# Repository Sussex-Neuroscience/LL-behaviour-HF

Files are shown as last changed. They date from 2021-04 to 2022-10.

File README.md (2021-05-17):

# LL-behaviour-HF

a behavioural control system for head fixed mice

The task:

- At the start there is a 10 sec interval without a stimulus to record baseline activity. Then the mouse sees a stimulus (always the same drifting grating) which appears randomly either on the left or the right screen. after 5 sec. of stimulus presentation the actuator moves the lick sensors in front of the mouse for two sec. in which the mouse has to report on which side the stimulus is present, hence lick left or right. If the answer is correct a reward is given (solenoid valves). If the answer is incorrect no reward is given. The actuator retracts the lick sensors after 2 sec. either way. Then there is an inter trial interval for 5+ sec before the next stimulus will be presented. If the mouse was incorrect the stimulus will be presented on the same side as the trial before until the mouse makes the correct decision (to avoid bias).I might want to change the timeframes for the different stages depending on how the training goes.

- There will also be a second task where stimuli are presented on both sides on the screen (differing in orientation or contrast) and the animal has to decide which of the stimuli is the correct one. The time course will be the same, it is just the task that is changing.

- The stimulus orientation, size, contrast, frequencies etc. will be different for every mouse but will be the same throughout the training sessions, so there is only 1 type of stimulus in the first task and 2 type of stimuli in the second task. 

- The random stimulus presentation isn't in the code yet. So far, there was no task for the animal, so we always displayed the same stimulus on both sides simultaneously by mirroring one screen to the other. I'll have another chat with Antonio today to see how trivial it is to change that towards what I need.

- As for the scanimage channels. Yes, I was talking about the analog inputs. The DAQ has a lot of free slots left and I guess there are free digital inputs. I'm not too familiar with setting these things up.

- If everything works just using the labjack that would be great. We have an Arduino uno lying around just in case it is needed.

---

schematics on how the system is working and how it should work:

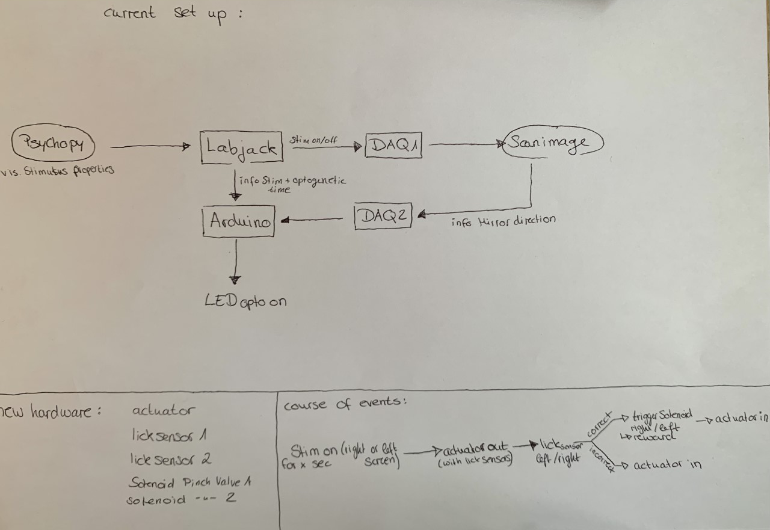
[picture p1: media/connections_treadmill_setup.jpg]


--- 

### notes on implementation:

from what I could gather, Psychopy is not indicated to do millisecond precision of many different variables at once. I had a look on how it deals with timing (more info [here](https://www.psychopy.org/_modules/psychopy/clock.html#Clock)), and thinking that a good route would be to do the behavioural timing critical things on the ESP32.

---

initial bill of materials:

|||
|---|---|
|Linear actuator||
|solenoid valves||
|lick sensors||
|beehive main board||
|beehive peltier board||
|beehive solenoid valve board||
|||

---

software needed to run the esp32
REPL
esp32 micropython firmware
adafruit Ampy

---

notes from the first installation session:

- the Optogenetics LED is controlled by a Thorlabs DC2200 interface. It gets its signals from an arduino box, which in principle can be bypassed since we are already using a microcontroller to take care of the behavioural task.
- from labjack to scanimage there are 2 signals timewave and twoptrigger.

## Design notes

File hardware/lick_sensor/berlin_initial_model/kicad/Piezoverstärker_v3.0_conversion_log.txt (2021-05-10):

#********** START OF run-me-first-from-eagle-sch.ulp ULP Version 4.4.5 06-05-2021 :19:24:03 LOG **********#
    Conversion completed with no Messages
#********** END OF run-me-first-from-eagle-sch.ulp ULP Version 4.4.5 06-05-2021 :19:24:03 LOG **********#

#********** START OF fix_via_hack.ulp ULP Version 4.8.1 06-05-2021 :19:26:07 LOG **********#
TRACK	WireCount=1		Net=+12V				start(X=-126540.000000 Y=46990.000000)	end(X=-131445.000000 Y=1210.000000 )
TRACK	WireCount=2		Net=+12V				start(X=-129540.000000 Y=65870.000000)	end(X=-126540.000000 Y=46990.000000 )
TRACK	WireCount=3		Net=+12V				start(X=-114300.000000 Y=65870.000000)	end(X=-129540.000000 Y=65870.000000 )
TRACK	WireCount=4		Net=+12V				start(X=-79690.000000 Y=88900.000000)	end(X=-114300.000000 Y=65870.000000 )
TRACK	WireCount=5		Net=+12V				start(X=-71440.000000 Y=88900.000000)	end(X=-79690.000000 Y=88900.000000 )
TRACK	WireCount=6		Net=+12V				start(X=-58740.000000 Y=88900.000000)	end(X=-71440.000000 Y=88900.000000 )
TRACK	WireCount=7		Net=+12V				start(X=-39690.000000 Y=88900.000000)	end(X=-58740.000000 Y=88900.000000 )
TRACK	WireCount=8		Net=+12V				start(X=-40960.000000 Y=96520.000000)	end(X=-39690.000000 Y=88900.000000 )
TRACK	WireCount=9		Net=+12V				start(X=-44770.000000 Y=109220.000000)	end(X=-40960.000000 Y=96520.000000 )
TRACK	WireCount=10		Net=+12V				start(X=-26350.000000 Y=109220.000000)	end(X=-44770.000000 Y=109220.000000 )
TRACK	WireCount=11		Net=+12V				start(X=-46140.000000 Y=134620.000000)	end(X=-44770.000000 Y=109220.000000 )
TRACK	WireCount=12		Net=+12V				start(X=-41060.000000 Y=134620.000000)	end(X=-46140.000000 Y=134620.000000 )
TRACK	WireCount=13		Net=+12V				start(X=-57785.000000 Y=48320.000000)	end(X=-58740.000000 Y=88900.000000 )
TRACK	WireCount=14		Net=+12V				start(X=-60960.000000 Y=35560.000000)	end(X=-57785.000000 Y=48320.000000 )
TRACK	WireCount=15		Net=+12V				start(X=-44450.000000 Y=43120.000000)	end(X=-57785.000000 Y=48320.000000 )
TRACK	WireCount=16		Net=+12V				start(X=-30480.000000 Y=43120.000000)	end(X=-44450.000000 Y=43120.000000 )
TRACK	WireCount=17		Net=+12V				start(X=-19685.000000 Y=40335.200000)	end(X=-30480.000000 Y=43120.000000 )
TRACK	WireCount=18		Net=+12VDC_DIRTY				start(X=-71660.000000 Y=46990.000000)	end(X=-131445.000000 Y=6410.000000 )
TRACK	WireCount=19		Net=+12VDC_DIRTY				start(X=-23810.000000 Y=96520.000000)	end(X=-71660.000000 Y=46990.000000 )
TRACK	WireCount=20		Net=+12VDC_DIRTY				start(X=-129220.000000 Y=102870.000000)	end(X=-71660.000000 Y=46990.000000 )
TRACK	WireCount=21		Net=+12VDC_DIRTY				start(X=-118960.000000 Y=121920.000000)	end(X=-129220.000000 Y=102870.000000 )
TRACK	WireCount=22		Net=-12V				start(X=-116380.000000 Y=46990.000000)	end(X=-100965.000000 Y=1210.000000 )
TRACK	WireCount=23		Net=-12V				start(X=-120970.000000 Y=63670.000000)	end(X=-116380.000000 Y=46990.000000 )
TRACK	WireCount=24		Net=-12V				start(X=-122870.000000 Y=63670.000000)	end(X=-120970.000000 Y=63670.000000 )
TRACK	WireCount=25		Net=-12V				start(X=-111440.000000 Y=88900.000000)	end(X=-120970.000000 Y=63670.000000 )
TRACK	WireCount=26		Net=-12V				start(X=-86040.000000 Y=88900.000000)	end(X=-111440.000000 Y=88900.000000 )
TRACK	WireCount=27		Net=-12V				start(X=-54290.000000 Y=88900.000000)	end(X=-86040.000000 Y=88900.000000 )
TRACK	WireCount=28		Net=-12V				start(X=-47940.000000 Y=88900.000000)	end(X=-54290.000000 Y=88900.000000 )
TRACK	WireCount=29		Net=-12V				start(X=-49210.000000 Y=96520.000000)	end(X=-47940.000000 Y=88900.000000 )
TRACK	WireCount=30		Net=-12V				start(X=-51750.000000 Y=109220.000000)	end(X=-49210.000000 Y=96520.000000 )
TRACK	WireCount=31		Net=-12V				start(X=-55460.000000 Y=115570.000000)	end(X=-51750.000000 Y=109220.000000 )
TRACK	WireCount=32		Net=-12V				start(X=-61810.000000 Y=115570.000000)	end(X=-55460.000000 Y=115570.000000 )
TRACK	WireCount=33		Net=-12V				start(X=-21270.000000 Y=109220.000000)	end(X=-51750.000000 Y=109220.000000 )
TRACK	WireCount=34		Net=-12V				start(X=-18730.000000 Y=72560.000000)	end(X=-47940.000000 Y=88900.000000 )
TRACK	WireCount=35		Net=-12V				start(X=-16830.000000 Y=72560.000000)	end(X=-18730.000000 Y=72560.000000 )
TRACK	WireCount=36		Net=-12V				start(X=-30480.000000 Y=48320.000000)	end(X=-18730.000000 Y=72560.000000 )
TRACK	WireCount=37		Net=-12V				start(X=-44450.000000 Y=48320.000000)	end(X=-30480.000000 Y=48320.000000 )
TRACK	WireCount=38		Net=-12V				start(X=-53975.000000 Y=43120.000000)	end(X=-44450.000000 Y=48320.000000 )
TRACK	WireCount=39		Net=-12V				start(X=-15875.000000 Y=30784.800000)	end(X=-30480.000000 Y=48320.000000 )
TRACK	WireCount=40		Net=DIFF_+				start(X=-68160.000000 Y=115570.000000)	end(X=-66460.000000 Y=134620.000000 )
TRACK	WireCount=41		Net=DIFF_+				start(X=-98640.000000 Y=115570.000000)	end(X=-68160.000000 Y=115570.000000 )
TRACK	WireCount=42		Net=DIFF_+				start(X=-128590.000000 Y=63670.000000)	end(X=-98640.000000 Y=115570.000000 )
TRACK	WireCount=43		Net=DIFF_+				start(X=-130490.000000 Y=63670.000000)	end(X=-128590.000000 Y=63670.000000 )
TRACK	WireCount=44		Net=DIFF_+				start(X=-17780.000000 Y=74760.000000)	end(X=-68160.000000 Y=115570.000000 )
TRACK	WireCount=45		Net=DIFF_-				start(X=-74510.000000 Y=115570.000000)	end(X=-61380.000000 Y=134620.000000 )
TRACK	WireCount=46		Net=DIFF_-				start(X=-102020.000000 Y=115570.000000)	end(X=-74510.000000 Y=115570.000000 )
TRACK	WireCount=47		Net=DIFF_-				start(X=-113350.000000 Y=63670.000000)	end(X=-102020.000000 Y=115570.000000 )
TRACK	WireCount=48		Net=DIFF_-				start(X=-115250.000000 Y=63670.000000)	end(X=-113350.000000 Y=63670.000000 )
TRACK	WireCount=49		Net=DIFF_-				start(X=-121920.000000 Y=65870.000000)	end(X=-115250.000000 Y=63670.000000 )
TRACK	WireCount=50		Net=GND				start(X=-128905.000000 Y=1210.000000)	end(X=-130175.000000 Y=1210.000000 )
TRACK	WireCount=51		Net=GND				start(X=-130175.000000 Y=6410.000000)	end(X=-130175.000000 Y=1210.000000 )
TRACK	WireCount=52		Net=GND				start(X=-128905.000000 Y=6410.000000)	end(X=-130175.000000 Y=6410.000000 )
TRACK	WireCount=53		Net=GND				start(X=-97155.000000 Y=6410.000000)	end(X=-128905.000000 Y=6410.000000 )
TRACK	WireCount=54		Net=GND				start(X=-70150.000000 Y=8990.000000)	end(X=-97155.000000 Y=6410.000000 )
TRACK	WireCount=55		Net=GND				start(X=-70150.000000 Y=3390.000000)	end(X=-70150.000000 Y=8990.000000 )
TRACK	WireCount=56		Net=GND				start(X=-69000.000000 Y=2240.000000)	end(X=-70150.000000 Y=3390.000000 )
TRACK	WireCount=57		Net=GND				start(X=-63400.000000 Y=2240.000000)	end(X=-69000.000000 Y=2240.000000 )
TRACK	WireCount=58		Net=GND				start(X=-57150.000000 Y=2240.000000)	end(X=-63400.000000 Y=2240.000000 )
TRACK	WireCount=59		Net=GND				start(X=-70150.000000 Y=15240.000000)	end(X=-70150.000000 Y=8990.000000 )
TRACK	WireCount=60		Net=GND				start(X=-50900.000000 Y=2240.000000)	end(X=-57150.000000 Y=2240.000000 )
TRACK	WireCount=61		Net=GND				start(X=-45300.000000 Y=2240.000000)	end(X=-50900.000000 Y=2240.000000 )
TRACK	WireCount=62		Net=GND				start(X=-44150.000000 Y=3390.000000)	end(X=-45300.000000 Y=2240.000000 )
TRACK	WireCount=63		Net=GND				start(X=-40940.000000 Y=3390.000000)	end(X=-44150.000000 Y=3390.000000 )
TRACK	WireCount=64		Net=GND				start(X=-39790.000000 Y=2240.000000)	end(X=-40940.000000 Y=3390.000000 )
TRACK	WireCount=65		Net=GND				start(X=-44150.000000 Y=8990.000000)	end(X=-44150.000000 Y=3390.000000 )
TRACK	WireCount=66		Net=GND				start(X=-40940.000000 Y=8990.000000)	end(X=-44150.000000 Y=8990.000000 )
TRACK	WireCount=67		Net=GND				start(X=-34190.000000 Y=2240.000000)	end(X=-39790.000000 Y=2240.000000 )
TRACK	WireCount=68		Net=GND				start(X=-70150.000000 Y=21490.000000)	end(X=-70150.000000 Y=15240.000000 )
TRACK	WireCount=69		Net=GND				start(X=-70150.000000 Y=27090.000000)	end(X=-70150.000000 Y=21490.000000 )
TRACK	WireCount=70		Net=GND				start(X=-69000.000000 Y=28240.000000)	end(X=-70150.000000 Y=27090.000000 )
TRACK	WireCount=71		Net=GND				start(X=-63400.000000 Y=28240.000000)	end(X=-69000.000000 Y=28240.000000 )
TRACK	WireCount=72		Net=GND				start(X=-27940.000000 Y=2240.000000)	end(X=-34190.000000 Y=2240.000000 )
TRACK	WireCount=73		Net=GND				start(X=-44150.000000 Y=15240.000000)	end(X=-44150.000000 Y=8990.000000 )
TRACK	WireCount=74		Net=GND				start(X=-40940.000000 Y=15240.000000)	end(X=-44150.000000 Y=15240.000000 )
TRACK	WireCount=75		Net=GND				start(X=-57150.000000 Y=28240.000000)	end(X=-63400.000000 Y=28240.000000 )
TRACK	WireCount=76		Net=GND				start(X=-44150.000000 Y=21490.000000)	end(X=-44150.000000 Y=15240.000000 )
TRACK	WireCount=77		Net=GND				start(X=-40940.000000 Y=21490.000000)	end(X=-44150.000000 Y=21490.000000 )
TRACK	WireCount=78		Net=GND				start(X=-44150.000000 Y=27090.000000)	end(X=-44150.000000 Y=21490.000000 )
TRACK	WireCount=79		Net=GND				start(X=-45300.000000 Y=28240.000000)	end(X=-44150.000000 Y=27090.000000 )
TRACK	WireCount=80		Net=GND				start(X=-40940.000000 Y=27090.000000)	end(X=-44150.000000 Y=27090.000000 )
TRACK	WireCount=81		Net=GND				start(X=-39790.000000 Y=28240.000000)	end(X=-40940.000000 Y=27090.000000 )
TRACK	WireCount=82		Net=GND				start(X=-50900.000000 Y=28240.000000)	end(X=-45300.000000 Y=28240.000000 )
TRACK	WireCount=83		Net=GND				start(X=-34190.000000 Y=28240.000000)	end(X=-39790.000000 Y=28240.000000 )
TRACK	WireCount=84		Net=GND				start(X=-32385.000000 Y=31690.000000)	end(X=-34190.000000 Y=28240.000000 )
TRACK	WireCount=85		Net=GND				start(X=-27940.000000 Y=28240.000000)	end(X=-32385.000000 Y=31690.000000 )
TRACK	WireCount=86		Net=GND				start(X=-23495.000000 Y=30784.800000)	end(X=-27940.000000 Y=28240.000000 )
TRACK	WireCount=87		Net=GND				start(X=-20955.000000 Y=30784.800000)	end(X=-23495.000000 Y=30784.800000 )
TRACK	WireCount=88		Net=GND				start(X=-21690.000000 Y=28240.000000)	end(X=-20955.000000 Y=30784.800000 )
TRACK	WireCount=89		Net=GND				start(X=-17145.000000 Y=30784.800000)	end(X=-20955.000000 Y=30784.800000 )
TRACK	WireCount=90		Net=GND				start(X=-14605.000000 Y=30784.800000)	end(X=-17145.000000 Y=30784.800000 )
TRACK	WireCount=91		Net=GND				start(X=-16090.000000 Y=28240.000000)	end(X=-17145.000000 Y=30784.800000 )
TRACK	WireCount=92		Net=GND				start(X=-14940.000000 Y=27090.000000)	end(X=-16090.000000 Y=28240.000000 )
TRACK	WireCount=93		Net=GND				start(X=-14940.000000 Y=21490.000000)	end(X=-14940.000000 Y=27090.000000 )
TRACK	WireCount=94		Net=GND				start(X=-21690.000000 Y=2240.000000)	end(X=-27940.000000 Y=2240.000000 )
TRACK	WireCount=95		Net=GND				start(X=-16090.000000 Y=2240.000000)	end(X=-21690.000000 Y=2240.000000 )
TRACK	WireCount=96		Net=GND				start(X=-14940.000000 Y=3390.000000)	end(X=-16090.000000 Y=2240.000000 )
TRACK	WireCount=97		Net=GND				start(X=-14940.000000 Y=8990.000000)	end(X=-14940.000000 Y=3390.000000 )
TRACK	WireCount=98		Net=GND				start(X=-14940.000000 Y=15240.000000)	end(X=-14940.000000 Y=21490.000000 )
TRACK	WireCount=99		Net=GND				start(X=-66040.000000 Y=35560.000000)	end(X=-63400.000000 Y=28240.000000 )
TRACK	WireCount=100		Net=GND				start(X=-14605.000000 Y=40335.200000)	end(X=-14605.000000 Y=30784.800000 )
TRACK	WireCount=101		Net=GND				start(X=-15875.000000 Y=40335.200000)	end(X=-14605.000000 Y=40335.200000 )
TRACK	WireCount=102		Net=GND				start(X=-20955.000000 Y=40335.200000)	end(X=-15875.000000 Y=40335.200000 )
TRACK	WireCount=103		Net=GND				start(X=-23495.000000 Y=40335.200000)	end(X=-20955.000000 Y=40335.200000 )
TRACK	WireCount=104		Net=GND				start(X=-29210.000000 Y=43120.000000)	end(X=-23495.000000 Y=40335.200000 )
TRACK	WireCount=105		Net=GND				start(X=-31750.000000 Y=43120.000000)	end(X=-29210.000000 Y=43120.000000 )
TRACK	WireCount=106		Net=GND				start(X=-39370.000000 Y=39370.000000)	end(X=-31750.000000 Y=43120.000000 )
TRACK	WireCount=107		Net=GND				start(X=-43180.000000 Y=48320.000000)	end(X=-39370.000000 Y=39370.000000 )
TRACK	WireCount=108		Net=GND				start(X=-45720.000000 Y=48320.000000)	end(X=-43180.000000 Y=48320.000000 )
TRACK	WireCount=109		Net=GND				start(X=-80010.000000 Y=35560.000000)	end(X=-70150.000000 Y=27090.000000 )
TRACK	WireCount=110		Net=GND				start(X=-85090.000000 Y=35560.000000)	end(X=-80010.000000 Y=35560.000000 )
TRACK	WireCount=111		Net=GND				start(X=-87630.000000 Y=35560.000000)	end(X=-85090.000000 Y=35560.000000 )
TRACK	WireCount=112		Net=GND				start(X=-31750.000000 Y=57150.000000)	end(X=-31750.000000 Y=43120.000000 )
TRACK	WireCount=113		Net=GND				start(X=-39370.000000 Y=66040.000000)	end(X=-31750.000000 Y=57150.000000 )
TRACK	WireCount=114		Net=GND				start(X=-87630.000000 Y=57150.000000)	end(X=-87630.000000 Y=35560.000000 )
TRACK	WireCount=115		Net=GND				start(X=-83500.000000 Y=63670.000000)	end(X=-87630.000000 Y=57150.000000 )
TRACK	WireCount=116		Net=GND				start(X=-81600.000000 Y=63670.000000)	end(X=-83500.000000 Y=63670.000000 )
TRACK	WireCount=117		Net=GND				start(X=-91440.000000 Y=65870.000000)	end(X=-83500.000000 Y=63670.000000 )
TRACK	WireCount=118		Net=GND				start(X=-73660.000000 Y=65870.000000)	end(X=-81600.000000 Y=63670.000000 )
TRACK	WireCount=119		Net=GND				start(X=-65720.000000 Y=63670.000000)	end(X=-73660.000000 Y=65870.000000 )
TRACK	WireCount=120		Net=GND				start(X=-63820.000000 Y=63670.000000)	end(X=-65720.000000 Y=63670.000000 )
TRACK	WireCount=121		Net=GND				start(X=-101580.000000 Y=71160.000000)	end(X=-91440.000000 Y=65870.000000 )
TRACK	WireCount=122		Net=GND				start(X=-110470.000000 Y=71160.000000)	end(X=-101580.000000 Y=71160.000000 )
TRACK	WireCount=123		Net=GND				start(X=-119360.000000 Y=71160.000000)	end(X=-110470.000000 Y=71160.000000 )
TRACK	WireCount=124		Net=GND				start(X=-118110.000000 Y=57150.000000)	end(X=-119360.000000 Y=71160.000000 )
TRACK	WireCount=125		Net=GND				start(X=-122380.000000 Y=46990.000000)	end(X=-118110.000000 Y=57150.000000 )
TRACK	WireCount=126		Net=GND				start(X=-132540.000000 Y=46990.000000)	end(X=-122380.000000 Y=46990.000000 )
TRACK	WireCount=127		Net=GND				start(X=-109540.000000 Y=88900.000000)	end(X=-110470.000000 Y=71160.000000 )
TRACK	WireCount=128		Net=GND				start(X=-117790.000000 Y=88900.000000)	end(X=-109540.000000 Y=88900.000000 )
TRACK	WireCount=129		Net=GND				start(X=-122240.000000 Y=88900.000000)	end(X=-117790.000000 Y=88900.000000 )
TRACK	WireCount=130		Net=GND				start(X=-130490.000000 Y=88900.000000)	end(X=-122240.000000 Y=88900.000000 )
TRACK	WireCount=131		Net=GND				start(X=-127320.000000 Y=102870.000000)	end(X=-130490.000000 Y=88900.000000 )
TRACK	WireCount=132		Net=GND				start(X=-129120.000000 Y=115570.000000)	end(X=-127320.000000 Y=102870.000000 )
TRACK	WireCount=133		Net=GND				start(X=-118960.000000 Y=115570.000000)	end(X=-129120.000000 Y=115570.000000 )
TRACK	WireCount=134		Net=GND				start(X=-113880.000000 Y=121920.000000)	end(X=-118960.000000 Y=115570.000000 )
TRACK	WireCount=135		Net=GND				start(X=-103720.000000 Y=115570.000000)	end(X=-113880.000000 Y=121920.000000 )
TRACK	WireCount=136		Net=GND				start(X=-96940.000000 Y=115570.000000)	end(X=-103720.000000 Y=115570.000000 )
TRACK	WireCount=137		Net=GND				start(X=-93560.000000 Y=115570.000000)	end(X=-96940.000000 Y=115570.000000 )
TRACK	WireCount=138		Net=GND				start(X=-41590.000000 Y=88900.000000)	end(X=-39370.000000 Y=66040.000000 )
TRACK	WireCount=139		Net=GND				start(X=-46040.000000 Y=88900.000000)	end(X=-41590.000000 Y=88900.000000 )
TRACK	WireCount=140		Net=GND				start(X=-52390.000000 Y=88900.000000)	end(X=-46040.000000 Y=88900.000000 )
TRACK	WireCount=141		Net=GND				start(X=-42860.000000 Y=96520.000000)	end(X=-41590.000000 Y=88900.000000 )
TRACK	WireCount=142		Net=GND				start(X=-47310.000000 Y=96520.000000)	end(X=-42860.000000 Y=96520.000000 )
TRACK	WireCount=143		Net=GND				start(X=-60640.000000 Y=88900.000000)	end(X=-52390.000000 Y=88900.000000 )
TRACK	WireCount=144		Net=GND				start(X=-46670.000000 Y=109220.000000)	end(X=-47310.000000 Y=96520.000000 )
TRACK	WireCount=145		Net=GND				start(X=-49850.000000 Y=109220.000000)	end(X=-46670.000000 Y=109220.000000 )
TRACK	WireCount=146		Net=GND				start(X=-39690.000000 Y=109220.000000)	end(X=-46670.000000 Y=109220.000000 )
TRACK	WireCount=147		Net=GND				start(X=-34610.000000 Y=109220.000000)	end(X=-39690.000000 Y=109220.000000 )
TRACK	WireCount=148		Net=GND				start(X=-34710.000000 Y=115570.000000)	end(X=-34610.000000 Y=109220.000000 )
TRACK	WireCount=149		Net=GND				start(X=-30060.000000 Y=115570.000000)	end(X=-34710.000000 Y=115570.000000 )
TRACK	WireCount=150		Net=GND				start(X=-24450.000000 Y=109220.000000)	end(X=-30060.000000 Y=115570.000000 )
TRACK	WireCount=151		Net=GND				start(X=-19370.000000 Y=109220.000000)	end(X=-24450.000000 Y=109220.000000 )
TRACK	WireCount=152		Net=GND				start(X=-16190.000000 Y=109220.000000)	end(X=-19370.000000 Y=109220.000000 )
TRACK	WireCount=153		Net=GND				start(X=-22440.000000 Y=121920.000000)	end(X=-30060.000000 Y=115570.000000 )
TRACK	WireCount=154		Net=GND				start(X=-15560.000000 Y=96520.000000)	end(X=-16190.000000 Y=109220.000000 )
TRACK	WireCount=155		Net=GND				start(X=-21910.000000 Y=96520.000000)	end(X=-15560.000000 Y=96520.000000 )
TRACK	WireCount=156		Net=GND				start(X=-28260.000000 Y=96520.000000)	end(X=-21910.000000 Y=96520.000000 )
TRACK	WireCount=157		Net=GND				start(X=-73340.000000 Y=88900.000000)	end(X=-60640.000000 Y=88900.000000 )
TRACK	WireCount=158		Net=GND				start(X=-77790.000000 Y=88900.000000)	end(X=-73340.000000 Y=88900.000000 )
TRACK	WireCount=159		Net=GND				start(X=-84140.000000 Y=88900.000000)	end(X=-77790.000000 Y=88900.000000 )
TRACK	WireCount=160		Net=N$1				start(X=-36510.000000 Y=109220.000000)	end(X=-42760.000000 Y=134620.000000 )
TRACK	WireCount=161		Net=N$1				start(X=-99060.000000 Y=65870.000000)	end(X=-36510.000000 Y=109220.000000 )
TRACK	WireCount=162		Net=N$2				start(X=-18415.000000 Y=40335.200000)	end(X=-17145.000000 Y=40335.200000 )
TRACK	WireCount=163		Net=N$2				start(X=-124040.000000 Y=115570.000000)	end(X=-18415.000000 Y=40335.200000 )
TRACK	WireCount=164		Net=N$3				start(X=-100010.000000 Y=63670.000000)	end(X=-51220.000000 Y=134620.000000 )
TRACK	WireCount=165		Net=N$4				start(X=-102060.000000 Y=46990.000000)	end(X=-52920.000000 Y=134620.000000 )
TRACK	WireCount=166		Net=N$4				start(X=-22225.000000 Y=30784.800000)	end(X=-102060.000000 Y=46990.000000 )
TRACK	WireCount=167		Net=N$5				start(X=-41590.000000 Y=109220.000000)	end(X=-47840.000000 Y=134620.000000 )
TRACK	WireCount=168		Net=N$5				start(X=-106680.000000 Y=65870.000000)	end(X=-41590.000000 Y=109220.000000 )
TRACK	WireCount=169		Net=N$6				start(X=-18415.000000 Y=30784.800000)	end(X=-68160.000000 Y=134620.000000 )
TRACK	WireCount=170		Net=N$7				start(X=-107630.000000 Y=63670.000000)	end(X=-56300.000000 Y=134620.000000 )
TRACK	WireCount=171		Net=N$8				start(X=-87650.000000 Y=81280.000000)	end(X=-103720.000000 Y=128270.000000 )
TRACK	WireCount=172		Net=N$9				start(X=-19685.000000 Y=30784.800000)	end(X=-63080.000000 Y=134620.000000 )
TRACK	WireCount=173		Net=N$10				start(X=-90150.000000 Y=83780.000000)	end(X=-46140.000000 Y=128270.000000 )
TRACK	WireCount=174		Net=N$11				start(X=-72810.000000 Y=115570.000000)	end(X=-55880.000000 Y=107950.000000 )
TRACK	WireCount=175		Net=N$12				start(X=-66460.000000 Y=115570.000000)	end(X=-30480.000000 Y=87630.000000 )
TRACK	WireCount=176		Net=N$13				start(X=-53975.000000 Y=48320.000000)	end(X=-99080.000000 Y=73660.000000 )
TRACK	WireCount=177		Net=N$14				start(X=-58420.000000 Y=57150.000000)	end(X=-96060.000000 Y=46990.000000 )
TRACK	WireCount=178		Net=N$15				start(X=-34290.000000 Y=43120.000000)	end(X=-25400.000000 Y=88900.000000 )
TRACK	WireCount=179		Net=N$15				start(X=-113030.000000 Y=81280.000000)	end(X=-34290.000000 Y=43120.000000 )
TRACK	WireCount=180		Net=N$16				start(X=-54930.000000 Y=63670.000000)	end(X=-28360.000000 Y=115570.000000 )
TRACK	WireCount=181		Net=N$16				start(X=-56830.000000 Y=63670.000000)	end(X=-54930.000000 Y=63670.000000 )
TRACK	WireCount=182		Net=N$16				start(X=-26670.000000 Y=48320.000000)	end(X=-54930.000000 Y=63670.000000 )
TRACK	WireCount=183		Net=N$17				start(X=-15240.000000 Y=88900.000000)	end(X=-35980.000000 Y=134620.000000 )
TRACK	WireCount=184		Net=N$17				start(X=-117690.000000 Y=109220.000000)	end(X=-35980.000000 Y=134620.000000 )
TRACK	WireCount=185		Net=N$18				start(X=-108800.000000 Y=115570.000000)	end(X=-82550.000000 Y=35560.000000 )
TRACK	WireCount=186		Net=N$19				start(X=-46990.000000 Y=39370.000000)	end(X=-92170.000000 Y=46990.000000 )
TRACK	WireCount=187		Net=N$19				start(X=-128590.000000 Y=88900.000000)	end(X=-92170.000000 Y=46990.000000 )
TRACK	WireCount=188		Net=N$20				start(X=-122340.000000 Y=109220.000000)	end(X=-130390.000000 Y=109220.000000 )
TRACK	WireCount=189		Net=N$21				start(X=-23710.000000 Y=115570.000000)	end(X=-15660.000000 Y=115570.000000 )
TRACK	WireCount=190		Net=N$22				start(X=-36410.000000 Y=115570.000000)	end(X=-22010.000000 Y=115570.000000 )
TRACK	WireCount=191		Net=N$22				start(X=-80860.000000 Y=115570.000000)	end(X=-36410.000000 Y=115570.000000 )
TRACK	WireCount=192		Net=N$22				start(X=-34290.000000 Y=57150.000000)	end(X=-36410.000000 Y=115570.000000 )
TRACK	WireCount=193		Net=N$22				start(X=-29210.000000 Y=48320.000000)	end(X=-34290.000000 Y=57150.000000 )
TRACK	WireCount=194		Net=N$22				start(X=-26670.000000 Y=43120.000000)	end(X=-29210.000000 Y=48320.000000 )
TRACK	WireCount=195		Net=N$23				start(X=-15560.000000 Y=102870.000000)	end(X=-17360.000000 Y=115570.000000 )
TRACK	WireCount=196		Net=N$23				start(X=-28260.000000 Y=102870.000000)	end(X=-15560.000000 Y=102870.000000 )
TRACK	WireCount=197		Net=N$23				start(X=-40960.000000 Y=102870.000000)	end(X=-28260.000000 Y=102870.000000 )
TRACK	WireCount=198		Net=N$23				start(X=-53660.000000 Y=102870.000000)	end(X=-40960.000000 Y=102870.000000 )
TRACK	WireCount=199		Net=N$23				start(X=-60010.000000 Y=96520.000000)	end(X=-53660.000000 Y=102870.000000 )
TRACK	WireCount=200		Net=N$23				start(X=-65090.000000 Y=88900.000000)	end(X=-60010.000000 Y=96520.000000 )
TRACK	WireCount=201		Net=N$23				start(X=-72710.000000 Y=96520.000000)	end(X=-65090.000000 Y=88900.000000 )
TRACK	WireCount=202		Net=N$23				start(X=-71440.000000 Y=102870.000000)	end(X=-72710.000000 Y=96520.000000 )
TRACK	WireCount=203		Net=N$23				start(X=-76520.000000 Y=102870.000000)	end(X=-71440.000000 Y=102870.000000 )
TRACK	WireCount=204		Net=N$23				start(X=-81600.000000 Y=102870.000000)	end(X=-76520.000000 Y=102870.000000 )
TRACK	WireCount=205		Net=N$23				start(X=-86680.000000 Y=102870.000000)	end(X=-81600.000000 Y=102870.000000 )
TRACK	WireCount=206		Net=N$23				start(X=-91760.000000 Y=102870.000000)	end(X=-86680.000000 Y=102870.000000 )
TRACK	WireCount=207		Net=N$23				start(X=-96840.000000 Y=102870.000000)	end(X=-91760.000000 Y=102870.000000 )
TRACK	WireCount=208		Net=N$23				start(X=-101920.000000 Y=102870.000000)	end(X=-96840.000000 Y=102870.000000 )
TRACK	WireCount=209		Net=N$23				start(X=-107000.000000 Y=102870.000000)	end(X=-101920.000000 Y=102870.000000 )
TRACK	WireCount=210		Net=N$23				start(X=-112080.000000 Y=102870.000000)	end(X=-107000.000000 Y=102870.000000 )
TRACK	WireCount=211		Net=N$23				start(X=-117160.000000 Y=102870.000000)	end(X=-112080.000000 Y=102870.000000 )
TRACK	WireCount=212		Net=N$23				start(X=-122240.000000 Y=102870.000000)	end(X=-117160.000000 Y=102870.000000 )
TRACK	WireCount=213		Net=N$23				start(X=-123510.000000 Y=96520.000000)	end(X=-122240.000000 Y=102870.000000 )
TRACK	WireCount=214		Net=N$23				start(X=-85410.000000 Y=96520.000000)	end(X=-86680.000000 Y=102870.000000 )
TRACK	WireCount=215		Net=N$23				start(X=-110810.000000 Y=96520.000000)	end(X=-112080.000000 Y=102870.000000 )
TRACK	WireCount=216		Net=N$23				start(X=-115990.000000 Y=109220.000000)	end(X=-117160.000000 Y=102870.000000 )
TRACK	WireCount=217		Net=N$23				start(X=-98110.000000 Y=96520.000000)	end(X=-96840.000000 Y=102870.000000 )
TRACK	WireCount=218		Net=N$23				start(X=-128690.000000 Y=109220.000000)	end(X=-122240.000000 Y=102870.000000 )
TRACK	WireCount=219		Net=N$23				start(X=-27940.000000 Y=43120.000000)	end(X=-65090.000000 Y=88900.000000 )
TRACK	WireCount=220		Net=N$24				start(X=-66990.000000 Y=88900.000000)	end(X=-53660.000000 Y=96520.000000 )
TRACK	WireCount=221		Net=N$24				start(X=-73340.000000 Y=102870.000000)	end(X=-66990.000000 Y=88900.000000 )
TRACK	WireCount=222		Net=N$25				start(X=-93660.000000 Y=96520.000000)	end(X=-101600.000000 Y=35560.000000 )
TRACK	WireCount=223		Net=N$27				start(X=-66360.000000 Y=96520.000000)	end(X=-61910.000000 Y=96520.000000 )
TRACK	WireCount=224		Net=N$27				start(X=-78420.000000 Y=102870.000000)	end(X=-66360.000000 Y=96520.000000 )
TRACK	WireCount=225		Net=N$28				start(X=-99040.000000 Y=83780.000000)	end(X=-41060.000000 Y=128270.000000 )
TRACK	WireCount=226		Net=N$29				start(X=-107930.000000 Y=83780.000000)	end(X=-51220.000000 Y=128270.000000 )
TRACK	WireCount=227		Net=N$30				start(X=-71120.000000 Y=35560.000000)	end(X=-79160.000000 Y=115570.000000 )
TRACK	WireCount=228		Net=N$31				start(X=-85510.000000 Y=115570.000000)	end(X=-68580.000000 Y=35560.000000 )
TRACK	WireCount=229		Net=N$32				start(X=-117260.000000 Y=121920.000000)	end(X=-35980.000000 Y=121920.000000 )
TRACK	WireCount=230		Net=N$32				start(X=-119360.000000 Y=76160.000000)	end(X=-117260.000000 Y=121920.000000 )
TRACK	WireCount=231		Net=N$32				start(X=-33655.000000 Y=31690.000000)	end(X=-35980.000000 Y=121920.000000 )
TRACK	WireCount=232		Net=N$33				start(X=-101580.000000 Y=76160.000000)	end(X=-87210.000000 Y=115570.000000 )
TRACK	WireCount=233		Net=N$33				start(X=-55880.000000 Y=65870.000000)	end(X=-101580.000000 Y=76160.000000 )
TRACK	WireCount=234		Net=N$34				start(X=-72710.000000 Y=63670.000000)	end(X=-31480.000000 Y=72660.000000 )
TRACK	WireCount=235		Net=N$34				start(X=-74610.000000 Y=63670.000000)	end(X=-72710.000000 Y=63670.000000 )
TRACK	WireCount=236		Net=N$35				start(X=-44180.000000 Y=72660.000000)	end(X=-30480.000000 Y=74660.000000 )
TRACK	WireCount=237		Net=N$35				start(X=-55245.000000 Y=48320.000000)	end(X=-44180.000000 Y=72660.000000 )
TRACK	WireCount=238		Net=N$35				start(X=-56515.000000 Y=48320.000000)	end(X=-55245.000000 Y=48320.000000 )
TRACK	WireCount=239		Net=N$35				start(X=-107100.000000 Y=115570.000000)	end(X=-44180.000000 Y=72660.000000 )
TRACK	WireCount=240		Net=N$35				start(X=-127420.000000 Y=115570.000000)	end(X=-107100.000000 Y=115570.000000 )
TRACK	WireCount=241		Net=N$37				start(X=-75660.000000 Y=46990.000000)	end(X=-124140.000000 Y=88900.000000 )
TRACK	WireCount=242		Net=N$37				start(X=-41910.000000 Y=39370.000000)	end(X=-75660.000000 Y=46990.000000 )
TRACK	WireCount=243		Net=N$38				start(X=-108800.000000 Y=121920.000000)	end(X=-85090.000000 Y=57150.000000 )
TRACK	WireCount=244		Net=N$38				start(X=-112180.000000 Y=121920.000000)	end(X=-108800.000000 Y=121920.000000 )
TRACK	WireCount=245		Net=N$39				start(X=-111125.000000 Y=6410.000000)	end(X=-121285.000000 Y=6410.000000 )
TRACK	WireCount=246		Net=N$39				start(X=-130810.000000 Y=35560.000000)	end(X=-121285.000000 Y=6410.000000 )
TRACK	WireCount=247		Net=N$39				start(X=-106220.000000 Y=46990.000000)	end(X=-130810.000000 Y=35560.000000 )
TRACK	WireCount=248		Net=N$39				start(X=-92390.000000 Y=88900.000000)	end(X=-106220.000000 Y=46990.000000 )
TRACK	WireCount=249		Net=N$39				start(X=-49190.000000 Y=64770.000000)	end(X=-92390.000000 Y=88900.000000 )
TRACK	WireCount=250		Net=N$39				start(X=-36830.000000 Y=66040.000000)	end(X=-49190.000000 Y=64770.000000 )
TRACK	WireCount=251		Net=N$40				start(X=-54610.000000 Y=39370.000000)	end(X=-121285.000000 Y=1210.000000 )
TRACK	WireCount=252		Net=N$40				start(X=-98740.000000 Y=88900.000000)	end(X=-54610.000000 Y=39370.000000 )
TRACK	WireCount=253		Net=N$40				start(X=-105090.000000 Y=88900.000000)	end(X=-98740.000000 Y=88900.000000 )
TRACK	WireCount=254		Net=N$66				start(X=-66360.000000 Y=102870.000000)	end(X=-37680.000000 Y=134620.000000 )
TRACK	WireCount=255		Net=N$66				start(X=-123190.000000 Y=81280.000000)	end(X=-66360.000000 Y=102870.000000 )
TRACK	WireCount=256		Net=N$66				start(X=-33020.000000 Y=43120.000000)	end(X=-66360.000000 Y=102870.000000 )
TRACK	WireCount=257		Net=N$67				start(X=-64770.000000 Y=65870.000000)	end(X=-43180.000000 Y=74660.000000 )
TRACK	WireCount=258		Net=N$70				start(X=-20740.000000 Y=121920.000000)	end(X=-15660.000000 Y=121920.000000 )
TRACK	WireCount=259		Net=N$70				start(X=-55880.000000 Y=74660.000000)	end(X=-20740.000000 Y=121920.000000 )
TRACK	WireCount=260		Net=N$70				start(X=-69580.000000 Y=72660.000000)	end(X=-55880.000000 Y=74660.000000 )
TRACK	WireCount=261		Net=N$70				start(X=-56515.000000 Y=43120.000000)	end(X=-55880.000000 Y=74660.000000 )
TRACK	WireCount=262		Net=N$70				start(X=-57785.000000 Y=43120.000000)	end(X=-56515.000000 Y=43120.000000 )
TRACK	WireCount=263		Net=N$71				start(X=-55245.000000 Y=43120.000000)	end(X=-107970.000000 Y=73660.000000 )
TRACK	WireCount=264		Net=N$72				start(X=-77470.000000 Y=35560.000000)	end(X=-17360.000000 Y=121920.000000 )
TRACK	WireCount=265		Net=N$73				start(X=-91860.000000 Y=115570.000000)	end(X=-63500.000000 Y=35560.000000 )
TRACK	WireCount=266		Net=N$74				start(X=-90490.000000 Y=63670.000000)	end(X=-92390.000000 Y=63670.000000 )
TRACK	WireCount=267		Net=N$74				start(X=-56880.000000 Y=72660.000000)	end(X=-90490.000000 Y=63670.000000 )
TRACK	WireCount=268		Net=N$75				start(X=-68580.000000 Y=74660.000000)	end(X=-82550.000000 Y=65870.000000 )
TRACK	WireCount=269		Net=N$76				start(X=-85940.000000 Y=109220.000000)	end(X=-71540.000000 Y=109220.000000 )
TRACK	WireCount=270		Net=N$76				start(X=-117260.000000 Y=115570.000000)	end(X=-85940.000000 Y=109220.000000 )
TRACK	WireCount=271		Net=N$76				start(X=-33020.000000 Y=48320.000000)	end(X=-71540.000000 Y=109220.000000 )
TRACK	WireCount=272		Net=N$77				start(X=-80960.000000 Y=96520.000000)	end(X=-99060.000000 Y=35560.000000 )
TRACK	WireCount=273		Net=N$78				start(X=-96940.000000 Y=109220.000000)	end(X=-68260.000000 Y=102870.000000 )
TRACK	WireCount=274		Net=N$78				start(X=-124040.000000 Y=109220.000000)	end(X=-96940.000000 Y=109220.000000 )
TRACK	WireCount=275		Net=N$78				start(X=-110470.000000 Y=76160.000000)	end(X=-96940.000000 Y=109220.000000 )
TRACK	WireCount=276		Net=N$78				start(X=-34290.000000 Y=48320.000000)	end(X=-68260.000000 Y=102870.000000 )
TRACK	WireCount=277		Net=N$79				start(X=-103720.000000 Y=121920.000000)	end(X=-82550.000000 Y=57150.000000 )
TRACK	WireCount=278		Net=N$79				start(X=-107100.000000 Y=121920.000000)	end(X=-103720.000000 Y=121920.000000 )
TRACK	WireCount=279		Net=N$80				start(X=-122340.000000 Y=115570.000000)	end(X=-115890.000000 Y=88900.000000 )
TRACK	WireCount=280		Net=N$80				start(X=-31750.000000 Y=48320.000000)	end(X=-115890.000000 Y=88900.000000 )
TRACK	WireCount=281		Net=N$81				start(X=-102020.000000 Y=121920.000000)	end(X=-98640.000000 Y=121920.000000 )
TRACK	WireCount=282		Net=N$81				start(X=-80010.000000 Y=57150.000000)	end(X=-98640.000000 Y=121920.000000 )
TRACK	WireCount=283		Net=N$82				start(X=-96940.000000 Y=121920.000000)	end(X=-93560.000000 Y=121920.000000 )
TRACK	WireCount=284		Net=N$82				start(X=-77470.000000 Y=57150.000000)	end(X=-93560.000000 Y=121920.000000 )
TRACK	WireCount=285		Net=N$83				start(X=-91860.000000 Y=121920.000000)	end(X=-88480.000000 Y=121920.000000 )
TRACK	WireCount=286		Net=N$83				start(X=-74930.000000 Y=57150.000000)	end(X=-88480.000000 Y=121920.000000 )
TRACK	WireCount=287		Net=N$84				start(X=-86780.000000 Y=121920.000000)	end(X=-83400.000000 Y=121920.000000 )
TRACK	WireCount=288		Net=N$84				start(X=-72390.000000 Y=57150.000000)	end(X=-83400.000000 Y=121920.000000 )
TRACK	WireCount=289		Net=N$85				start(X=-81700.000000 Y=121920.000000)	end(X=-78320.000000 Y=121920.000000 )
TRACK	WireCount=290		Net=N$85				start(X=-69850.000000 Y=57150.000000)	end(X=-78320.000000 Y=121920.000000 )
TRACK	WireCount=291		Net=N$86				start(X=-76620.000000 Y=121920.000000)	end(X=-73240.000000 Y=121920.000000 )
TRACK	WireCount=292		Net=N$86				start(X=-67310.000000 Y=57150.000000)	end(X=-73240.000000 Y=121920.000000 )
TRACK	WireCount=293		Net=N$87				start(X=-71540.000000 Y=121920.000000)	end(X=-68160.000000 Y=121920.000000 )
TRACK	WireCount=294		Net=N$87				start(X=-64770.000000 Y=57150.000000)	end(X=-68160.000000 Y=121920.000000 )
TRACK	WireCount=295		Net=N$88				start(X=-66460.000000 Y=121920.000000)	end(X=-52920.000000 Y=121920.000000 )
TRACK	WireCount=296		Net=N$88				start(X=-115570.000000 Y=57150.000000)	end(X=-66460.000000 Y=121920.000000 )
TRACK	WireCount=297		Net=N$89				start(X=-51220.000000 Y=121920.000000)	end(X=-47840.000000 Y=121920.000000 )
TRACK	WireCount=298		Net=N$89				start(X=-113030.000000 Y=57150.000000)	end(X=-51220.000000 Y=121920.000000 )
TRACK	WireCount=299		Net=N$90				start(X=-46140.000000 Y=121920.000000)	end(X=-42760.000000 Y=121920.000000 )
TRACK	WireCount=300		Net=N$90				start(X=-110490.000000 Y=57150.000000)	end(X=-46140.000000 Y=121920.000000 )
TRACK	WireCount=301		Net=N$91				start(X=-113880.000000 Y=115570.000000)	end(X=-41060.000000 Y=121920.000000 )
TRACK	WireCount=302		Net=N$91				start(X=-107950.000000 Y=57150.000000)	end(X=-113880.000000 Y=115570.000000 )
TRACK	WireCount=303		Net=N$92				start(X=-112180.000000 Y=115570.000000)	end(X=-27520.000000 Y=121920.000000 )
TRACK	WireCount=304		Net=N$92				start(X=-105410.000000 Y=57150.000000)	end(X=-112180.000000 Y=115570.000000 )
TRACK	WireCount=305		Net=N$93				start(X=-32600.000000 Y=121920.000000)	end(X=-25820.000000 Y=121920.000000 )
TRACK	WireCount=306		Net=N$93				start(X=-102870.000000 Y=57150.000000)	end(X=-32600.000000 Y=121920.000000 )
TRACK	WireCount=307		Net=N$94				start(X=-58000.000000 Y=121920.000000)	end(X=-30900.000000 Y=121920.000000 )
TRACK	WireCount=308		Net=N$94				start(X=-100330.000000 Y=57150.000000)	end(X=-58000.000000 Y=121920.000000 )
TRACK	WireCount=309		Net=N$95				start(X=-63080.000000 Y=121920.000000)	end(X=-56300.000000 Y=121920.000000 )
TRACK	WireCount=310		Net=N$95				start(X=-97790.000000 Y=57150.000000)	end(X=-63080.000000 Y=121920.000000 )
TRACK	WireCount=311		Net=N$96				start(X=-61380.000000 Y=121920.000000)	end(X=-37680.000000 Y=121920.000000 )
TRACK	WireCount=312		Net=N$96				start(X=-95250.000000 Y=57150.000000)	end(X=-61380.000000 Y=121920.000000 )
TRACK	WireCount=313		Net=N$97				start(X=-33655.000000 Y=36890.000000)	end(X=-116860.000000 Y=73660.000000 )
TRACK	WireCount=314		Net=N$98				start(X=-79060.000000 Y=96520.000000)	end(X=-74610.000000 Y=96520.000000 )
TRACK	WireCount=315		Net=N$98				start(X=-83500.000000 Y=102870.000000)	end(X=-79060.000000 Y=96520.000000 )
TRACK	WireCount=316		Net=N$99				start(X=-68260.000000 Y=96520.000000)	end(X=-96520.000000 Y=35560.000000 )
TRACK	WireCount=317		Net=N$100				start(X=-87310.000000 Y=96520.000000)	end(X=-88580.000000 Y=102870.000000 )
TRACK	WireCount=318		Net=N$100				start(X=-91760.000000 Y=96520.000000)	end(X=-87310.000000 Y=96520.000000 )
TRACK	WireCount=319		Net=N$101				start(X=-55560.000000 Y=96520.000000)	end(X=-93980.000000 Y=35560.000000 )
TRACK	WireCount=320		Net=N$102				start(X=-47840.000000 Y=128270.000000)	end(X=-42760.000000 Y=128270.000000 )
TRACK	WireCount=321		Net=N$102				start(X=-52920.000000 Y=128270.000000)	end(X=-47840.000000 Y=128270.000000 )
TRACK	WireCount=322		Net=N$102				start(X=-58000.000000 Y=128270.000000)	end(X=-52920.000000 Y=128270.000000 )
TRACK	WireCount=323		Net=N$102				start(X=-63080.000000 Y=128270.000000)	end(X=-58000.000000 Y=128270.000000 )
TRACK	WireCount=324		Net=N$102				start(X=-68160.000000 Y=128270.000000)	end(X=-63080.000000 Y=128270.000000 )
TRACK	WireCount=325		Net=N$102				start(X=-73240.000000 Y=128270.000000)	end(X=-68160.000000 Y=128270.000000 )
TRACK	WireCount=326		Net=N$102				start(X=-78320.000000 Y=128270.000000)	end(X=-73240.000000 Y=128270.000000 )
TRACK	WireCount=327		Net=N$102				start(X=-83400.000000 Y=128270.000000)	end(X=-78320.000000 Y=128270.000000 )
TRACK	WireCount=328		Net=N$102				start(X=-88480.000000 Y=128270.000000)	end(X=-83400.000000 Y=128270.000000 )
TRACK	WireCount=329		Net=N$102				start(X=-93560.000000 Y=128270.000000)	end(X=-88480.000000 Y=128270.000000 )
TRACK	WireCount=330		Net=N$102				start(X=-98640.000000 Y=128270.000000)	end(X=-93560.000000 Y=128270.000000 )
TRACK	WireCount=331		Net=N$102				start(X=-58000.000000 Y=134620.000000)	end(X=-58000.000000 Y=128270.000000 )
TRACK	WireCount=332		Net=N$102				start(X=-63480.000000 Y=78780.000000)	end(X=-63080.000000 Y=128270.000000 )
TRACK	WireCount=333		Net=N$102				start(X=-54590.000000 Y=78780.000000)	end(X=-63480.000000 Y=78780.000000 )
TRACK	WireCount=334		Net=N$102				start(X=-45700.000000 Y=78780.000000)	end(X=-54590.000000 Y=78780.000000 )
TRACK	WireCount=335		Net=N$102				start(X=-36810.000000 Y=78780.000000)	end(X=-45700.000000 Y=78780.000000 )
TRACK	WireCount=336		Net=N$102				start(X=-27920.000000 Y=78780.000000)	end(X=-36810.000000 Y=78780.000000 )
TRACK	WireCount=337		Net=N$102				start(X=-19030.000000 Y=78780.000000)	end(X=-27920.000000 Y=78780.000000 )
TRACK	WireCount=338		Net=N$102				start(X=-72370.000000 Y=78780.000000)	end(X=-63480.000000 Y=78780.000000 )
TRACK	WireCount=339		Net=N$102				start(X=-81260.000000 Y=78780.000000)	end(X=-72370.000000 Y=78780.000000 )
TRACK	WireCount=340		Net=N$102				start(X=-90150.000000 Y=78780.000000)	end(X=-81260.000000 Y=78780.000000 )
TRACK	WireCount=341		Net=N$102				start(X=-99040.000000 Y=78780.000000)	end(X=-90150.000000 Y=78780.000000 )
TRACK	WireCount=342		Net=N$102				start(X=-107930.000000 Y=78780.000000)	end(X=-99040.000000 Y=78780.000000 )
TRACK	WireCount=343		Net=N$102				start(X=-128250.000000 Y=71160.000000)	end(X=-107930.000000 Y=78780.000000 )
TRACK	WireCount=344		Net=N$102				start(X=-22225.000000 Y=40335.200000)	end(X=-19030.000000 Y=78780.000000 )
TRACK	WireCount=345		Net=N$103				start(X=-21590.000000 Y=66040.000000)	end(X=-111125.000000 Y=1210.000000 )
TRACK	WireCount=346		Net=N$103				start(X=-34610.000000 Y=96520.000000)	end(X=-21590.000000 Y=66040.000000 )
TRACK	WireCount=347		Net=N$103				start(X=-29530.000000 Y=109220.000000)	end(X=-34610.000000 Y=96520.000000 )
TRACK	WireCount=348		Net=N$104				start(X=-24130.000000 Y=66040.000000)	end(X=-77470.000000 Y=8850.000000 )
TRACK	WireCount=349		Net=N$105				start(X=-124040.000000 Y=121920.000000)	end(X=-16510.000000 Y=66040.000000 )
TRACK	WireCount=350		Net=N$106				start(X=-81280.000000 Y=74660.000000)	end(X=-79750.000000 Y=1550.000000 )
TRACK	WireCount=351		Net=N$106				start(X=-41060.000000 Y=115570.000000)	end(X=-81280.000000 Y=74660.000000 )
TRACK	WireCount=352		Net=N$106				start(X=-122340.000000 Y=121920.000000)	end(X=-81280.000000 Y=74660.000000 )
TRACK	WireCount=353		Net=N$107				start(X=-34290.000000 Y=66040.000000)	end(X=-88900.000000 Y=8850.000000 )
TRACK	WireCount=354		Net=N$108				start(X=-129120.000000 Y=121920.000000)	end(X=-31750.000000 Y=66040.000000 )
TRACK	WireCount=355		Net=N$109				start(X=-93980.000000 Y=74660.000000)	end(X=-91180.000000 Y=1550.000000 )
TRACK	WireCount=356		Net=N$109				start(X=-127420.000000 Y=121920.000000)	end(X=-93980.000000 Y=74660.000000 )
TRACK	WireCount=357		Net=N$109				start(X=-47410.000000 Y=115570.000000)	end(X=-93980.000000 Y=74660.000000 )
TRACK	WireCount=358		Net=N$110				start(X=-40640.000000 Y=43120.000000)	end(X=-20740.000000 Y=128270.000000 )
TRACK	WireCount=359		Net=N$110				start(X=-41910.000000 Y=43120.000000)	end(X=-40640.000000 Y=43120.000000 )
TRACK	WireCount=360		Net=N$111				start(X=-46990.000000 Y=43120.000000)	end(X=-15660.000000 Y=128270.000000 )
TRACK	WireCount=361		Net=N$111				start(X=-48260.000000 Y=43120.000000)	end(X=-46990.000000 Y=43120.000000 )
TRACK	WireCount=362		Net=N$112				start(X=-43180.000000 Y=43120.000000)	end(X=-17780.000000 Y=46990.000000 )
TRACK	WireCount=363		Net=N$113				start(X=-45720.000000 Y=43120.000000)	end(X=-20320.000000 Y=46990.000000 )
TRACK	WireCount=364		Net=N$114				start(X=-100010.000000 Y=96520.000000)	end(X=-93660.000000 Y=102870.000000 )
TRACK	WireCount=365		Net=N$114				start(X=-104460.000000 Y=96520.000000)	end(X=-100010.000000 Y=96520.000000 )
TRACK	WireCount=366		Net=N$115				start(X=-22440.000000 Y=128270.000000)	end(X=-17360.000000 Y=128270.000000 )
TRACK	WireCount=367		Net=N$115				start(X=-25820.000000 Y=128270.000000)	end(X=-22440.000000 Y=128270.000000 )
TRACK	WireCount=368		Net=N$115				start(X=-46990.000000 Y=48320.000000)	end(X=-25820.000000 Y=128270.000000 )
TRACK	WireCount=369		Net=N$116				start(X=-30900.000000 Y=128270.000000)	end(X=-27520.000000 Y=128270.000000 )
TRACK	WireCount=370		Net=N$116				start(X=-48260.000000 Y=48320.000000)	end(X=-30900.000000 Y=128270.000000 )
TRACK	WireCount=371		Net=N$117				start(X=-35980.000000 Y=128270.000000)	end(X=-32600.000000 Y=128270.000000 )
TRACK	WireCount=372		Net=N$117				start(X=-41910.000000 Y=48320.000000)	end(X=-35980.000000 Y=128270.000000 )
TRACK	WireCount=373		Net=N$118				start(X=-106360.000000 Y=96520.000000)	end(X=-104140.000000 Y=35560.000000 )
TRACK	WireCount=374		Net=N$119				start(X=-112710.000000 Y=96520.000000)	end(X=-117160.000000 Y=96520.000000 )
TRACK	WireCount=375		Net=N$119				start(X=-98740.000000 Y=102870.000000)	end(X=-112710.000000 Y=96520.000000 )
TRACK	WireCount=376		Net=N$120				start(X=-119060.000000 Y=96520.000000)	end(X=-16510.000000 Y=57150.000000 )
TRACK	WireCount=377		Net=N$121				start(X=-125410.000000 Y=96520.000000)	end(X=-129860.000000 Y=96520.000000 )
TRACK	WireCount=378		Net=N$121				start(X=-103820.000000 Y=102870.000000)	end(X=-125410.000000 Y=96520.000000 )
TRACK	WireCount=379		Net=N$122				start(X=-131760.000000 Y=96520.000000)	end(X=-19050.000000 Y=57150.000000 )
TRACK	WireCount=380		Net=N$123				start(X=-21910.000000 Y=102870.000000)	end(X=-17460.000000 Y=102870.000000 )
TRACK	WireCount=381		Net=N$123				start(X=-108900.000000 Y=102870.000000)	end(X=-21910.000000 Y=102870.000000 )
TRACK	WireCount=382		Net=N$124				start(X=-21590.000000 Y=57150.000000)	end(X=-23810.000000 Y=102870.000000 )
TRACK	WireCount=383		Net=N$125				start(X=-34610.000000 Y=102870.000000)	end(X=-30160.000000 Y=102870.000000 )
TRACK	WireCount=384		Net=N$125				start(X=-113980.000000 Y=102870.000000)	end(X=-34610.000000 Y=102870.000000 )
TRACK	WireCount=385		Net=N$126				start(X=-24130.000000 Y=57150.000000)	end(X=-36510.000000 Y=102870.000000 )
TRACK	WireCount=386		Net=N$127				start(X=-47310.000000 Y=102870.000000)	end(X=-42860.000000 Y=102870.000000 )
TRACK	WireCount=387		Net=N$127				start(X=-119060.000000 Y=102870.000000)	end(X=-47310.000000 Y=102870.000000 )
TRACK	WireCount=388		Net=N$128				start(X=-26670.000000 Y=57150.000000)	end(X=-49210.000000 Y=102870.000000 )
TRACK	WireCount=389		Net=N$129				start(X=-60010.000000 Y=102870.000000)	end(X=-55560.000000 Y=102870.000000 )
TRACK	WireCount=390		Net=N$129				start(X=-124140.000000 Y=102870.000000)	end(X=-60010.000000 Y=102870.000000 )
TRACK	WireCount=391		Net=N$130				start(X=-29210.000000 Y=57150.000000)	end(X=-61910.000000 Y=102870.000000 )
TRACK	WireCount=392		Net=N$131				start(X=-96540.000000 Y=81280.000000)	end(X=-108800.000000 Y=128270.000000 )
TRACK	WireCount=393		Net=N$132				start(X=-113880.000000 Y=128270.000000)	end(X=-105430.000000 Y=81280.000000 )
TRACK	WireCount=394		Net=N$133				start(X=-118960.000000 Y=128270.000000)	end(X=-52090.000000 Y=81280.000000 )
TRACK	WireCount=395		Net=N$134				start(X=-124040.000000 Y=128270.000000)	end(X=-60980.000000 Y=81280.000000 )
TRACK	WireCount=396		Net=N$135				start(X=-129120.000000 Y=128270.000000)	end(X=-69870.000000 Y=81280.000000 )
TRACK	WireCount=397		Net=N$136				start(X=-78760.000000 Y=81280.000000)	end(X=-17360.000000 Y=134620.000000 )
TRACK	WireCount=398		Net=N$137				start(X=-125750.000000 Y=73660.000000)	end(X=-22440.000000 Y=134620.000000 )
TRACK	WireCount=399		Net=N$138				start(X=-16530.000000 Y=81280.000000)	end(X=-27520.000000 Y=134620.000000 )
TRACK	WireCount=400		Net=N$139				start(X=-25420.000000 Y=81280.000000)	end(X=-32600.000000 Y=134620.000000 )
TRACK	WireCount=401		Net=N$140				start(X=-104990.000000 Y=109220.000000)	end(X=-34310.000000 Y=81280.000000 )
TRACK	WireCount=402		Net=N$141				start(X=-111340.000000 Y=109220.000000)	end(X=-43200.000000 Y=81280.000000 )
TRACK	WireCount=403		Net=N$142				start(X=-102020.000000 Y=128270.000000)	end(X=-110490.000000 Y=35560.000000 )
TRACK	WireCount=404		Net=N$143				start(X=-107100.000000 Y=128270.000000)	end(X=-113030.000000 Y=35560.000000 )
TRACK	WireCount=405		Net=N$144				start(X=-112180.000000 Y=128270.000000)	end(X=-115570.000000 Y=35560.000000 )
TRACK	WireCount=406		Net=N$145				start(X=-117260.000000 Y=128270.000000)	end(X=-118110.000000 Y=35560.000000 )
TRACK	WireCount=407		Net=N$146				start(X=-122340.000000 Y=128270.000000)	end(X=-120650.000000 Y=35560.000000 )
TRACK	WireCount=408		Net=N$147				start(X=-127420.000000 Y=128270.000000)	end(X=-40640.000000 Y=57150.000000 )
TRACK	WireCount=409		Net=N$148				start(X=-43180.000000 Y=57150.000000)	end(X=-15660.000000 Y=134620.000000 )
TRACK	WireCount=410		Net=N$149				start(X=-45720.000000 Y=57150.000000)	end(X=-20740.000000 Y=134620.000000 )
TRACK	WireCount=411		Net=N$150				start(X=-48260.000000 Y=57150.000000)	end(X=-25820.000000 Y=134620.000000 )
TRACK	WireCount=412		Net=N$151				start(X=-50800.000000 Y=57150.000000)	end(X=-30900.000000 Y=134620.000000 )
TRACK	WireCount=413		Net=N$152				start(X=-53340.000000 Y=57150.000000)	end(X=-103290.000000 Y=109220.000000 )
TRACK	WireCount=414		Net=N$153				start(X=-55880.000000 Y=57150.000000)	end(X=-109640.000000 Y=109220.000000 )
TRACK	WireCount=415		Net=N$154				start(X=-84240.000000 Y=109220.000000)	end(X=-73240.000000 Y=109220.000000 )
TRACK	WireCount=416		Net=N$154				start(X=-98640.000000 Y=109220.000000)	end(X=-84240.000000 Y=109220.000000 )
TRACK	WireCount=417		Net=N$155				start(X=-54590.000000 Y=83780.000000)	end(X=-56300.000000 Y=128270.000000 )
TRACK	WireCount=418		Net=N$156				start(X=-63480.000000 Y=83780.000000)	end(X=-61380.000000 Y=128270.000000 )
TRACK	WireCount=419		Net=N$157				start(X=-72370.000000 Y=83780.000000)	end(X=-66460.000000 Y=128270.000000 )
TRACK	WireCount=420		Net=N$158				start(X=-81260.000000 Y=83780.000000)	end(X=-71540.000000 Y=128270.000000 )
TRACK	WireCount=421		Net=N$159				start(X=-76620.000000 Y=128270.000000)	end(X=-128250.000000 Y=76160.000000 )
TRACK	WireCount=422		Net=N$160				start(X=-81700.000000 Y=128270.000000)	end(X=-19030.000000 Y=83780.000000 )
TRACK	WireCount=423		Net=N$161				start(X=-86780.000000 Y=128270.000000)	end(X=-27920.000000 Y=83780.000000 )
TRACK	WireCount=424		Net=N$162				start(X=-91860.000000 Y=128270.000000)	end(X=-36810.000000 Y=83780.000000 )
TRACK	WireCount=425		Net=N$163				start(X=-96940.000000 Y=128270.000000)	end(X=-45700.000000 Y=83780.000000 )
TRACK	WireCount=426		Net=SCHIR_DIFF_+				start(X=-33020.000000 Y=87630.000000)	end(X=-60110.000000 Y=115570.000000 )
TRACK	WireCount=427		Net=SCHIR_DIFF_+				start(X=-105730.000000 Y=63670.000000)	end(X=-60110.000000 Y=115570.000000 )
TRACK	WireCount=428		Net=SCHIR_DIFF_-				start(X=-58420.000000 Y=107950.000000)	end(X=-53760.000000 Y=115570.000000 )
TRACK	WireCount=429		Net=SCHIR_DIFF_-				start(X=-98110.000000 Y=63670.000000)	end(X=-58420.000000 Y=107950.000000 )
TRACK	WireCount=430		Net=T1				start(X=-118745.000000 Y=1210.000000)	end(X=-120015.000000 Y=1210.000000 )
TRACK	WireCount=431		Net=T1				start(X=-120015.000000 Y=6410.000000)	end(X=-120015.000000 Y=1210.000000 )
TRACK	WireCount=432		Net=T1				start(X=-118745.000000 Y=6410.000000)	end(X=-120015.000000 Y=6410.000000 )
TRACK	WireCount=433		Net=T1				start(X=-109855.000000 Y=1210.000000)	end(X=-118745.000000 Y=1210.000000 )
TRACK	WireCount=434		Net=T1				start(X=-108585.000000 Y=1210.000000)	end(X=-109855.000000 Y=1210.000000 )
TRACK	WireCount=435		Net=T1				start(X=-109855.000000 Y=6410.000000)	end(X=-109855.000000 Y=1210.000000 )
TRACK	WireCount=436		Net=T1				start(X=-108585.000000 Y=6410.000000)	end(X=-109855.000000 Y=6410.000000 )
TRACK	WireCount=437		Net=T1				start(X=-86620.000000 Y=1550.000000)	end(X=-108585.000000 Y=1210.000000 )
TRACK	WireCount=438		Net=T1				start(X=-75190.000000 Y=1550.000000)	end(X=-86620.000000 Y=1550.000000 )
TRACK	WireCount=439		Net=T1				start(X=-128270.000000 Y=35560.000000)	end(X=-120015.000000 Y=6410.000000 )
TRACK	WireCount=440		Net=T1				start(X=-112220.000000 Y=46990.000000)	end(X=-128270.000000 Y=35560.000000 )
TRACK	WireCount=441		Net=T1				start(X=-94980.000000 Y=72660.000000)	end(X=-112220.000000 Y=46990.000000 )
TRACK	WireCount=442		Net=T1				start(X=-82280.000000 Y=72660.000000)	end(X=-94980.000000 Y=72660.000000 )
TRACK	WireCount=443		Net=T1				start(X=-96840.000000 Y=88900.000000)	end(X=-94980.000000 Y=72660.000000 )
TRACK	WireCount=444		Net=T1				start(X=-103190.000000 Y=88900.000000)	end(X=-96840.000000 Y=88900.000000 )
TRACK	WireCount=445		Net=T1				start(X=-90490.000000 Y=88900.000000)	end(X=-96840.000000 Y=88900.000000 )
TRACK	WireCount=446		Net=T1				start(X=-54610.000000 Y=31750.000000)	end(X=-75190.000000 Y=1550.000000 )
TRACK	WireCount=447		Net=T1				start(X=-44790.000000 Y=64770.000000)	end(X=-54610.000000 Y=31750.000000 )
TRACK	WireCount=448		Net=T1				start(X=-29210.000000 Y=66040.000000)	end(X=-44790.000000 Y=64770.000000 )
TRACK	WireCount=449		Net=T1				start(X=-19050.000000 Y=66040.000000)	end(X=-29210.000000 Y=66040.000000 )
TRACK	WireCount=450		Net=T1				start(X=-17460.000000 Y=96520.000000)	end(X=-19050.000000 Y=66040.000000 )
TRACK	WireCount=451		Net=T1				start(X=-31430.000000 Y=109220.000000)	end(X=-17460.000000 Y=96520.000000 )
TRACK	WireCount=452		Net=T1				start(X=-42760.000000 Y=115570.000000)	end(X=-31430.000000 Y=109220.000000 )
TRACK	WireCount=453		Net=T1				start(X=-49110.000000 Y=115570.000000)	end(X=-42760.000000 Y=115570.000000 )
TRACK	WireCount=454		Net=T1				start(X=-36510.000000 Y=96520.000000)	end(X=-31430.000000 Y=109220.000000 )
TRACK	WireCount=455		Net=T2				start(X=-98425.000000 Y=1210.000000)	end(X=-99695.000000 Y=1210.000000 )
TRACK	WireCount=456		Net=T2				start(X=-99695.000000 Y=6410.000000)	end(X=-99695.000000 Y=1210.000000 )
TRACK	WireCount=457		Net=T2				start(X=-98425.000000 Y=6410.000000)	end(X=-99695.000000 Y=6410.000000 )
TRACK	WireCount=458		Net=T2				start(X=-88170.000000 Y=46990.000000)	end(X=-98425.000000 Y=6410.000000 )
TRACK	WireCount=459		Net=T2				start(X=-14290.000000 Y=109220.000000)	end(X=-88170.000000 Y=46990.000000 )
TRACK	WireCount=460		Net=TRIGGER_LEVELSET_IN				start(X=-30160.000000 Y=96520.000000)	end(X=-37680.000000 Y=128270.000000 )
TRACK	WireCount=461		Net=TRIGGER_LEVELSET_IN				start(X=-27940.000000 Y=48320.000000)	end(X=-30160.000000 Y=96520.000000 )
TRACK	WireCount=462		Net=TRIGGER_LEVELSET_IN				start(X=-40640.000000 Y=48320.000000)	end(X=-27940.000000 Y=48320.000000 )
#********** END OF fix_via_hack.ulp ULP Version 4.8.1 06-05-2021 :19:26:07 LOG **********#

#********** START OF eagle6xx-sch-to-kicad-sch.ulp 2.2 06-05-2021 :19:26:50 LOG **********#
Device Name Conflict: Device=A3L-LOC from internal SCH lib=MTL-Eagle-Bibliothek with device=A3L-LOC from LIB=frames
Symbol Name Conflict: Symbol=A3L-LOC from internal SCH lib=MTL-Eagle-Bibliothek with symbol=A3L-LOC from LIB=frames
Symbol Name Conflict: Symbol=DOCFIELD from internal SCH lib=MTL-Eagle-Bibliothek with symbol=DOCFIELD from LIB=frames
Symbol Name Conflict: Symbol=NC from internal SCH lib=MTL-Eagle-Bibliothek with symbol=NC from LIB=linear
Package Name Conflict: Package=SO08 from internal SCH lib=MTL-Eagle-Bibliothek with package=SO08 from LIB=linear
Package Name Conflict: Package=SOT23 from internal SCH lib=MTL-Eagle-Bibliothek with package=SOT23 from LIB=diode
Package Name Conflict: Package=SOT23 from internal SCH lib=MTL-Eagle-Bibliothek with package=SOT23 from LIB=transistor
Package Name Conflict: Package=SOT23 from internal SCH lib=diode with package=SOT23 from LIB=MTL-Eagle-Bibliothek
Package Name Conflict: Package=SOT23 from internal SCH lib=diode with package=SOT23 from LIB=transistor
Package Name Conflict: Package=0204/7 from internal SCH lib=eagle-ltspice with package=0204/7 from LIB=rcl
Package Name Conflict: Package=0204/7 from internal SCH lib=eagle-ltspice with package=0204/7 from LIB=resistor
Package Name Conflict: Package=0207/10 from internal SCH lib=eagle-ltspice with package=0207/10 from LIB=rcl
Package Name Conflict: Package=0207/10 from internal SCH lib=eagle-ltspice with package=0207/10 from LIB=resistor
Device Name Conflict: Device=A3L-LOC from internal SCH lib=frames with device=A3L-LOC from LIB=MTL-Eagle-Bibliothek
Symbol Name Conflict: Symbol=A3L-LOC from internal SCH lib=frames with symbol=A3L-LOC from LIB=MTL-Eagle-Bibliothek
Symbol Name Conflict: Symbol=DOCFIELD from internal SCH lib=frames with symbol=DOCFIELD from LIB=MTL-Eagle-Bibliothek
Symbol Name Conflict: Symbol=NC from internal SCH lib=linear with symbol=NC from LIB=MTL-Eagle-Bibliothek
Package Name Conflict: Package=SO08 from internal SCH lib=linear with package=SO08 from LIB=MTL-Eagle-Bibliothek
Device Name Conflict: Device=R-EU_0204/2V from internal SCH lib=rcl with device=R-EU_0204/2V from LIB=resistor
Device Name Conflict: Device=R-EU_0204/5 from internal SCH lib=rcl with device=R-EU_0204/5 from LIB=resistor
Device Name Conflict: Device=R-EU_0204/7 from internal SCH lib=rcl with device=R-EU_0204/7 from LIB=resistor
Device Name Conflict: Device=R-EU_0207/2V from internal SCH lib=rcl with device=R-EU_0207/2V from LIB=resistor
Device Name Conflict: Device=R-EU_0207/5V from internal SCH lib=rcl with device=R-EU_0207/5V from LIB=resistor
Device Name Conflict: Device=R-EU_0207/7 from internal SCH lib=rcl with device=R-EU_0207/7 from LIB=resistor
Device Name Conflict: Device=R-EU_0207/10 from internal SCH lib=rcl with device=R-EU_0207/10 from LIB=resistor
Device Name Conflict: Device=R-EU_0207/12 from internal SCH lib=rcl with device=R-EU_0207/12 from LIB=resistor
Device Name Conflict: Device=R-EU_0207/15 from internal SCH lib=rcl with device=R-EU_0207/15 from LIB=resistor
Device Name Conflict: Device=R-EU_0309/10 from internal SCH lib=rcl with device=R-EU_0309/10 from LIB=resistor
Device Name Conflict: Device=R-EU_0309/12 from internal SCH lib=rcl with device=R-EU_0309/12 from LIB=resistor
Device Name Conflict: Device=R-EU_0309/V from internal SCH lib=rcl with device=R-EU_0309/V from LIB=resistor
Device Name Conflict: Device=R-EU_0411/3V from internal SCH lib=rcl with device=R-EU_0411/3V from LIB=resistor
Device Name Conflict: Device=R-EU_0411/12 from internal SCH lib=rcl with device=R-EU_0411/12 from LIB=resistor
Device Name Conflict: Device=R-EU_0411/15 from internal SCH lib=rcl with device=R-EU_0411/15 from LIB=resistor
Device Name Conflict: Device=R-EU_0414/5V from internal SCH lib=rcl with device=R-EU_0414/5V from LIB=resistor
Device Name Conflict: Device=R-EU_0414/15 from internal SCH lib=rcl with device=R-EU_0414/15 from LIB=resistor
Device Name Conflict: Device=R-EU_0613/5V from internal SCH lib=rcl with device=R-EU_0613/5V from LIB=resistor
Device Name Conflict: Device=R-EU_0613/15 from internal SCH lib=rcl with device=R-EU_0613/15 from LIB=resistor
Device Name Conflict: Device=R-EU_0617/5V from internal SCH lib=rcl with device=R-EU_0617/5V from LIB=resistor
Device Name Conflict: Device=R-EU_0617/17 from internal SCH lib=rcl with device=R-EU_0617/17 from LIB=resistor
Device Name Conflict: Device=R-EU_0617/22 from internal SCH lib=rcl with device=R-EU_0617/22 from LIB=resistor
Device Name Conflict: Device=R-EU_0817/7V from internal SCH lib=rcl with device=R-EU_0817/7V from LIB=resistor
Device Name Conflict: Device=R-EU_0817/22 from internal SCH lib=rcl with device=R-EU_0817/22 from LIB=resistor
Device Name Conflict: Device=R-EU_0922/22 from internal SCH lib=rcl with device=R-EU_0922/22 from LIB=resistor
Device Name Conflict: Device=R-EU_0922V from internal SCH lib=rcl with device=R-EU_0922V from LIB=resistor
Device Name Conflict: Device=R-EU_M0805 from internal SCH lib=rcl with device=R-EU_M0805 from LIB=resistor
Device Name Conflict: Device=R-EU_M1206 from internal SCH lib=rcl with device=R-EU_M1206 from LIB=resistor
Device Name Conflict: Device=R-EU_M1406 from internal SCH lib=rcl with device=R-EU_M1406 from LIB=resistor
Device Name Conflict: Device=R-EU_M2012 from internal SCH lib=rcl with device=R-EU_M2012 from LIB=resistor
Device Name Conflict: Device=R-EU_M2309 from internal SCH lib=rcl with device=R-EU_M2309 from LIB=resistor
Device Name Conflict: Device=R-EU_M3216 from internal SCH lib=rcl with device=R-EU_M3216 from LIB=resistor
Device Name Conflict: Device=R-EU_M3516 from internal SCH lib=rcl with device=R-EU_M3516 from LIB=resistor
Device Name Conflict: Device=R-EU_M5923 from internal SCH lib=rcl with device=R-EU_M5923 from LIB=resistor
Device Name Conflict: Device=R-EU_MELF0102AX from internal SCH lib=rcl with device=R-EU_MELF0102AX from LIB=resistor
Device Name Conflict: Device=R-EU_MELF0102R from internal SCH lib=rcl with device=R-EU_MELF0102R from LIB=resistor
Device Name Conflict: Device=R-EU_MELF0102W from internal SCH lib=rcl with device=R-EU_MELF0102W from LIB=resistor
Device Name Conflict: Device=R-EU_MELF0204R from internal SCH lib=rcl with device=R-EU_MELF0204R from LIB=resistor
Device Name Conflict: Device=R-EU_MELF0204W from internal SCH lib=rcl with device=R-EU_MELF0204W from LIB=resistor
Device Name Conflict: Device=R-EU_MELF0207R from internal SCH lib=rcl with device=R-EU_MELF0207R from LIB=resistor
Device Name Conflict: Device=R-EU_MELF0207W from internal SCH lib=rcl with device=R-EU_MELF0207W from LIB=resistor
Device Name Conflict: Device=R-EU_R0402 from internal SCH lib=rcl with device=R-EU_R0402 from LIB=resistor
Device Name Conflict: Device=R-EU_R0603 from internal SCH lib=rcl with device=R-EU_R0603 from LIB=resistor
Device Name Conflict: Device=R-EU_R0805 from internal SCH lib=rcl with device=R-EU_R0805 from LIB=resistor
Device Name Conflict: Device=R-EU_R0805W from internal SCH lib=rcl with device=R-EU_R0805W from LIB=resistor
Device Name Conflict: Device=R-EU_R1005 from internal SCH lib=rcl with device=R-EU_R1005 from LIB=resistor
Device Name Conflict: Device=R-EU_R1206 from internal SCH lib=rcl with device=R-EU_R1206 from LIB=resistor
Device Name Conflict: Device=R-EU_R1206W from internal SCH lib=rcl with device=R-EU_R1206W from LIB=resistor
Device Name Conflict: Device=R-EU_R1210 from internal SCH lib=rcl with device=R-EU_R1210 from LIB=resistor
Device Name Conflict: Device=R-EU_R1210W from internal SCH lib=rcl with device=R-EU_R1210W from LIB=resistor
Device Name Conflict: Device=R-EU_R2010 from internal SCH lib=rcl with device=R-EU_R2010 from LIB=resistor
Device Name Conflict: Device=R-EU_R2010W from internal SCH lib=rcl with device=R-EU_R2010W from LIB=resistor
Device Name Conflict: Device=R-EU_R2012 from internal SCH lib=rcl with device=R-EU_R2012 from LIB=resistor
Device Name Conflict: Device=R-EU_R2012W from internal SCH lib=rcl with device=R-EU_R2012W from LIB=resistor
Device Name Conflict: Device=R-EU_R2512 from internal SCH lib=rcl with device=R-EU_R2512 from LIB=resistor
Device Name Conflict: Device=R-EU_R2512W from internal SCH lib=rcl with device=R-EU_R2512W from LIB=resistor
Device Name Conflict: Device=R-EU_R3216 from internal SCH lib=rcl with device=R-EU_R3216 from LIB=resistor
Device Name Conflict: Device=R-EU_R3216W from internal SCH lib=rcl with device=R-EU_R3216W from LIB=resistor
Device Name Conflict: Device=R-EU_R3225 from internal SCH lib=rcl with device=R-EU_R3225 from LIB=resistor
Device Name Conflict: Device=R-EU_R3225W from internal SCH lib=rcl with device=R-EU_R3225W from LIB=resistor
Device Name Conflict: Device=R-EU_R5025 from internal SCH lib=rcl with device=R-EU_R5025 from LIB=resistor
Device Name Conflict: Device=R-EU_R5025W from internal SCH lib=rcl with device=R-EU_R5025W from LIB=resistor
Device Name Conflict: Device=R-EU_R6332 from internal SCH lib=rcl with device=R-EU_R6332 from LIB=resistor
Device Name Conflict: Device=R-EU_R6332W from internal SCH lib=rcl with device=R-EU_R6332W from LIB=resistor
Device Name Conflict: Device=R-EU_RDH/15 from internal SCH lib=rcl with device=R-EU_RDH/15 from LIB=resistor
Device Name Conflict: Device=R-EU_V234/12 from internal SCH lib=rcl with device=R-EU_V234/12 from LIB=resistor
Device Name Conflict: Device=R-EU_V235/17 from internal SCH lib=rcl with device=R-EU_V235/17 from LIB=resistor
Device Name Conflict: Device=R-EU_V526-0 from internal SCH lib=rcl with device=R-EU_V526-0 from LIB=resistor
Symbol Name Conflict: Symbol=R-EU from internal SCH lib=rcl with symbol=R-EU from LIB=resistor
Package Name Conflict: Package=0204/5 from internal SCH lib=rcl with package=0204/5 from LIB=resistor
Package Name Conflict: Package=0204/7 from internal SCH lib=rcl with package=0204/7 from LIB=eagle-ltspice
Package Name Conflict: Package=0204/7 from internal SCH lib=rcl with package=0204/7 from LIB=resistor
Package Name Conflict: Package=0204V from internal SCH lib=rcl with package=0204V from LIB=resistor
Package Name Conflict: Package=0207/2V from internal SCH lib=rcl with package=0207/2V from LIB=resistor
Package Name Conflict: Package=0207/5V from internal SCH lib=rcl with package=0207/5V from LIB=resistor
Package Name Conflict: Package=0207/7 from internal SCH lib=rcl with package=0207/7 from LIB=resistor
Package Name Conflict: Package=0207/10 from internal SCH lib=rcl with package=0207/10 from LIB=eagle-ltspice
Package Name Conflict: Package=0207/10 from internal SCH lib=rcl with package=0207/10 from LIB=resistor
Package Name Conflict: Package=0207/12 from internal SCH lib=rcl with package=0207/12 from LIB=resistor
Package Name Conflict: Package=0207/15 from internal SCH lib=rcl with package=0207/15 from LIB=resistor
Package Name Conflict: Package=0309/10 from internal SCH lib=rcl with package=0309/10 from LIB=resistor
Package Name Conflict: Package=0309/12 from internal SCH lib=rcl with package=0309/12 from LIB=resistor
Package Name Conflict: Package=0309V from internal SCH lib=rcl with package=0309V from LIB=resistor
Package Name Conflict: Package=0411/12 from internal SCH lib=rcl with package=0411/12 from LIB=resistor
Package Name Conflict: Package=0411/15 from internal SCH lib=rcl with package=0411/15 from LIB=resistor
Package Name Conflict: Package=0411V from internal SCH lib=rcl with package=0411V from LIB=resistor
Package Name Conflict: Package=0414/15 from internal SCH lib=rcl with package=0414/15 from LIB=resistor
Package Name Conflict: Package=0414V from internal SCH lib=rcl with package=0414V from LIB=resistor
Package Name Conflict: Package=0617/17 from internal SCH lib=rcl with package=0617/17 from LIB=resistor
Package Name Conflict: Package=0617/22 from internal SCH lib=rcl with package=0617/22 from LIB=resistor
Package Name Conflict: Package=0617V from internal SCH lib=rcl with package=0617V from LIB=resistor
Package Name Conflict: Package=0922/22 from internal SCH lib=rcl with package=0922/22 from LIB=resistor
Package Name Conflict: Package=0922V from internal SCH lib=rcl with package=0922V from LIB=resistor
Package Name Conflict: Package=M0805 from internal SCH lib=rcl with package=M0805 from LIB=resistor
Package Name Conflict: Package=M1206 from internal SCH lib=rcl with package=M1206 from LIB=resistor
Package Name Conflict: Package=M1406 from internal SCH lib=rcl with package=M1406 from LIB=resistor
Package Name Conflict: Package=M2012 from internal SCH lib=rcl with package=M2012 from LIB=resistor
Package Name Conflict: Package=M2309 from internal SCH lib=rcl with package=M2309 from LIB=resistor
Package Name Conflict: Package=M3216 from internal SCH lib=rcl with package=M3216 from LIB=resistor
Package Name Conflict: Package=M3516 from internal SCH lib=rcl with package=M3516 from LIB=resistor
Package Name Conflict: Package=M5923 from internal SCH lib=rcl with package=M5923 from LIB=resistor
Package Name Conflict: Package=MINI_MELF-0102AX from internal SCH lib=rcl with package=MINI_MELF-0102AX from LIB=resistor
Package Name Conflict: Package=MINI_MELF-0102R from internal SCH lib=rcl with package=MINI_MELF-0102R from LIB=resistor
Package Name Conflict: Package=MINI_MELF-0102W from internal SCH lib=rcl with package=MINI_MELF-0102W from LIB=resistor
Package Name Conflict: Package=MINI_MELF-0204R from internal SCH lib=rcl with package=MINI_MELF-0204R from LIB=resistor
Package Name Conflict: Package=MINI_MELF-0204W from internal SCH lib=rcl with package=MINI_MELF-0204W from LIB=resistor
Package Name Conflict: Package=MINI_MELF-0207R from internal SCH lib=rcl with package=MINI_MELF-0207R from LIB=resistor
Package Name Conflict: Package=MINI_MELF-0207W from internal SCH lib=rcl with package=MINI_MELF-0207W from LIB=resistor
Package Name Conflict: Package=P0613/15 from internal SCH lib=rcl with package=P0613/15 from LIB=resistor
Package Name Conflict: Package=P0613V from internal SCH lib=rcl with package=P0613V from LIB=resistor
Package Name Conflict: Package=P0817/22 from internal SCH lib=rcl with package=P0817/22 from LIB=resistor
Package Name Conflict: Package=P0817V from internal SCH lib=rcl with package=P0817V from LIB=resistor
Package Name Conflict: Package=R0402 from internal SCH lib=rcl with package=R0402 from LIB=resistor
Package Name Conflict: Package=R0603 from internal SCH lib=rcl with package=R0603 from LIB=resistor
Package Name Conflict: Package=R0805 from internal SCH lib=rcl with package=R0805 from LIB=resistor
Package Name Conflict: Package=R0805W from internal SCH lib=rcl with package=R0805W from LIB=resistor
Package Name Conflict: Package=R1005 from internal SCH lib=rcl with package=R1005 from LIB=resistor
Package Name Conflict: Package=R1206 from internal SCH lib=rcl with package=R1206 from LIB=resistor
Package Name Conflict: Package=R1206W from internal SCH lib=rcl with package=R1206W from LIB=resistor
Package Name Conflict: Package=R1210 from internal SCH lib=rcl with package=R1210 from LIB=resistor
Package Name Conflict: Package=R1210W from internal SCH lib=rcl with package=R1210W from LIB=resistor
Package Name Conflict: Package=R2010 from internal SCH lib=rcl with package=R2010 from LIB=resistor
Package Name Conflict: Package=R2010W from internal SCH lib=rcl with package=R2010W from LIB=resistor
Package Name Conflict: Package=R2012 from internal SCH lib=rcl with package=R2012 from LIB=resistor
Package Name Conflict: Package=R2012W from internal SCH lib=rcl with package=R2012W from LIB=resistor
Package Name Conflict: Package=R2512 from internal SCH lib=rcl with package=R2512 from LIB=resistor
Package Name Conflict: Package=R2512W from internal SCH lib=rcl with package=R2512W from LIB=resistor
Package Name Conflict: Package=R3216 from internal SCH lib=rcl with package=R3216 from LIB=resistor
Package Name Conflict: Package=R3216W from internal SCH lib=rcl with package=R3216W from LIB=resistor
Package Name Conflict: Package=R3225 from internal SCH lib=rcl with package=R3225 from LIB=resistor
Package Name Conflict: Package=R3225W from internal SCH lib=rcl with package=R3225W from LIB=resistor
Package Name Conflict: Package=R5025 from internal SCH lib=rcl with package=R5025 from LIB=resistor
Package Name Conflict: Package=R5025W from internal SCH lib=rcl with package=R5025W from LIB=resistor
Package Name Conflict: Package=R6332 from internal SCH lib=rcl with package=R6332 from LIB=resistor
Package Name Conflict: Package=R6332W from internal SCH lib=rcl with package=R6332W from LIB=resistor
Package Name Conflict: Package=RDH/15 from internal SCH lib=rcl with package=RDH/15 from LIB=resistor
Package Name Conflict: Package=V234/12 from internal SCH lib=rcl with package=V234/12 from LIB=resistor
Package Name Conflict: Package=V235/17 from internal SCH lib=rcl with package=V235/17 from LIB=resistor
Package Name Conflict: Package=V526-0 from internal SCH lib=rcl with package=V526-0 from LIB=resistor
Device Name Conflict: Device=R-EU_0204/2V from internal SCH lib=resistor with device=R-EU_0204/2V from LIB=rcl
Device Name Conflict: Device=R-EU_0204/5 from internal SCH lib=resistor with device=R-EU_0204/5 from LIB=rcl
Device Name Conflict: Device=R-EU_0204/7 from internal SCH lib=resistor with device=R-EU_0204/7 from LIB=rcl
Device Name Conflict: Device=R-EU_0207/2V from internal SCH lib=resistor with device=R-EU_0207/2V from LIB=rcl
Device Name Conflict: Device=R-EU_0207/5V from internal SCH lib=resistor with device=R-EU_0207/5V from LIB=rcl
Device Name Conflict: Device=R-EU_0207/7 from internal SCH lib=resistor with device=R-EU_0207/7 from LIB=rcl
Device Name Conflict: Device=R-EU_0207/10 from internal SCH lib=resistor with device=R-EU_0207/10 from LIB=rcl
Device Name Conflict: Device=R-EU_0207/12 from internal SCH lib=resistor with device=R-EU_0207/12 from LIB=rcl
Device Name Conflict: Device=R-EU_0207/15 from internal SCH lib=resistor with device=R-EU_0207/15 from LIB=rcl
Device Name Conflict: Device=R-EU_0309/10 from internal SCH lib=resistor with device=R-EU_0309/10 from LIB=rcl
Device Name Conflict: Device=R-EU_0309/12 from internal SCH lib=resistor with device=R-EU_0309/12 from LIB=rcl
Device Name Conflict: Device=R-EU_0309/V from internal SCH lib=resistor with device=R-EU_0309/V from LIB=rcl
Device Name Conflict: Device=R-EU_0411/3V from internal SCH lib=resistor with device=R-EU_0411/3V from LIB=rcl
Device Name Conflict: Device=R-EU_0411/12 from internal SCH lib=resistor with device=R-EU_0411/12 from LIB=rcl
Device Name Conflict: Device=R-EU_0411/15 from internal SCH lib=resistor with device=R-EU_0411/15 from LIB=rcl
Device Name Conflict: Device=R-EU_0414/5V from internal SCH lib=resistor with device=R-EU_0414/5V from LIB=rcl
Device Name Conflict: Device=R-EU_0414/15 from internal SCH lib=resistor with device=R-EU_0414/15 from LIB=rcl
Device Name Conflict: Device=R-EU_0613/5V from internal SCH lib=resistor with device=R-EU_0613/5V from LIB=rcl
Device Name Conflict: Device=R-EU_0613/15 from internal SCH lib=resistor with device=R-EU_0613/15 from LIB=rcl
Device Name Conflict: Device=R-EU_0617/5V from internal SCH lib=resistor with device=R-EU_0617/5V from LIB=rcl
Device Name Conflict: Device=R-EU_0617/17 from internal SCH lib=resistor with device=R-EU_0617/17 from LIB=rcl
Device Name Conflict: Device=R-EU_0617/22 from internal SCH lib=resistor with device=R-EU_0617/22 from LIB=rcl
Device Name Conflict: Device=R-EU_0817/7V from internal SCH lib=resistor with device=R-EU_0817/7V from LIB=rcl
Device Name Conflict: Device=R-EU_0817/22 from internal SCH lib=resistor with device=R-EU_0817/22 from LIB=rcl
Device Name Conflict: Device=R-EU_0922/22 from internal SCH lib=resistor with device=R-EU_0922/22 from LIB=rcl
Device Name Conflict: Device=R-EU_0922V from internal SCH lib=resistor with device=R-EU_0922V from LIB=rcl
Device Name Conflict: Device=R-EU_M0805 from internal SCH lib=resistor with device=R-EU_M0805 from LIB=rcl
Device Name Conflict: Device=R-EU_M1206 from internal SCH lib=resistor with device=R-EU_M1206 from LIB=rcl
Device Name Conflict: Device=R-EU_M1406 from internal SCH lib=resistor with device=R-EU_M1406 from LIB=rcl
Device Name Conflict: Device=R-EU_M2012 from internal SCH lib=resistor with device=R-EU_M2012 from LIB=rcl
Device Name Conflict: Device=R-EU_M2309 from internal SCH lib=resistor with device=R-EU_M2309 from LIB=rcl
Device Name Conflict: Device=R-EU_M3216 from internal SCH lib=resistor with device=R-EU_M3216 from LIB=rcl
Device Name Conflict: Device=R-EU_M3516 from internal SCH lib=resistor with device=R-EU_M3516 from LIB=rcl
Device Name Conflict: Device=R-EU_M5923 from internal SCH lib=resistor with device=R-EU_M5923 from LIB=rcl
Device Name Conflict: Device=R-EU_MELF0102AX from internal SCH lib=resistor with device=R-EU_MELF0102AX from LIB=rcl
Device Name Conflict: Device=R-EU_MELF0102R from internal SCH lib=resistor with device=R-EU_MELF0102R from LIB=rcl
Device Name Conflict: Device=R-EU_MELF0102W from internal SCH lib=resistor with device=R-EU_MELF0102W from LIB=rcl
Device Name Conflict: Device=R-EU_MELF0204R from internal SCH lib=resistor with device=R-EU_MELF0204R from LIB=rcl
Device Name Conflict: Device=R-EU_MELF0204W from internal SCH lib=resistor with device=R-EU_MELF0204W from LIB=rcl
Device Name Conflict: Device=R-EU_MELF0207R from internal SCH lib=resistor with device=R-EU_MELF0207R from LIB=rcl
Device Name Conflict: Device=R-EU_MELF0207W from internal SCH lib=resistor with device=R-EU_MELF0207W from LIB=rcl
Device Name Conflict: Device=R-EU_R0402 from internal SCH lib=resistor with device=R-EU_R0402 from LIB=rcl
Device Name Conflict: Device=R-EU_R0603 from internal SCH lib=resistor with device=R-EU_R0603 from LIB=rcl
Device Name Conflict: Device=R-EU_R0805 from internal SCH lib=resistor with device=R-EU_R0805 from LIB=rcl
Device Name Conflict: Device=R-EU_R0805W from internal SCH lib=resistor with device=R-EU_R0805W from LIB=rcl
Device Name Conflict: Device=R-EU_R1005 from internal SCH lib=resistor with device=R-EU_R1005 from LIB=rcl
Device Name Conflict: Device=R-EU_R1206 from internal SCH lib=resistor with device=R-EU_R1206 from LIB=rcl
Device Name Conflict: Device=R-EU_R1206W from internal SCH lib=resistor with device=R-EU_R1206W from LIB=rcl
Device Name Conflict: Device=R-EU_R1210 from internal SCH lib=resistor with device=R-EU_R1210 from LIB=rcl
Device Name Conflict: Device=R-EU_R1210W from internal SCH lib=resistor with device=R-EU_R1210W from LIB=rcl
Device Name Conflict: Device=R-EU_R2010 from internal SCH lib=resistor with device=R-EU_R2010 from LIB=rcl
Device Name Conflict: Device=R-EU_R2010W from internal SCH lib=resistor with device=R-EU_R2010W from LIB=rcl
Device Name Conflict: Device=R-EU_R2012 from internal SCH lib=resistor with device=R-EU_R2012 from LIB=rcl
Device Name Conflict: Device=R-EU_R2012W from internal SCH lib=resistor with device=R-EU_R2012W from LIB=rcl
Device Name Conflict: Device=R-EU_R2512 from internal SCH lib=resistor with device=R-EU_R2512 from LIB=rcl
Device Name Conflict: Device=R-EU_R2512W from internal SCH lib=resistor with device=R-EU_R2512W from LIB=rcl
Device Name Conflict: Device=R-EU_R3216 from internal SCH lib=resistor with device=R-EU_R3216 from LIB=rcl
Device Name Conflict: Device=R-EU_R3216W from internal SCH lib=resistor with device=R-EU_R3216W from LIB=rcl
Device Name Conflict: Device=R-EU_R3225 from internal SCH lib=resistor with device=R-EU_R3225 from LIB=rcl
Device Name Conflict: Device=R-EU_R3225W from internal SCH lib=resistor with device=R-EU_R3225W from LIB=rcl
Device Name Conflict: Device=R-EU_R5025 from internal SCH lib=resistor with device=R-EU_R5025 from LIB=rcl
Device Name Conflict: Device=R-EU_R5025W from internal SCH lib=resistor with device=R-EU_R5025W from LIB=rcl
Device Name Conflict: Device=R-EU_R6332 from internal SCH lib=resistor with device=R-EU_R6332 from LIB=rcl
Device Name Conflict: Device=R-EU_R6332W from internal SCH lib=resistor with device=R-EU_R6332W from LIB=rcl
Device Name Conflict: Device=R-EU_RDH/15 from internal SCH lib=resistor with device=R-EU_RDH/15 from LIB=rcl
Device Name Conflict: Device=R-EU_V234/12 from internal SCH lib=resistor with device=R-EU_V234/12 from LIB=rcl
Device Name Conflict: Device=R-EU_V235/17 from internal SCH lib=resistor with device=R-EU_V235/17 from LIB=rcl
Device Name Conflict: Device=R-EU_V526-0 from internal SCH lib=resistor with device=R-EU_V526-0 from LIB=rcl
Symbol Name Conflict: Symbol=R-EU from internal SCH lib=resistor with symbol=R-EU from LIB=rcl
Package Name Conflict: Package=0204/5 from internal SCH lib=resistor with package=0204/5 from LIB=rcl
Package Name Conflict: Package=0204/7 from internal SCH lib=resistor with package=0204/7 from LIB=eagle-ltspice
Package Name Conflict: Package=0204/7 from internal SCH lib=resistor with package=0204/7 from LIB=rcl
Package Name Conflict: Package=0204V from internal SCH lib=resistor with package=0204V from LIB=rcl
Package Name Conflict: Package=0207/2V from internal SCH lib=resistor with package=0207/2V from LIB=rcl
Package Name Conflict: Package=0207/5V from internal SCH lib=resistor with package=0207/5V from LIB=rcl
Package Name Conflict: Package=0207/7 from internal SCH lib=resistor with package=0207/7 from LIB=rcl
Package Name Conflict: Package=0207/10 from internal SCH lib=resistor with package=0207/10 from LIB=eagle-ltspice
Package Name Conflict: Package=0207/10 from internal SCH lib=resistor with package=0207/10 from LIB=rcl
Package Name Conflict: Package=0207/12 from internal SCH lib=resistor with package=0207/12 from LIB=rcl
Package Name Conflict: Package=0207/15 from internal SCH lib=resistor with package=0207/15 from LIB=rcl
Package Name Conflict: Package=0309/10 from internal SCH lib=resistor with package=0309/10 from LIB=rcl
Package Name Conflict: Package=0309/12 from internal SCH lib=resistor with package=0309/12 from LIB=rcl
Package Name Conflict: Package=0309V from internal SCH lib=resistor with package=0309V from LIB=rcl
Package Name Conflict: Package=0411/12 from internal SCH lib=resistor with package=0411/12 from LIB=rcl
Package Name Conflict: Package=0411/15 from internal SCH lib=resistor with package=0411/15 from LIB=rcl
Package Name Conflict: Package=0411V from internal SCH lib=resistor with package=0411V from LIB=rcl
Package Name Conflict: Package=0414/15 from internal SCH lib=resistor with package=0414/15 from LIB=rcl
Package Name Conflict: Package=0414V from internal SCH lib=resistor with package=0414V from LIB=rcl
Package Name Conflict: Package=0617/17 from internal SCH lib=resistor with package=0617/17 from LIB=rcl
Package Name Conflict: Package=0617/22 from internal SCH lib=resistor with package=0617/22 from LIB=rcl
Package Name Conflict: Package=0617V from internal SCH lib=resistor with package=0617V from LIB=rcl
Package Name Conflict: Package=0922/22 from internal SCH lib=resistor with package=0922/22 from LIB=rcl
Package Name Conflict: Package=0922V from internal SCH lib=resistor with package=0922V from LIB=rcl
Package Name Conflict: Package=M0805 from internal SCH lib=resistor with package=M0805 from LIB=rcl
Package Name Conflict: Package=M1206 from internal SCH lib=resistor with package=M1206 from LIB=rcl
Package Name Conflict: Package=M1406 from internal SCH lib=resistor with package=M1406 from LIB=rcl
Package Name Conflict: Package=M2012 from internal SCH lib=resistor with package=M2012 from LIB=rcl
Package Name Conflict: Package=M2309 from internal SCH lib=resistor with package=M2309 from LIB=rcl
Package Name Conflict: Package=M3216 from internal SCH lib=resistor with package=M3216 from LIB=rcl
Package Name Conflict: Package=M3516 from internal SCH lib=resistor with package=M3516 from LIB=rcl
Package Name Conflict: Package=M5923 from internal SCH lib=resistor with package=M5923 from LIB=rcl
Package Name Conflict: Package=MINI_MELF-0102AX from internal SCH lib=resistor with package=MINI_MELF-0102AX from LIB=rcl
Package Name Conflict: Package=MINI_MELF-0102R from internal SCH lib=resistor with package=MINI_MELF-0102R from LIB=rcl
Package Name Conflict: Package=MINI_MELF-0102W from internal SCH lib=resistor with package=MINI_MELF-0102W from LIB=rcl
Package Name Conflict: Package=MINI_MELF-0204R from internal SCH lib=resistor with package=MINI_MELF-0204R from LIB=rcl
Package Name Conflict: Package=MINI_MELF-0204W from internal SCH lib=resistor with package=MINI_MELF-0204W from LIB=rcl
Package Name Conflict: Package=MINI_MELF-0207R from internal SCH lib=resistor with package=MINI_MELF-0207R from LIB=rcl
Package Name Conflict: Package=MINI_MELF-0207W from internal SCH lib=resistor with package=MINI_MELF-0207W from LIB=rcl
Package Name Conflict: Package=P0613/15 from internal SCH lib=resistor with package=P0613/15 from LIB=rcl
Package Name Conflict: Package=P0613V from internal SCH lib=resistor with package=P0613V from LIB=rcl
Package Name Conflict: Package=P0817/22 from internal SCH lib=resistor with package=P0817/22 from LIB=rcl
Package Name Conflict: Package=P0817V from internal SCH lib=resistor with package=P0817V from LIB=rcl
Package Name Conflict: Package=R0402 from internal SCH lib=resistor with package=R0402 from LIB=rcl
Package Name Conflict: Package=R0603 from internal SCH lib=resistor with package=R0603 from LIB=rcl
Package Name Conflict: Package=R0805 from internal SCH lib=resistor with package=R0805 from LIB=rcl
Package Name Conflict: Package=R0805W from internal SCH lib=resistor with package=R0805W from LIB=rcl
Package Name Conflict: Package=R1005 from internal SCH lib=resistor with package=R1005 from LIB=rcl
Package Name Conflict: Package=R1206 from internal SCH lib=resistor with package=R1206 from LIB=rcl
Package Name Conflict: Package=R1206W from internal SCH lib=resistor with package=R1206W from LIB=rcl
Package Name Conflict: Package=R1210 from internal SCH lib=resistor with package=R1210 from LIB=rcl
Package Name Conflict: Package=R1210W from internal SCH lib=resistor with package=R1210W from LIB=rcl
Package Name Conflict: Package=R2010 from internal SCH lib=resistor with package=R2010 from LIB=rcl
Package Name Conflict: Package=R2010W from internal SCH lib=resistor with package=R2010W from LIB=rcl
Package Name Conflict: Package=R2012 from internal SCH lib=resistor with package=R2012 from LIB=rcl
Package Name Conflict: Package=R2012W from internal SCH lib=resistor with package=R2012W from LIB=rcl
Package Name Conflict: Package=R2512 from internal SCH lib=resistor with package=R2512 from LIB=rcl
Package Name Conflict: Package=R2512W from internal SCH lib=resistor with package=R2512W from LIB=rcl
Package Name Conflict: Package=R3216 from internal SCH lib=resistor with package=R3216 from LIB=rcl
Package Name Conflict: Package=R3216W from internal SCH lib=resistor with package=R3216W from LIB=rcl
Package Name Conflict: Package=R3225 from internal SCH lib=resistor with package=R3225 from LIB=rcl
Package Name Conflict: Package=R3225W from internal SCH lib=resistor with package=R3225W from LIB=rcl
Package Name Conflict: Package=R5025 from internal SCH lib=resistor with package=R5025 from LIB=rcl
Package Name Conflict: Package=R5025W from internal SCH lib=resistor with package=R5025W from LIB=rcl
Package Name Conflict: Package=R6332 from internal SCH lib=resistor with package=R6332 from LIB=rcl
Package Name Conflict: Package=R6332W from internal SCH lib=resistor with package=R6332W from LIB=rcl
Package Name Conflict: Package=RDH/15 from internal SCH lib=resistor with package=RDH/15 from LIB=rcl
Package Name Conflict: Package=V234/12 from internal SCH lib=resistor with package=V234/12 from LIB=rcl
Package Name Conflict: Package=V235/17 from internal SCH lib=resistor with package=V235/17 from LIB=rcl
Package Name Conflict: Package=V526-0 from internal SCH lib=resistor with package=V526-0 from LIB=rcl
Package Name Conflict: Package=SOT23 from internal SCH lib=transistor with package=SOT23 from LIB=MTL-Eagle-Bibliothek
Package Name Conflict: Package=SOT23 from internal SCH lib=transistor with package=SOT23 from LIB=diode
#********** END OF eagle6xx-sch-to-kicad-sch.ulp 2.2 06-05-2021 :19:26:50 LOG **********#

#********** START OF exp-lbrs.ulp 6.81 06-05-2021 :19:27:08 LOG **********#
WARNING: Over lapping Pin(s) on SYMBOL:ABSCHIRMGEHäUSE_SMD_25MM
   Pin =SHIELD01
   Pin =SHIELD02
   Pin =SHIELD03
   Pin =SHIELD04
   Pin =SHIELD05
   Pin =SHIELD06
   Pin =SHIELD07
   Pin =SHIELD08
   Pin =SHIELD09
   Pin =SHIELD10
   Pin =SHIELD11
   Pin =SHIELD12
   Pin =SHIELD13
   Pin =SHIELD14
   Pin =SHIELD15
   Pin =SHIELD16
   Pin =SHIELD17
   Pin =SHIELD18
   Pin =SHIELD19
    Conversion completed with no messages
#********** END OF exp-lbrs.ulp 6.81 06-05-2021 :19:27:08 LOG **********#

#********** START OF eagle-lbr2kicad-1.0.ulp 3.1 06-05-2021 :19:28:32 LOG **********#
Missing Prefix Part =''				MTL-EAGLE-BIBLIOTHEK_ABSCHIRMGEHäUSE_SMD_25MM					Piezoverstärker_v3.0		M
Missing Prefix Part =''				MTL-EAGLE-BIBLIOTHEK_MURRATA_NMA_DCDC					Piezoverstärker_v3.0		M
Missing Prefix Part =''				MTL-EAGLE-BIBLIOTHEK_TO252					Piezoverstärker_v3.0		M
Missing Prefix Part =''				MTL-EAGLE-BIBLIOTHEK_SOT23					Piezoverstärker_v3.0		M
Missing Prefix Part =SO8				MTL-EAGLE-BIBLIOTHEK_SO08					Piezoverstärker_v3.0		M
#********** END OF eagle-lbr2kicad-1.0.ulp 3.1 06-05-2021 :19:28:32 LOG **********#

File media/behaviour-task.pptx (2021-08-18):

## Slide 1

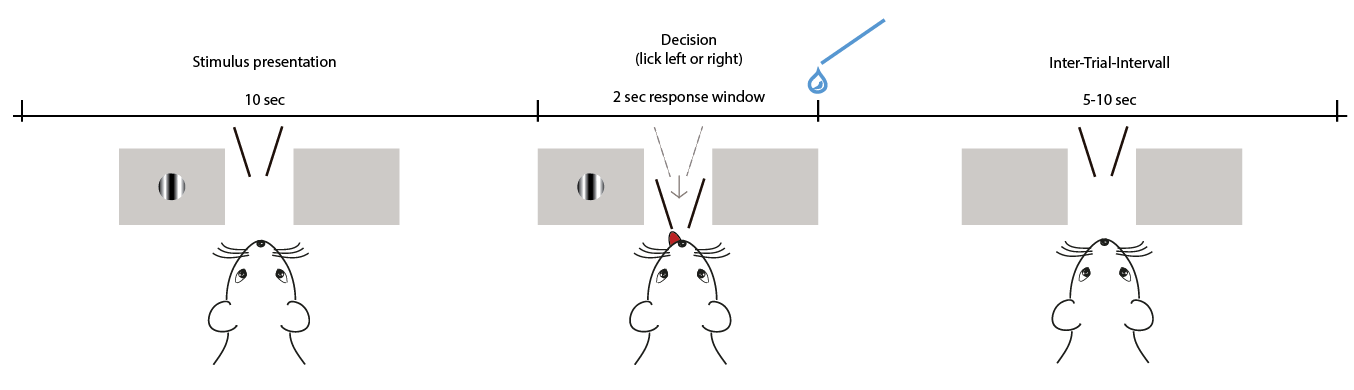
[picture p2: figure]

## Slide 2

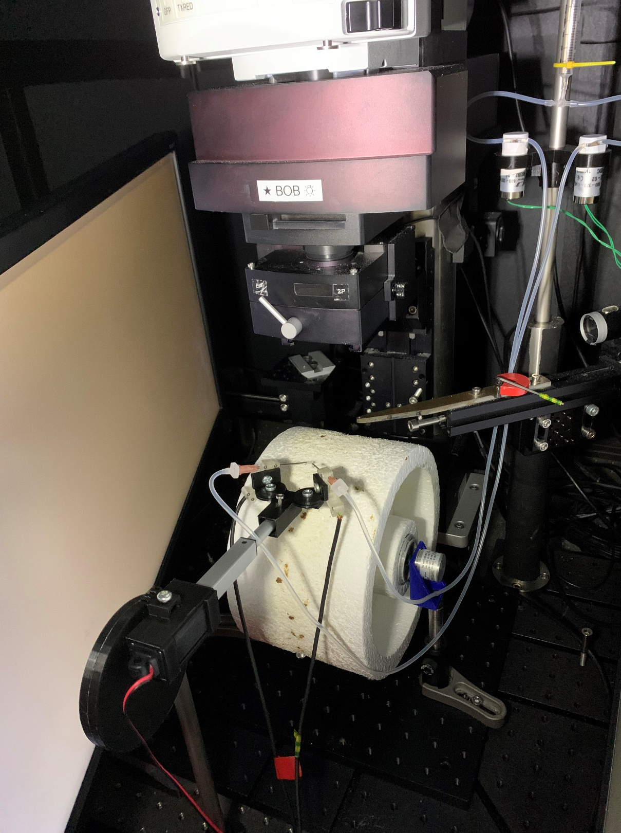
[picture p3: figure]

Solenoids

Lick sensors

Actuator

Treadmill

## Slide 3

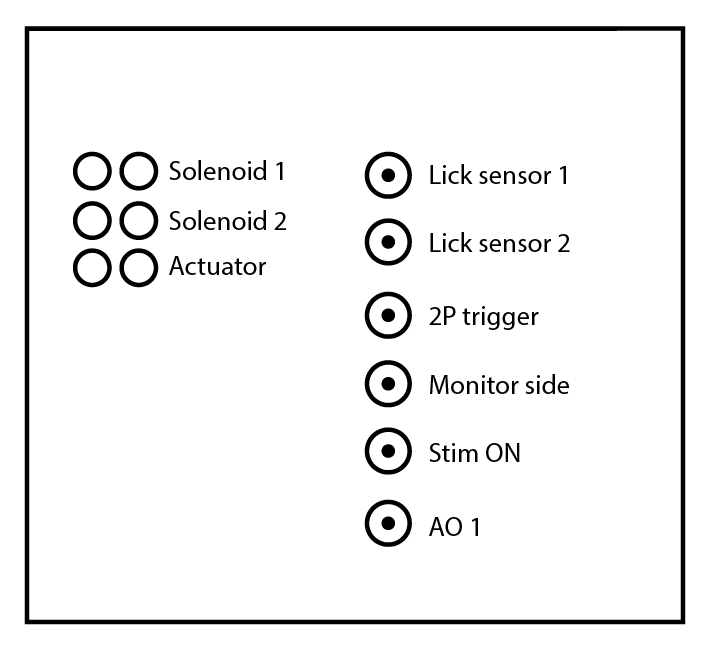
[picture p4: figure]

Solenoids

Lick sensors

Actuator

Treadmill

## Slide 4

Solenoids

Computer
Psychopy/Python

Labjack

Lick sensors

Amplifier

Actuator

Stimulus time

Solenoid side/time

Lick side/time

Treadmill

Rot. encoder

DAQ/ Scanimage

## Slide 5

Stimulus right

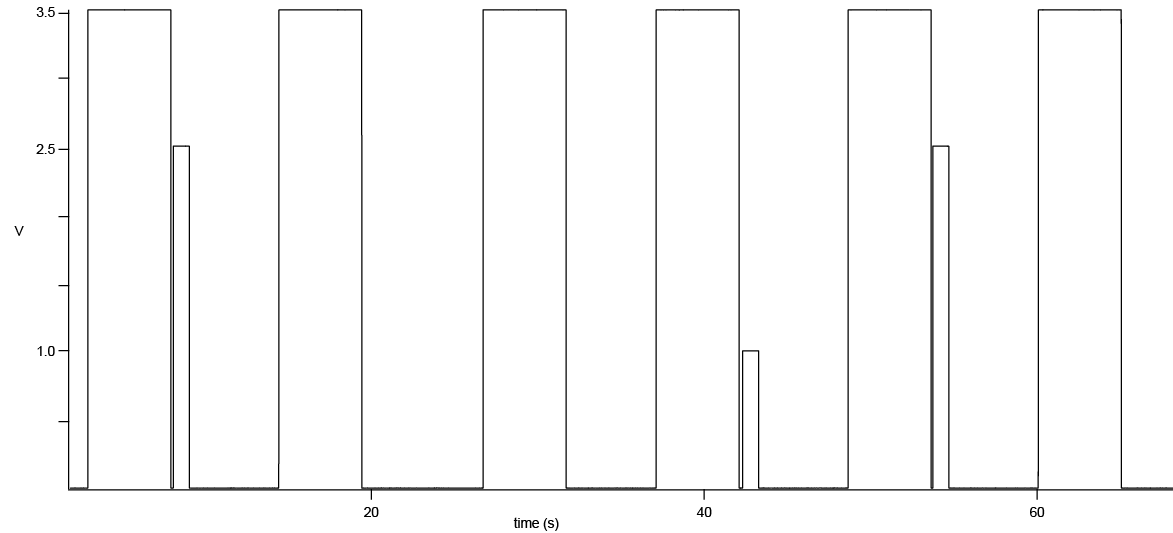
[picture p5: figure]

Stimulus left

Solenoid left

Solenoid right

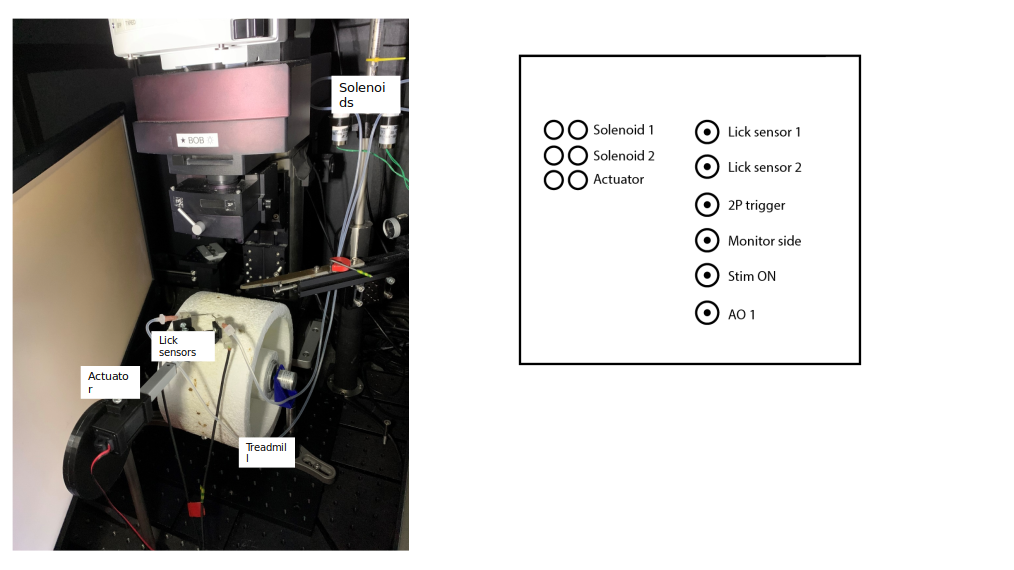
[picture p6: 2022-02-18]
media/behaviour-task.png

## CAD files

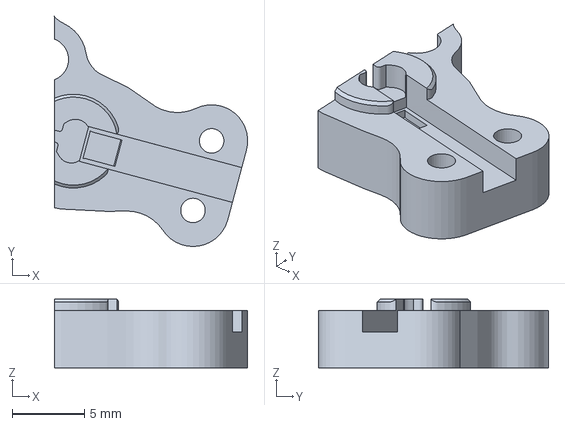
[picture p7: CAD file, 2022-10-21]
hardware/lick_sensor/berlin_initial_model/mechanics/test-Cut001.amf
13.4 x 16.0 x 4.78 mm

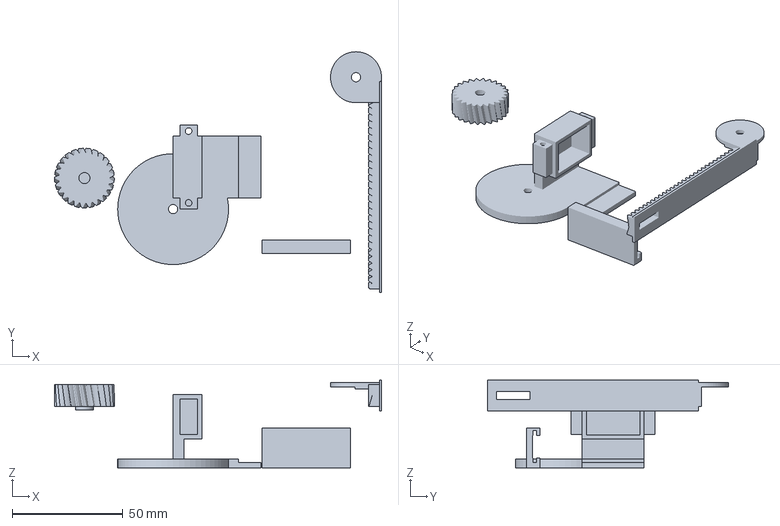
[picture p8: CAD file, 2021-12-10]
hardware/mechanics/servo_actuator_holder.3mf
147.5 x 108.5 x 39.6 mm

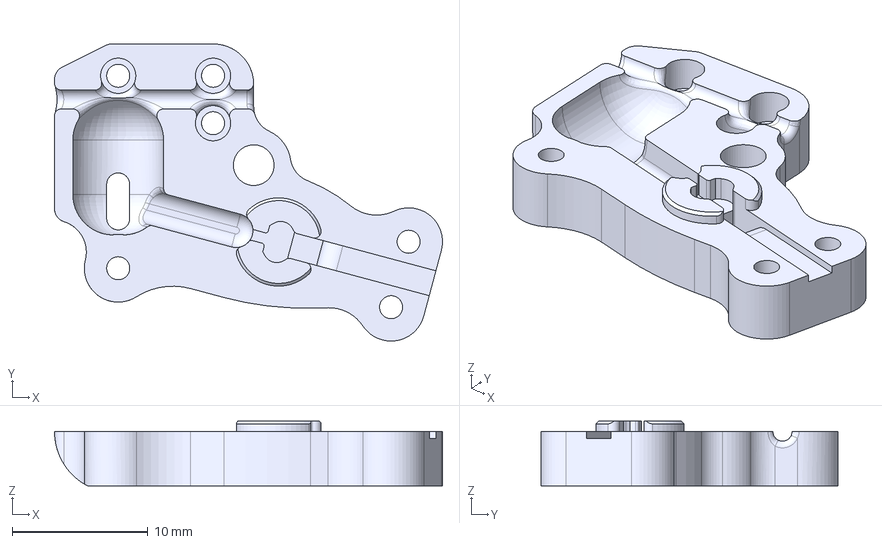
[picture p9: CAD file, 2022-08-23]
hardware/lick_sensor/berlin_initial_model/mechanics/LS_Gehäuse_T1.stp
28.6 x 21.9 x 4.78 mm

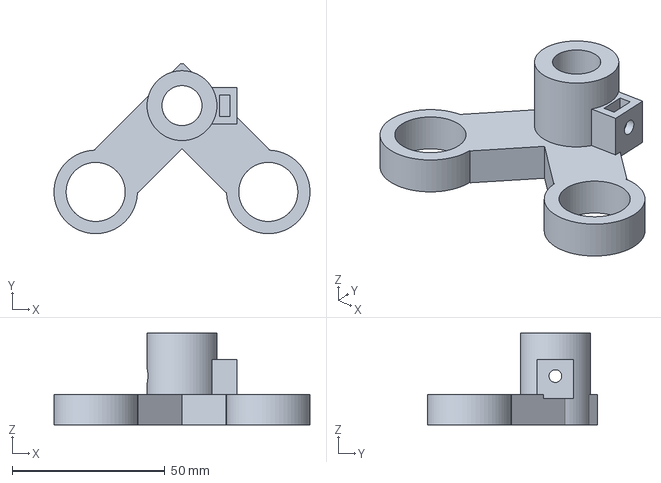
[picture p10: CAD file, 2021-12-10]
hardware/mechanics/solenoid_holder.3mf
83.9 x 55.8 x 30.0 mm

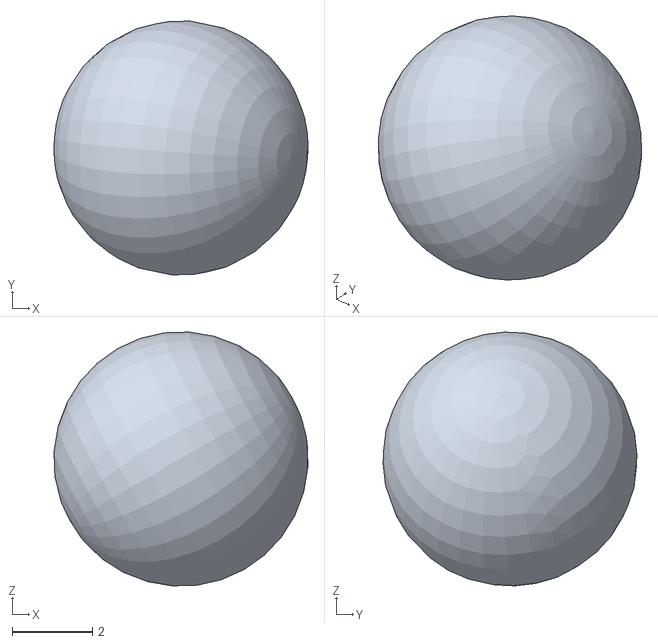
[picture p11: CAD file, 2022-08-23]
hardware/lick_sensor/berlin_initial_model/mechanics/sphere.obj
6.31 x 6.31 x 6.31

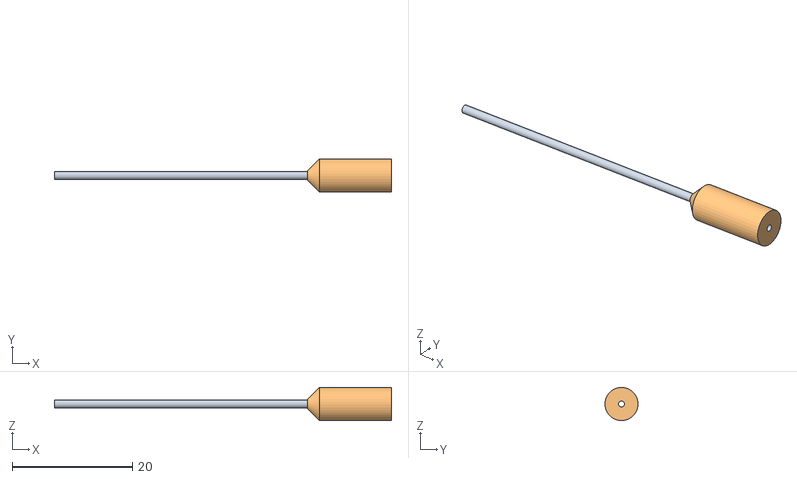
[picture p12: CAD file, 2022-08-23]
hardware/lick_sensor/berlin_initial_model/mechanics/canula.obj
56.0 x 5.49 x 5.49
Kanüle
Kanüle-1

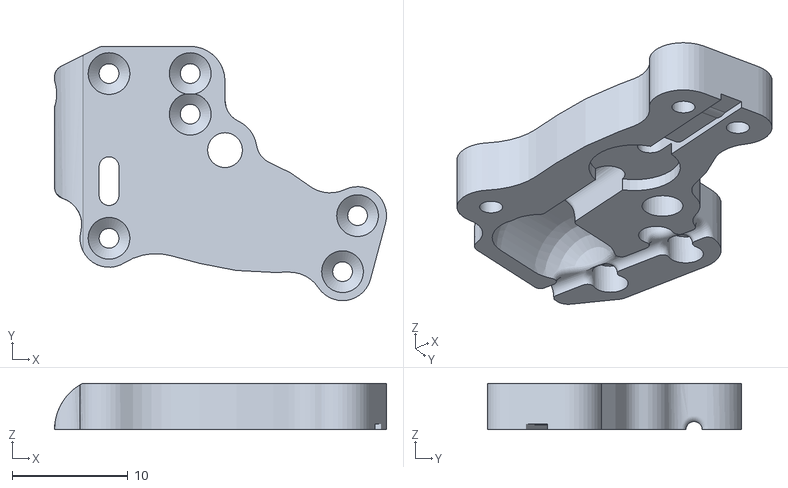
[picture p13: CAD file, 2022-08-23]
hardware/lick_sensor/berlin_initial_model/mechanics/Lecksensor mit HalterA.obj
28.6 x 21.9 x 4.00

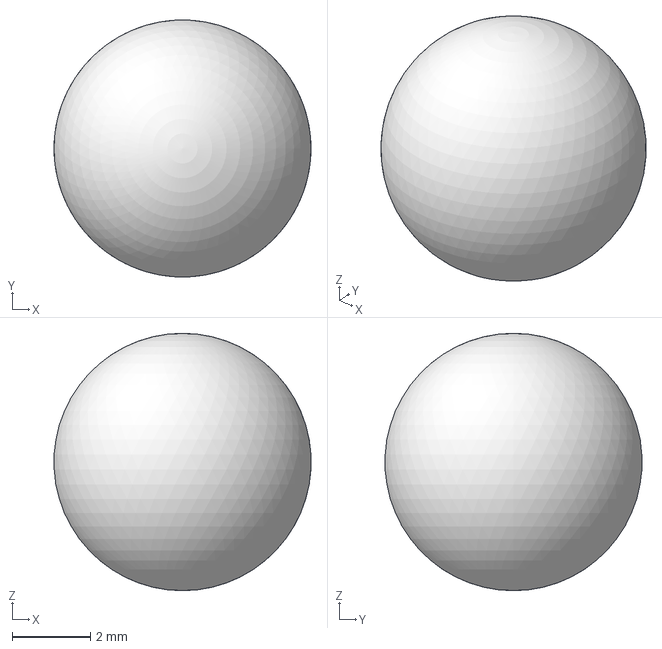
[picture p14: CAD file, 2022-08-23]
hardware/lick_sensor/berlin_initial_model/mechanics/test.FCStd
6.59 x 6.59 x 6.60 mm

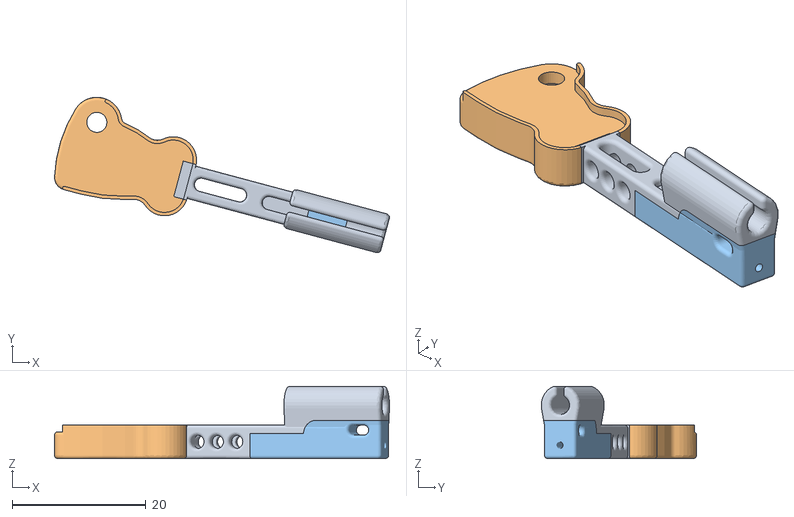
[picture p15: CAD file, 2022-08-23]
hardware/lick_sensor/berlin_initial_model/mechanics/holder_for_holder.obj
50.1 x 23.3 x 10.8
Halter
Halter_1
Halter_2

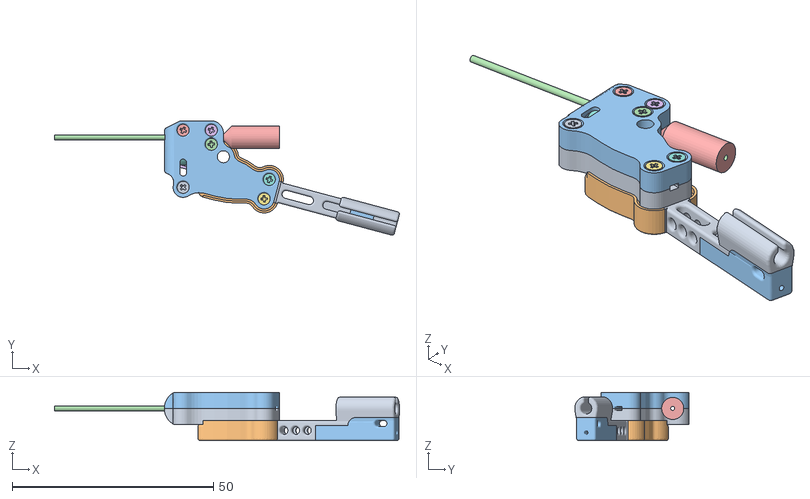
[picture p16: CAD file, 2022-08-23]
hardware/lick_sensor/berlin_initial_model/mechanics/everything.obj
85.8 x 28.4 x 12.0
Halter
Halter_1
Halter_2
countersunk_flat_head_cross_recess_screw_din(DIN_EN_ISO_7046-1_-_M1.6_x_8_-_Z_-_8C)
countersunk_flat_head_cross_recess_screw_din(DIN_EN_ISO_7046-1_-_M1.6_x_8_-_Z_-_8C)_1
countersunk_flat_head_cross_recess_screw_din(DIN_EN_ISO_7046-1_-_M1.6_x_8_-_Z_-_8C)_2
countersunk_flat_head_cross_recess_screw_din(DIN_EN_ISO_7046-1_-_M1.6_x_8_-_Z_-_8C)_3
countersunk_flat_head_cross_recess_screw_din(DIN_EN_ISO_7046-1_-_M1.6_x_8_-_Z_-_8C)_4
countersunk_flat_head_cross_recess_screw_din(DIN_EN_ISO_7046-1_-_M1.6_x_8_-_Z_-_8C)_5
hex_nut_style_1_gradeab_din(Hexagon_Nut_ISO_4032_-_M1.6_-_D_-_N)
hex_nut_style_1_gradeab_din(Hexagon_Nut_ISO_4032_-_M1.6_-_D_-_N)_1
hex_nut_style_1_gradeab_din(Hexagon_Nut_ISO_4032_-_M1.6_-_D_-_N)_2
hex_nut_style_1_gradeab_din(Hexagon_Nut_ISO_4032_-_M1.6_-_D_-_N)_3
hex_nut_style_1_gradeab_din(Hexagon_Nut_ISO_4032_-_M1.6_-_D_-_N)_4
hex_nut_style_1_gradeab_din(Hexagon_Nut_ISO_4032_-_M1.6_-_D_-_N)_5
Gummipuffer_(Silikonschlauch)
Gummipuffer_(Silikonschlauch)_1
Gummipuffer_(Silikonschlauch)_2
LS_Gehäuse_T2
Kanüle
Kanüle-1
Piezo_Sensor
Piezo_Sensor-1
Kugel
LS_Gehäuse_T1

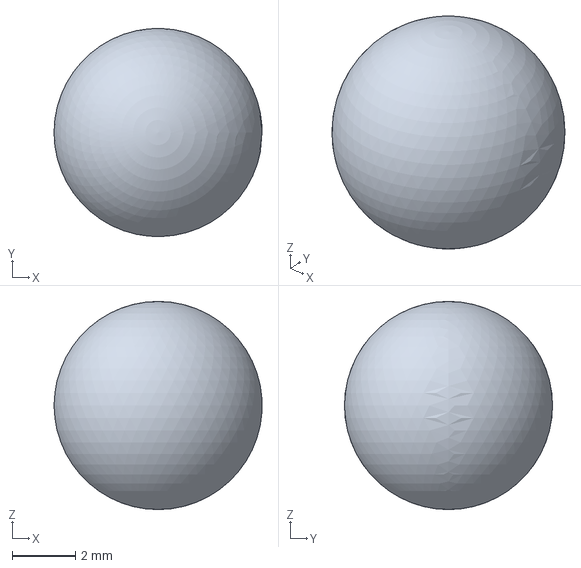
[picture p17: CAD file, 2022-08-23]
hardware/lick_sensor/berlin_initial_model/mechanics/test-Sphere.amf
6.59 x 6.60 x 6.60 mm

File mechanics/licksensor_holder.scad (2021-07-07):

screwD = 3.9;
screwL = 40;

actuatorX = 12;
actuatorY = 12;
actuatorZ = 25;

slitX = 6.45;//added.1mm
slitY = 9.2;//added.1mm
slitZ = 8.97+screwD;

sensorX = 10;
sensorY = 20;
sensorZ = 10;

platformX = 10;
platformY = 50;
platformZ = 5;

$fn = 40;
tol = 0.1;

module actuator_fit(){
    difference(){
    cube([actuatorX+2+2*tol,actuatorY+2+2*tol,actuatorZ+10],center=true);

    translate([0,0,-slitZ-1]){
        union(){
        cube([actuatorX+0.5+2*tol,actuatorY+0.5+2*tol,actuatorZ+2*tol],center = true);
            translate([0,0,(actuatorZ+slitZ)/2]){
            cube([slitX+2*tol,slitY+2*tol,slitZ],center = true);
    
            rotate([0,90,0]){
                translate([2,0,-screwL/2]){
                cylinder(d=screwD,h=screwL);
                }//end translate
            }//end rotate
        }//end translate
        }//end union
    }//end translate
    }//end difference
    
     translate([4.6,0,17]){   
rotate([0,90,0]){
    difference(){
    union(){
cube([platformX,platformY,platformZ],center = true);
 translate([0,0,-actuatorX/2]){
cube([platformX,actuatorY+2+2*tol,actuatorX],center = true);
 }//endtranslate
    
    translate([0,(platformY-sensorY)/2,(platformZ-2)/2]){
cylinder(d=sensorY+3,h=2,center=true);

    }//end translate
        translate([0,-(platformY-sensorY)/2,(platformZ-2)/2]){
cylinder(d=sensorY+3,h=2,center=true);
            
    }//end translate
}//end union
union(){
        translate([0,-(platformY-sensorY)/2,(platformZ-2)/2]){
            cylinder(d=screwD+2*tol,h=20,center=true);
    }//end translate
    translate([0,(platformY-sensorY)/2,(platformZ-2)/2]){

        cylinder(d=screwD+2*tol,h=20,center=true);
    }//end translate
}//end union
}//end difference
}//end rotate
}//end translate

}//end module


module lick_sensor_fit(){
    difference(){
        union(){
        cube([3.5,sensorY+2,sensorZ+2],center=true);
        translate([sensorX/2+screwD,0,-(sensorZ)/2]){
        cylinder(d=sensorY+3,h=2,center=true);
            }//end translate
        }
        //union(){
        //translate([0,0,1.1]){
        //%cube([sensorX,sensorY,sensorZ],center=true);
        //}//end translate
        

        rotate([0,90,0]){    
        cylinder(d=screwD+2*tol,h=sensorX+5,center=true);
        }//end rotate
         translate([sensorX/2+screwD+1,0,-(sensorZ)/2]){
        cylinder(d=screwD+2*tol,h=5,center=true);
        }//end translate
    //}//end union
           }//end difference
    }//end module
    


translate([30,50,0]){
lick_sensor_fit();    
}

translate([30,-50,0]){
lick_sensor_fit();    
}
rotate([0,90,0]){
actuator_fit();
}

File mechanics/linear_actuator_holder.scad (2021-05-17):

poleDia = 12.9;
poleHei = 45;
tol = 0.1;
actuatorX = 18;
actuatorY = 20;
actuatorZ = 50;

rotatorDia = actuatorX+actuatorY+30;
rotatorHei = 8;

screwDia=3.95;
nutDia = 6.91;
nutHei = 3.25;

$fn=60;


module nutpocket(){
    difference(){
        cube([nutHei+5,nutDia+5,nutDia+6],center=true);
        union(){
            translate([0,0,nutDia/2-2.5]){
                rotate([0,90,0]){
                    translate([0,0,-10]){
                        cylinder(d=screwDia+2*tol,h=nutHei+20);
                        }//end translate
                }//end rotate
                cube([nutHei+2*tol,nutDia+2*tol,nutDia+4+2*tol],center=true);
                }//end translate
            }//end union
        }//end differece
    }//end module
    
module actuatorFit(){
    difference(){
        union(){
        cube([actuatorX+6+2*tol,actuatorY+6+2*tol,actuatorZ],center=true);
        translate([0,(actuatorY+6-1)/2,actuatorZ/2-5]){
            cube([actuatorX+4+2*tol,5,10],center=true);    
        }//end translate
            translate([0,(actuatorY+6-1)/2,-actuatorZ/2+5]){
            cube([actuatorX+4+2*tol,5,10],center=true);    
        }//end translate
        }//end union //cube([actuatorX+30,screwDia+10,screwDia+10],center=true);
        union(){
            translate([-2.5*actuatorX,0,0]){
            rotate([0,90,0]){
            cylinder(d=screwDia+2*tol,h=5*actuatorX);
            }//end rotate
        }//end translate
        translate([0,3,0]){
        cube([actuatorX+2*tol,actuatorY+3*tol,actuatorZ+5],center=true);
        }//end translate
    }//end union
    }//end difference
    
        rotate([-90,0,0]){
    translate([(actuatorX+nutHei+8)/2,0,-.95]){
        
    nutpocket();
        }
    }
    
    rotate([-90,0,0]){
        translate([-(actuatorX+nutHei+8)/2,0,-.95]){
            
    nutpocket();
            }
    }
    }//end module


module poleFit(){
    difference(){
    cylinder(d=poleDia+10,h=poleHei);
        translate([0,0,-1]){
        cylinder(d=poleDia+2*tol,h=poleHei+5);
        }//end translate
    translate([-(poleDia),0,poleHei/2+1]){
        rotate([0,90,0]){
        cylinder(d=screwDia+1,h=poleDia+20);
        }//end rotate
    }//end translate
    }//end difference
    translate([(poleDia+10)/2+2.5,0,poleHei/2]){
        nutpocket();
    }//end translate
}//end module



difference(){
    cylinder(d=80,h=5);
    translate([0,0,-4]){
        cylinder(d=screwDia+2*tol,h=10);
    }//end translate
    }//end translate
rotate([-90,0,0]){
    translate([20,8.1,15]){
    actuatorFit();
    }
    }

translate([100,100,0]){

difference(){
cylinder(d=80,h=5);
translate([0,0,-4]){
cylinder(d=screwDia+2*tol,h=10);
}
}
rotate([0,-90,0]){
    translate([12.5,20,-20]){
poleFit();
    }
}
}



//poleFit();



////////////legacy

module teeth(tx = 5,ty=5,tz=10){
union(){
    for (i= [0:15:360]){
    rotate([0,0,i])   {
        //translate([0,-(rotatorDia+2)/2,0]){
    
            cube([tx,ty,tz],center=true);
        //}//end translate
    }//end rotate
    }//end for
}//end union
}//end module

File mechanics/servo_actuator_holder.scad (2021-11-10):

//////////////////////////
// Holder for servo motors
// and licking spouts
// CC BY SA 4.0 
// Andre M Chagas
// 22/10/2021
///////////////////////////
//uses a gear library:
//https://github.com/chrisspen/gears

use <gears/gears.scad>

//thorlabs pole which holds the system in position
poleDia = 12.9;
poleHei = 25;

tol = 0.1;

//servo motor dimensions
servoX = 16;
servoY = 24;
servoZ = 25.6;
servoPocketH = 9;

//wall thickness of the servo holder
holderWall = 2;



//rotatorDia = 68;
//rotatorHei = 8;


//information about nut and screws that are used to fix things
screwDia=3.95;

nutDia = 6.91;
nutHei = 3.25;

$fn=60;


//gear fit information
fitX=1.7;
fitY=4.6;
fitZ=6;
fitDispla=1.5;


//gear and rail information
gearModule = 1;
nTeeth = 25;
gearW = 10;
centralBoreD = 5;
pressureAngle = 30;
helixAngle = 10;
railL = 30;
railH=5;




module nutpocket(){
    difference(){
        cube([nutHei+5,nutDia+5,nutDia+6],center=true);
        union(){
            translate([0,0,nutDia/2-2.5]){
                rotate([0,90,0]){
                    translate([0,0,-10]){
                        cylinder(d=screwDia+2*tol,h=nutHei+20);
                        }//end translate
                }//end rotate
                cube([nutHei+2*tol,nutDia+2*tol,nutDia+4+2*tol],center=true);
                }//end translate
            }//end union
        }//end differece
    }//end module
    
module gear(){

    difference(){
        translate([0,0,-fitDispla]){
            cylinder(d=8,h=fitZ);
        }//end translate
        translate([0,0,fitDispla-0.1]){
            cube([fitX+2*tol,fitY+2*tol,fitZ],center=true);
            rotate([0,0,90]){
                cube([fitX+2*tol,4.71+2*tol,fitZ],center=true);
                }//end rotate
        }//end translate
        }//end difference
    //spur_gear (modul, zahnzahl, breite, bohrung, eingriffswinkel=20, schraegungswinkel=0, optimiert=true) 
    spur_gear (gearModule, nTeeth, gearW, centralBoreD, pressure_angle=pressureAngle, helix_angle=helixAngle, optimized=true) ;
    
}//end module

module servo_fit(){
    difference(){
        union(){
    cube([servoX+2*holderWall,servoY+2*holderWall,servoPocketH+2*holderWall]);
    translate([holderWall,(servoY+2*holderWall),3]){
        cube([servoX,5,8]);
        }//end translate
    translate([holderWall,-2*holderWall-1,3]){
        cube([servoX,5,8]);
        }//end translate
    }//end union
    translate([holderWall,holderWall,holderWall]){
        cube([servoX+2*tol,servoY+2*tol,servoZ+2*tol]);    
    rotate([0,90,0]){    
    translate([-5,servoY+4.2,-1]){
    cylinder(d=3,h=servoX+2);
    }//end translate
}//end rotate
    rotate([0,90,0]){    
    translate([-5,-4.2,-1]){
    cylinder(d=3,h=servoX+2);
    }//end translate
}//end rotate
    }//end translate
    
    }//end difference
    
    
    translate([(servoX)+gearW/2+railH+3,0,0]){
        cube([4,servoY+2*holderWall,servoZ+gearW+2*holderWall]);
    translate([-10,0,0])
        cube([12,servoY+2*holderWall,5]);
        }//end translate
     
    
    }//end module
    
    
 
module linear_rail_pos(leng = railL){
    difference(){
    union(){
    translate([-leng/2-2,-railH,-2]){
    cube([leng,1,gearW+4]);
        }//end translate
    //rack(module, length, height, width, pressure_angle=20, helix_angle=0)
    rack(gearModule, leng, railH, gearW, pressure_angle=pressureAngle, helix_angle=-helixAngle);
    }//end union
    translate([-leng/2+2,-railH-1,(gearW-3.5)/2]){
    cube([15,10,3.5]);
        }//end translate
}//end difference
    translate([leng/2,6.5,gearW]){
 
        difference(){
            cylinder(d=23,h=2,center=true);
            cylinder(d=screwDia+2*tol,h=20,center=true);
        }//end difference
    translate([-23/2,-23/2,-2]){
        cube([8,12,3]);
    }//end translate
    }//end translate
/*
translate([-leng/2-2,-railH,-2]){
    cube([leng,1,gearW+4]);
        }//end translate
*/
}//module

module linear_rail_neg(leng = railL){
    
    translate([-leng/2,-railH,-2]){
    cube([leng+4*tol,1+4*tol,gearW+4+4*tol]);
        }//end translate
    //rack(module, length, height, width, pressure_angle=20, helix_angle=0)
    rack(gearModule, leng+2*tol, railH+2*tol, gearW+2*tol, pressure_angle=pressureAngle, helix_angle=helixAngle);
    }//module


module poleFit(){
    difference(){
    cylinder(d=poleDia+10,h=poleHei);
        translate([0,0,-1]){
        cylinder(d=poleDia+2*tol,h=poleHei+5);
        }//end translate
    translate([-(poleDia),0,poleHei/2+1]){
        rotate([0,90,0]){
        cylinder(d=screwDia+1,h=poleDia+20);
        }//end rotate
    }//end translate
    }//end difference
    translate([(poleDia+10)/2+2.5,0,poleHei/2]){
        nutpocket();
    }//end translate
}//end module



difference(){
    cylinder(d=50,h=4);
    translate([0,0,-4]){
        cylinder(d=screwDia+2*tol,h=10);
    }//end translate
    }//end translate
rotate([0,90,0]){
    translate([-33,5,0]){
    //difference(){
difference(){
servo_fit();
   
rotate([0,0,90]){
translate([-5,-servoY-holderWall-4.5,servoZ+2*holderWall]){
    difference(){
    cube([40,6,gearW+8]);
        
    //translate([20,railH+5-2,(gearW)/2-0.5]){
    //    %linear_rail_neg(leng = 45);
    //}//end translate
    }//end difference

}//end translate
}//end rotate
}//end difference
  }
    }
translate([40,-20,0]){
difference(){
    cube([40,6,gearW+8]);
        
    translate([20,railH+5-2,(gearW)/2-0.5]){
        linear_rail_neg(leng = 45);
    }//end translate
    }//end difference
}//end translate


/////////////////////////////////////////
//translate([100,100,0]){
//
//difference(){
//cylinder(d=50,h=5);
//translate([0,0,-4]){
//cylinder(d=screwDia+2*tol,h=10);
//}
//}



//rotate([0,-90,0]){
//    translate([12.5,20,-20]){
//poleFit();
//    }
//}
//}









translate([68,0,0])
translate([(servoX)+gearW/2,servoY/2,servoZ+holderWall])
rotate([0,0,90])
linear_rail_pos(leng = 75);
//translate([0,0,0])
//servo_fit();
translate([(servoX+2*holderWall)/2-50,(servoY+2*holderWall)/2,servoZ+holderWall])
gear();

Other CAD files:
hardware/lick_sensor/berlin_initial_model/mechanics/Lecksensor mit Halter.stp
hardware/mechanics/servo_actuator_holder.scad
hardware/lick_sensor/berlin_initial_model/mechanics/Lecksensor mit Halter.obj
hardware/lick_sensor/berlin_initial_model/mechanics/Lecksensor mit Halter.x_t
hardware/mechanics/solenoid_holder.scad

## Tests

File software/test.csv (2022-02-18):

trial 1no correction
  monitor: 1
..stim on

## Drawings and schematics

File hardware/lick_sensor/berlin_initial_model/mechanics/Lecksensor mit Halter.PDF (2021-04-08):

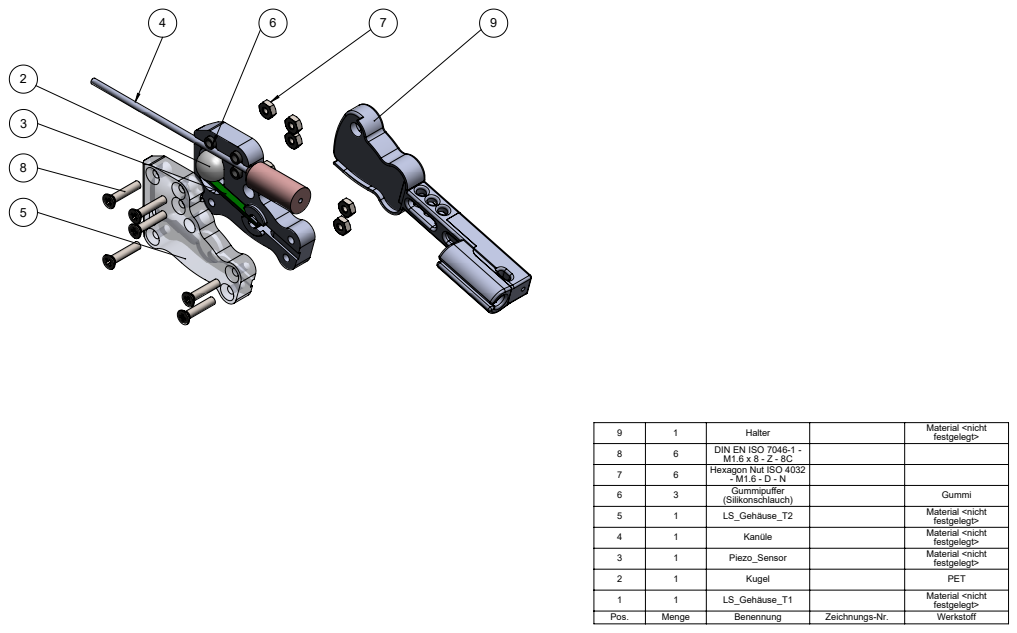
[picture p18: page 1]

Pos. 6 | Menge 1 3 | Benennung Halter Gummipuffer (Silikonschlauch) | Zeichnungs-Nr. | Material <nicht Werkstoff 9 Gummi
8 | 6 | DIN EN ISO 7046-1 -M1.6 x 8 - Z - 8C
7 | 6 | Hexagon Nut ISO 4032 - M1.6 - D - N

festgelegt>

5 | 1 | LS_Gehäuse_T2 | | Material <nicht festgelegt>
4 | 1 | Kanüle | | Material <nicht festgelegt>
3 | 1 | Piezo_Sensor | | Material <nicht festgelegt>

2 | 1 | Kugel | | PET
1 | 1 | LS_Gehäuse_T1 | | Material <nicht festgelegt>

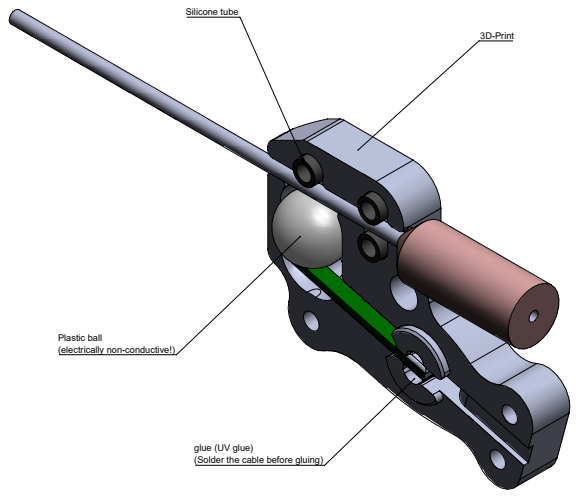
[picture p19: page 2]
Silicone tube

Plastic ball
(electrically non-conductive!)

glue (UV glue)
(Solder the cable before gluing)

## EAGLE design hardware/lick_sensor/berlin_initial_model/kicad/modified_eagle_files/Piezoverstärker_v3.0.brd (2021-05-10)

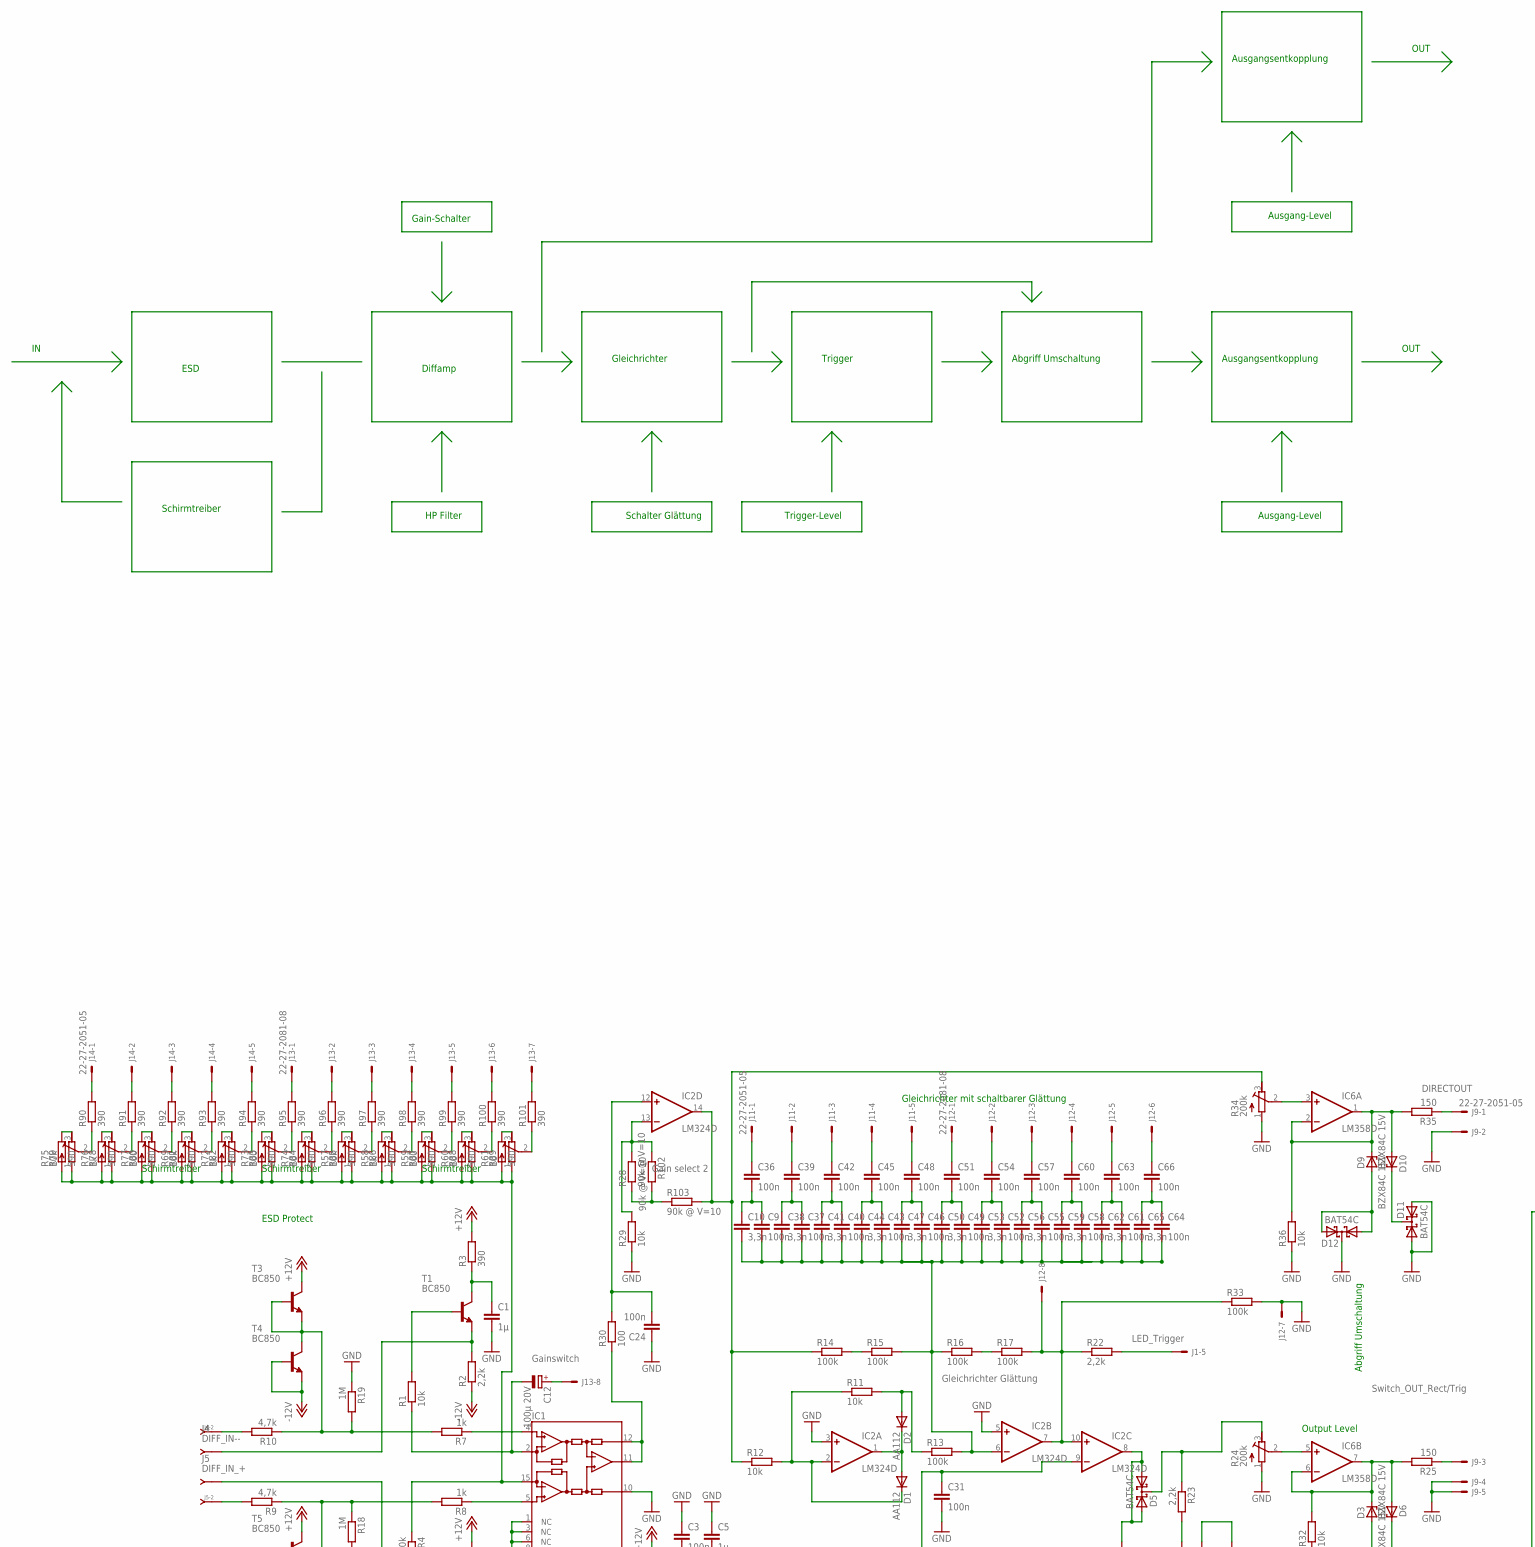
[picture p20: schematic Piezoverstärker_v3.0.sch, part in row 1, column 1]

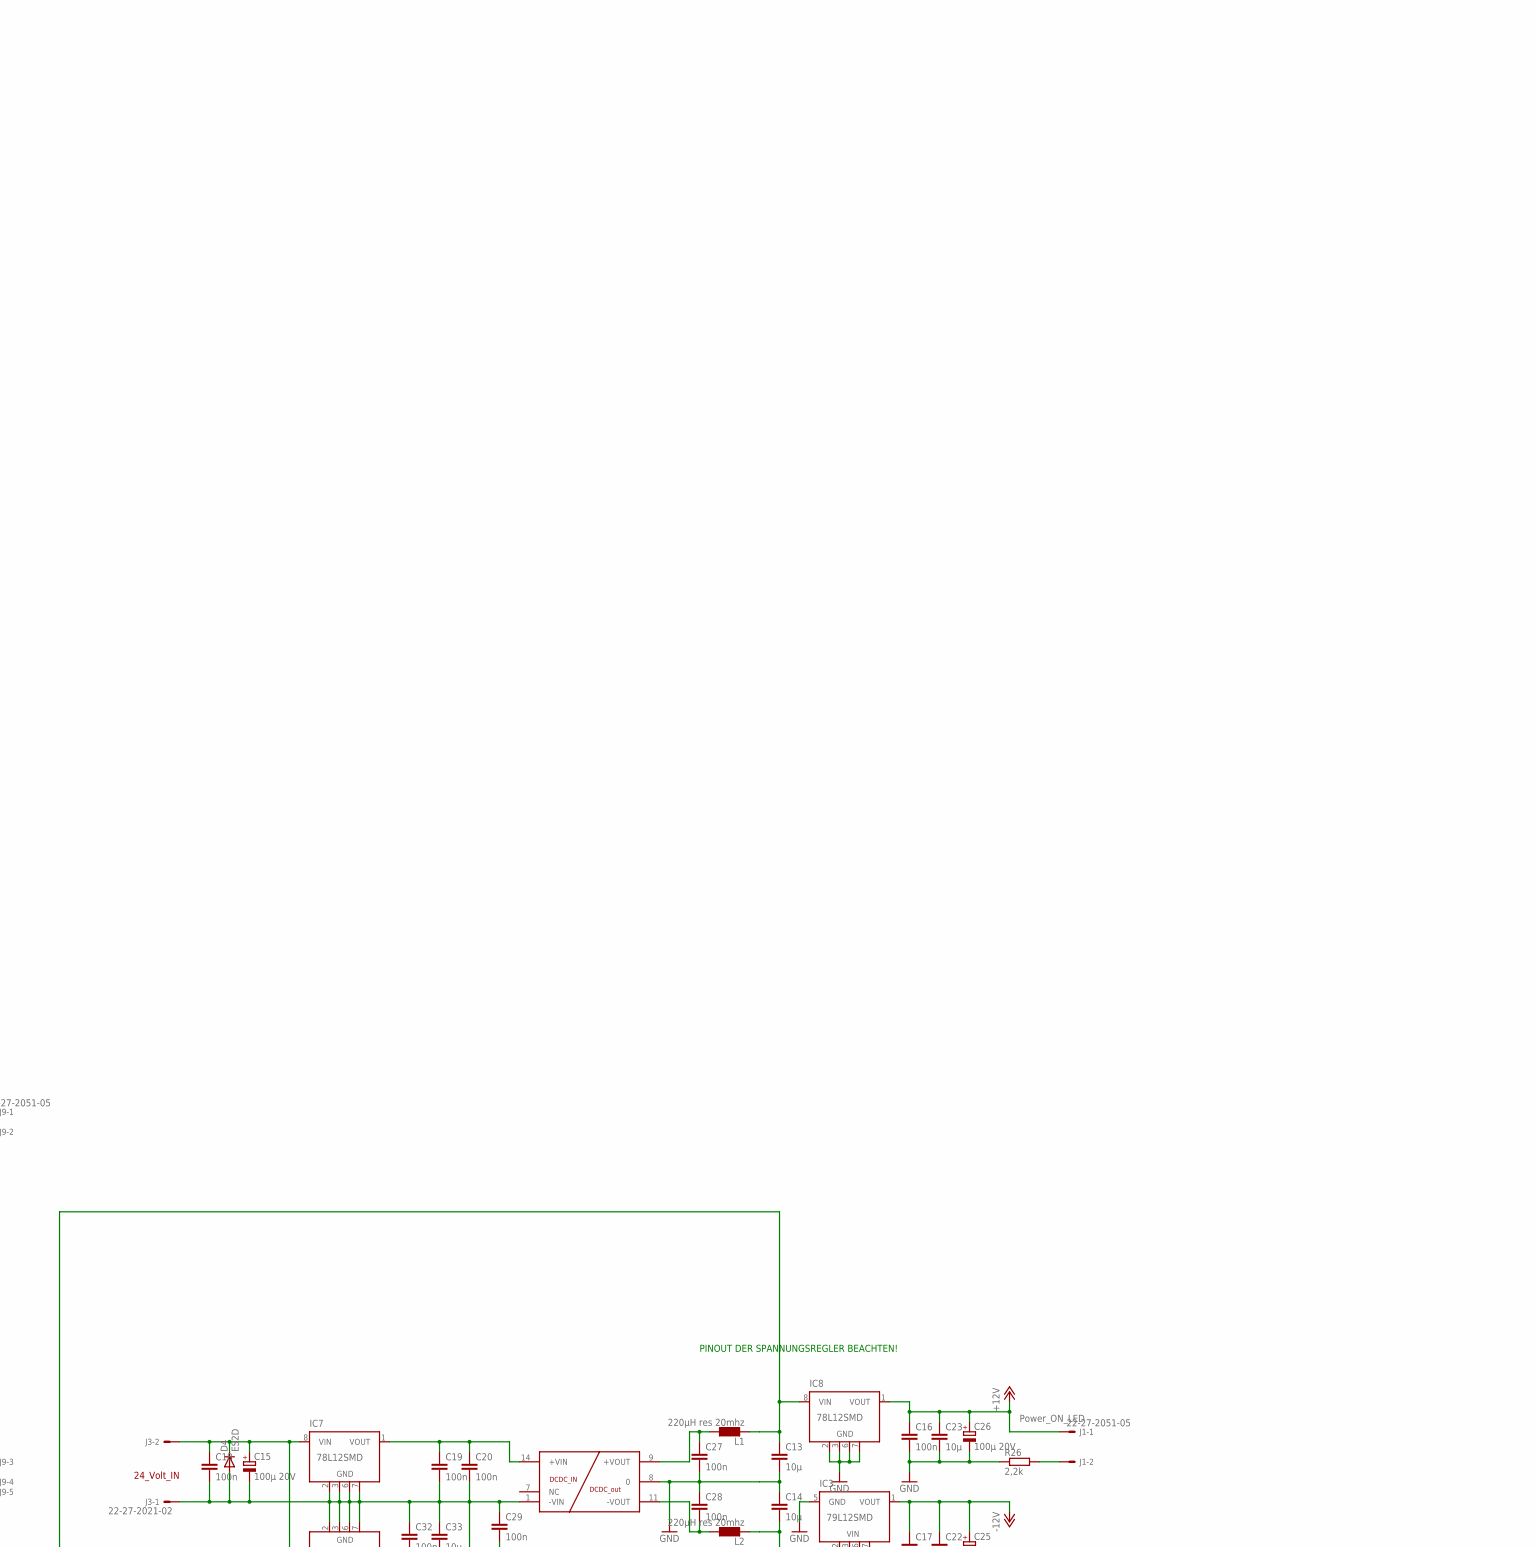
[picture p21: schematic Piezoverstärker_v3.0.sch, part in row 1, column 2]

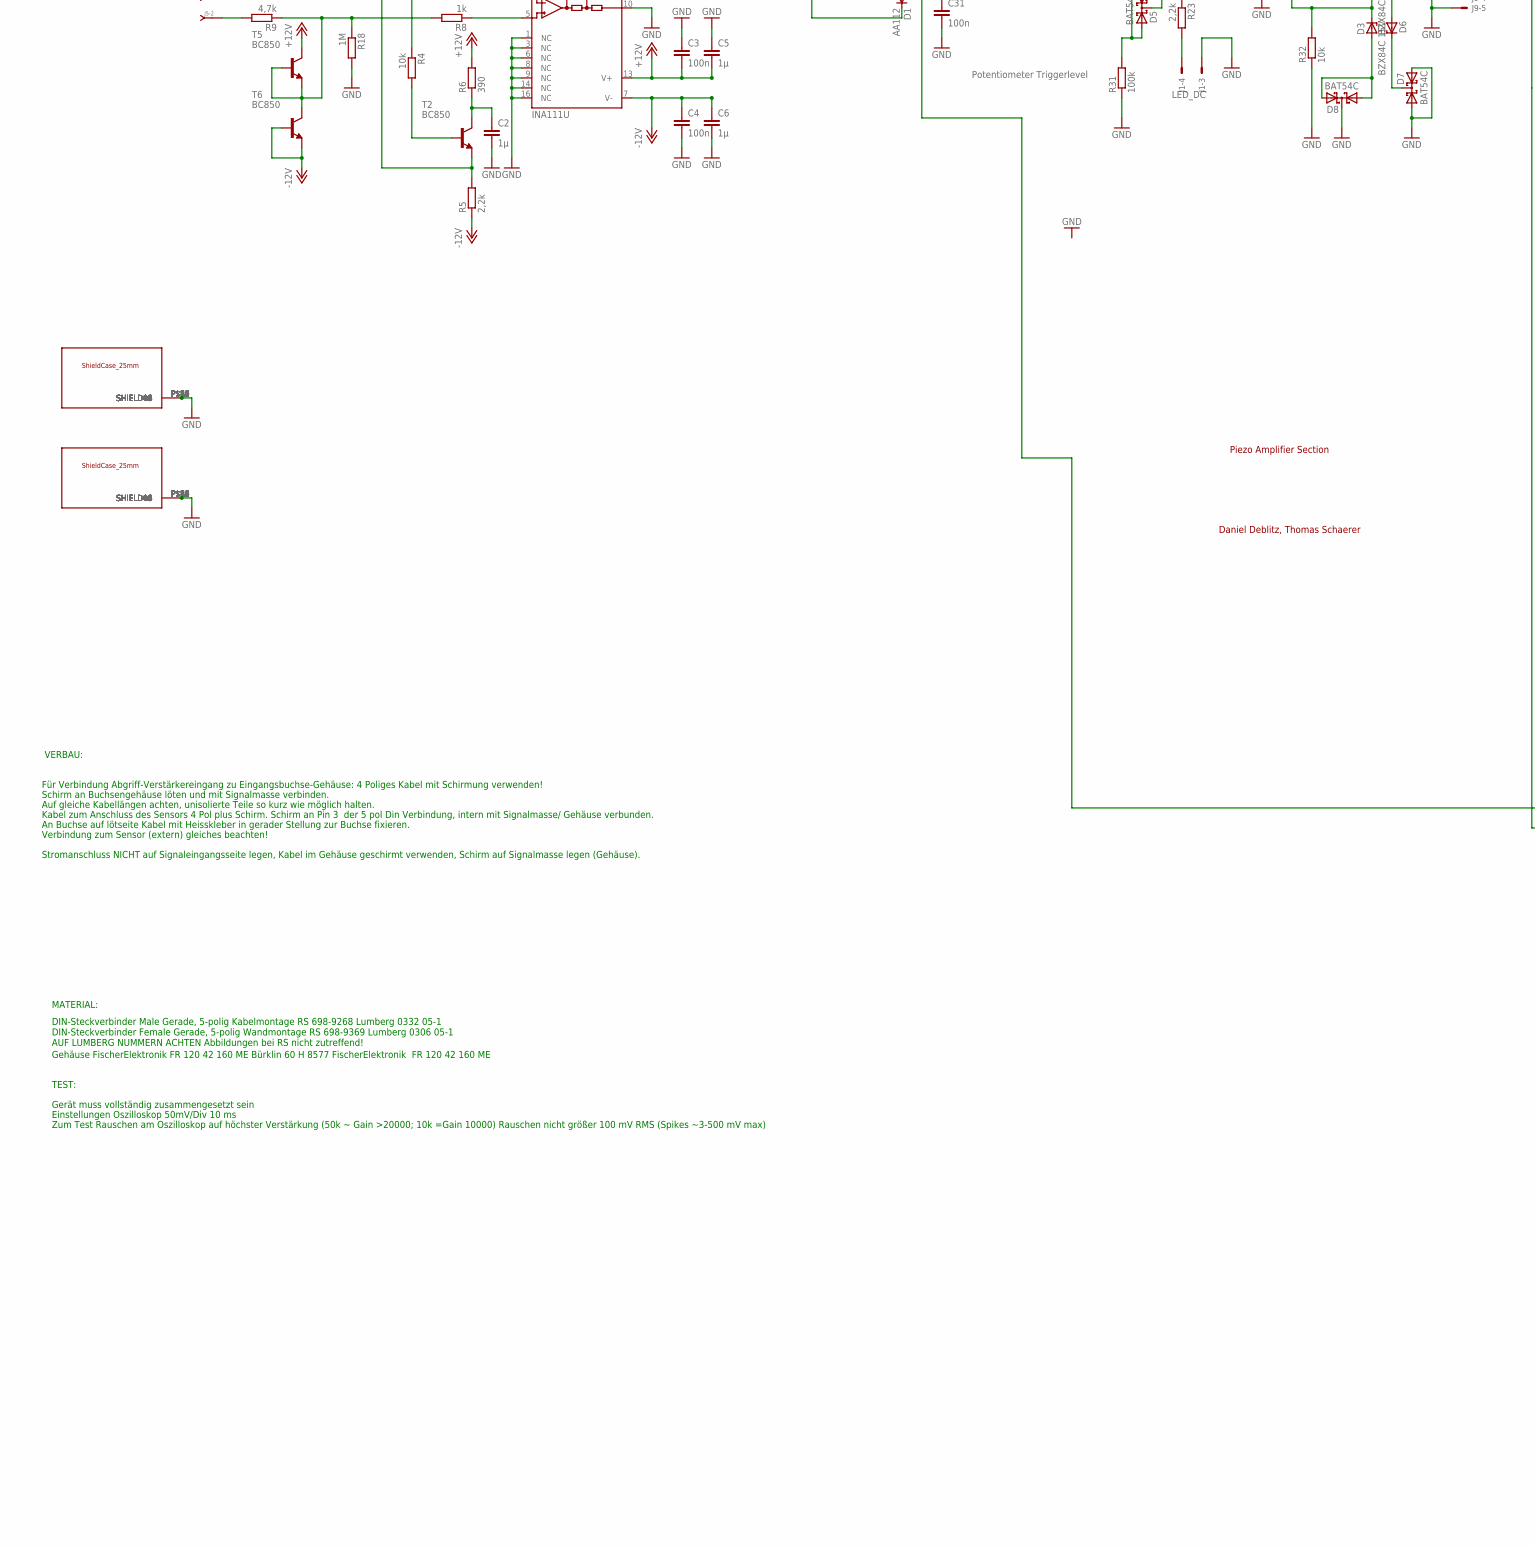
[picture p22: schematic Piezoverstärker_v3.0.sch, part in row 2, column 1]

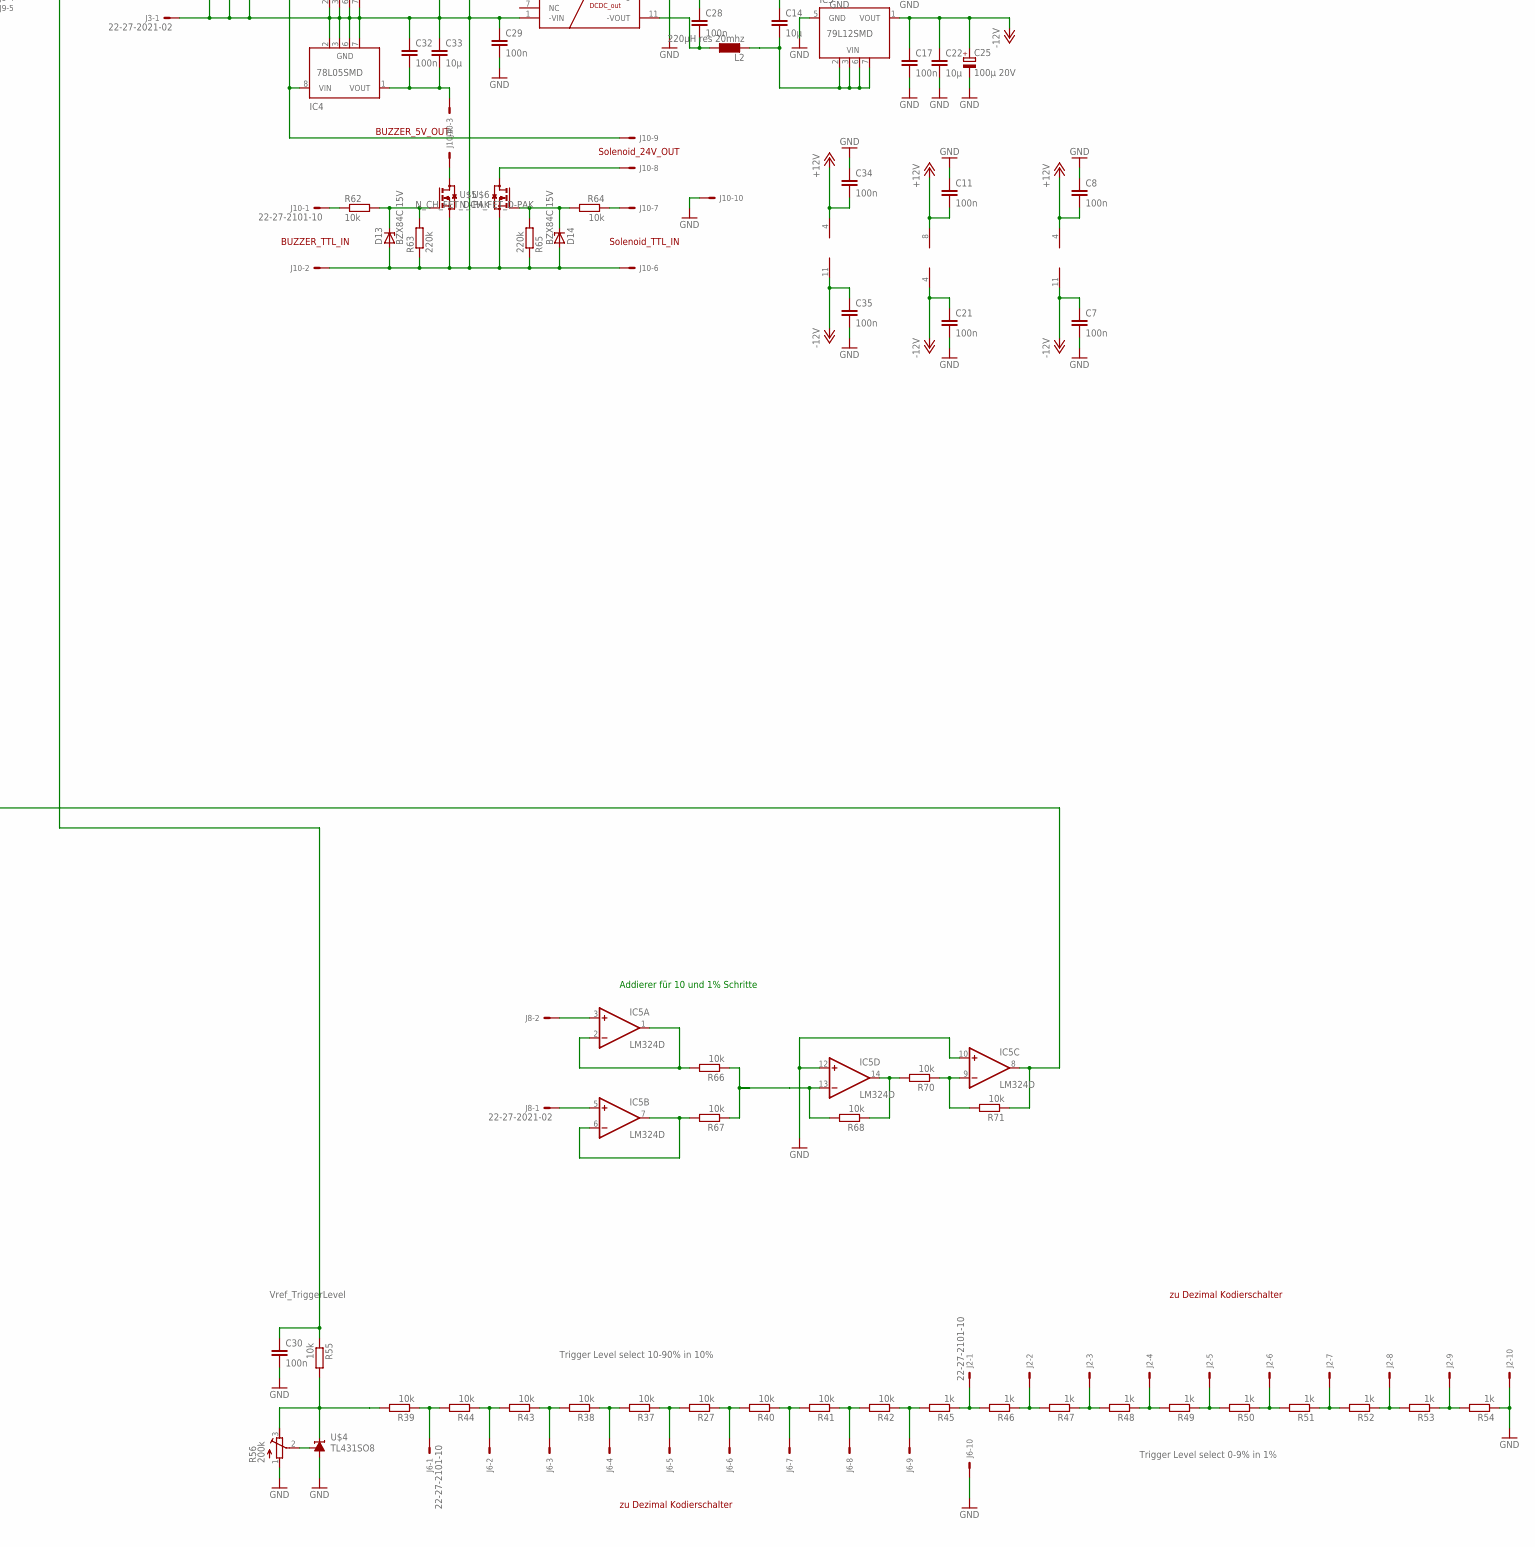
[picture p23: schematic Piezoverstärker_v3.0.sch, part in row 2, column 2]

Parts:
C1, C2, C5, C6: 1µ; C0805
C3, C4, C7, C8, C9, C11, C16, C17, C18, C19, C20, C21, C24, C27, C28, C29, C30, C31, C32, C34, C35, C36, C37, C39, C40, C42, C43, C45, C46, C48, C49, C51, C52, C54, C55, C57, C58, C60, C61, C63, C64, C66: 100n; C0805
C10, C38, C41, C44, C47, C50, C53, C56, C59, C62, C65: 3,3n; C0805
C12, C15, C25, C26: 100µ 20V; PANASONIC_E
C13, C14, C22, C23, C33: 10µ; C0805
D1, D2: AA112; DO07
D3, D6, D9, D10, D13, D14: BZX84C 15V; TO236
D4: ES2D; SMB
D5, D7, D8, D11, D12: BAT54C; SOT23
IC1: INA111U; SO16-1
IC2, IC5: LM324D; SO14
IC3: 79L12SMD; SO08
IC4: 78L05SMD; SO08
IC6: LM358D; SO08
IC7, IC8: 78L12SMD; SO08
J1, J9, J11, J14: 22-27-2051-05; 6410-05
J2, J6, J10: 22-27-2101-10; 6410-10
J3, J8: 22-27-2021-02; 6410-02
J4: DIFF_IN--; SIP-100-02-40
J5: DIFF_IN_+; SIP-100-02-40
J12, J13: 22-27-2081-08; 6410-08
L1, L2: 220µH res 20mhz; L4532P
R1, R4, R11, R12, R27, R29, R32, R36, R37, R38, R39, R40, R41, R42, R43, R44, R55, R62, R64, R66, R67, R68, R70, R71: 10k; R0805
R2, R5, R22, R23, R26: 2,2k; R0805
R3, R6, R78, R79, R80, R81, R82, R83, R84, R85, R86, R87, R88, R89, R90, R91, R92, R93, R94, R95, R96, R97, R98, R99, R100, R101: 390; R0805
R7, R8, R45, R46, R47, R48, R49, R50, R51, R52, R53, R54: 1k; R0805
R9, R10: 4,7k; R0805
R13, R14, R15, R16, R17, R31, R33: 100k; R0805
R18, R19: 1M; R0805
R24, R34, R56: 200k; RTRIM74W
R25, R35: 150; R0805
R28, R102, R103: 90k @ V=10; R0805
R30: 100; R0805
R57, R69, R75: 10k; RTRIM74W
R58, R72, R76: 1k; RTRIM74W
R59, R73, R77: 100; RTRIM74W
R60, R61, R74: 10; RTRIM74W
R63, R65: 220k; R0805
T1, T2, T3, T4, T5, T6: BC850; SOT23
U$1: MURATA_DCDC_NMA1215DC; MURRATA_NMA_DCDC
U$2, U$3: ABSCHIRMGEHäUSE_SMD_25MM
U$4: TL431SO8; SO08
U$5, U$6: N_CH_FET_D-PAK; TO252

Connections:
+12V: C3.2, C5.2, C8.2, C11.2, C16.1, C23.1, C26.+, C34.2, IC1.13 (V+), IC2.4 (V+), IC5.4 (V+), IC6.8 (V+), IC8.1 (VOUT), J1.1, R3.2, R6.2, T3.3 (C), T5.3 (C)
+12VDC_DIRTY: C13.1, C30.1, IC8.8 (VIN), L1.2, R55.1
-12V: C4.1, C6.1, C7.1, C17.1, C21.1, C22.1, C25.+, C35.1, IC1.7 (V-), IC2.11 (V-), IC3.1 (VOUT), IC5.11 (V-), IC6.4 (V-), R2.1, R5.1, T4.1 (B), T4.2 (E), T6.1 (B), T6.2 (E)
DIFF_+: R8.2, R9.1, R18.1, T5.1 (B), T5.2 (E), T6.3 (C)
DIFF_-: R7.2, R10.1, R19.2, T3.1 (B), T3.2 (E), T4.3 (C)
GND: C1.2, C2.2, C3.1, C4.2, C5.1, C6.2, C7.2, C8.1, C11.1, C13.2, C14.1, C16.2, C17.2, C21.2, C22.2, C23.2, C24.1, C25.-, C26.-, C27.2, C28.1, C29.2, C30.2, C31.2, C34.1, C35.2, D7.1 (A1), D7.2 (A2), D8.3 (CC), D11.1 (A1), D11.2 (A2), D12.3 (CC), IC1.1 (NC), IC1.3 (NC), IC1.6 (NC), IC1.8 (NC), IC1.9 (NC), IC1.10 (REF), IC1.14 (NC), IC1.16 (NC), IC2.3 (+IN), IC2.5 (+IN), IC3.5 (GND), IC5.10 (+IN), IC5.12 (+IN), IC8.2 (GND), IC8.3 (GND), IC8.6 (GND), IC8.7 (GND), J1.3, J2.10, J6.10, J9.2, J9.4, J9.5, J10.10, J12.7, R18.2, R19.1, R24.1 (E), R26.1, R29.1, R31.1, R32.1, R33.2, R34.1 (E), R36.1, R54.1, R56.1 (E), U$1.8 (0), U$2.P$1 (SHIELD00), U$2.P$2 (SHIELD01), U$2.P$3 (SHIELD02), U$2.P$4 (SHIELD03), U$2.P$5 (SHIELD04), U$2.P$6 (SHIELD05), U$2.P$7 (SHIELD06), U$2.P$8 (SHIELD07), U$2.P$9 (SHIELD08), U$2.P$10 (SHIELD09), U$2.P$11 (SHIELD10), U$2.P$12 (SHIELD11), U$2.P$13 (SHIELD12), U$2.P$14 (SHIELD13), U$2.P$15 (SHIELD14), U$2.P$16 (SHIELD15), U$2.P$17 (SHIELD16), U$2.P$18 (SHIELD17), U$2.P$19 (SHIELD18), U$2.P$20 (SHIELD19), U$3.P$1 (SHIELD00), U$3.P$2 (SHIELD01), U$3.P$3 (SHIELD02), U$3.P$4 (SHIELD03), U$3.P$5 (SHIELD04), U$3.P$6 (SHIELD05), U$3.P$7 (SHIELD06), U$3.P$8 (SHIELD07), U$3.P$9 (SHIELD08), U$3.P$10 (SHIELD09), U$3.P$11 (SHIELD10), U$3.P$12 (SHIELD11), U$3.P$13 (SHIELD12), U$3.P$14 (SHIELD13), U$3.P$15 (SHIELD14), U$3.P$16 (SHIELD15), U$3.P$17 (SHIELD16), U$3.P$18 (SHIELD17), U$3.P$19 (SHIELD18), U$3.P$20 (SHIELD19), U$4.2 (A)
unnamed: C1.1, R3.1, T1.3 (C)
unnamed: IC1.11 (OUT), IC1.12 (FB), R30.1
unnamed: R1.2, T1.1 (B)
unnamed: C12.-, IC1.2 (RG), R1.1
unnamed: C2.1, R6.1, T2.3 (C)
unnamed: IC1.5 (+IN), R8.1
unnamed: R4.2, T2.1 (B)
unnamed: R75.2 (S), R90.1
unnamed: IC1.4 (-IN), R7.1
unnamed: R75.3 (A), R79.2
unnamed: J4.2, R10.2
unnamed: J5.2, R9.2
unnamed: IC6.5 (+IN), R24.2 (S)
unnamed: C12.+, J13.8
unnamed: D1.A, D2.C, IC2.1 (OUT)
unnamed: D5.1 (A1), D5.2 (A2), IC2.8 (OUT), R31.2
unnamed: D2.A, R11.2, R13.1
unnamed: J9.3, R25.1
unnamed: C28.2, L2.1, U$1.11 (-VOUT)
unnamed: R14.2, R15.1
unnamed: R16.2, R17.1
unnamed: IC2.7 (OUT), IC2.10 (+IN), J12.8, R17.2, R22.1, R33.1
unnamed: C9.2, C10.2, C37.2, C38.2, C40.2, C41.2, C43.2, C44.2, C46.2, C47.2, C49.2, C50.2, C52.2, C53.2, C55.2, C56.2, C58.2, C59.2, C61.2, C62.2, C64.2, C65.2, IC2.6 (-IN), R13.2, R15.2, R16.1
unnamed: C9.1, C10.1, C36.2
unnamed: C45.1, J11.4
unnamed: C37.1, C38.1, C39.2
unnamed: R76.3 (A), R78.2
unnamed: R77.3 (A), R80.2
unnamed: J1.5, R22.2
unnamed: J1.4, R23.2
unnamed: R39.2, R55.2, R56.3 (A), U$4.1 (C)
unnamed: D5.3 (CC), R23.1, R24.3 (A)
unnamed: D3.A, D8.1 (A1), D8.2 (A2)
unnamed: D3.C, D6.A, IC6.6 (-IN), IC6.7 (OUT), R25.2, R32.2
unnamed: C27.1, L1.1, U$1.9 (+VOUT)
unnamed: J2.9, R53.1, R54.2
unnamed: C15.+, C18.1, D4.C, IC4.8 (VIN), IC7.8 (VIN), J3.2, J10.9
unnamed: C19.1, C20.1, IC7.1 (VOUT), U$1.14 (+VIN)
unnamed: D1.C, IC2.2 (-IN), R11.1, R12.2
unnamed: D6.C, D7.3 (CC)
unnamed: D9.C, D10.A, IC6.1 (OUT), IC6.2 (-IN), R35.2, R36.2
unnamed: IC6.3 (+IN), R34.2 (S)
unnamed: J9.1, R35.1
unnamed: J1.2, R26.2
unnamed: D9.A, D12.1 (A1), D12.2 (A2)
unnamed: D10.C, D11.3 (CC)
unnamed: IC2.13 (-IN), R28.2, R29.2, R102.1
unnamed: C42.1, J11.3
unnamed: IC2.14 (OUT), R12.1, R14.1, R34.3 (A), R103.2
unnamed: J2.8, R52.1, R53.2
unnamed: C24.2, IC2.12 (+IN), R30.2
unnamed: J2.7, R51.1, R52.2
unnamed: J2.6, R50.1, R51.2
unnamed: J2.5, R49.1, R50.2
unnamed: J2.4, R48.1, R49.2
unnamed: J2.3, R47.1, R48.2
unnamed: J2.2, R46.1, R47.2
unnamed: J2.1, R45.1, R46.2
unnamed: J6.9, R42.1, R45.2
unnamed: J6.8, R41.1, R42.2
unnamed: J6.7, R40.1, R41.2
unnamed: J6.6, R27.1, R40.2
unnamed: J6.5, R27.2, R37.1
unnamed: J6.4, R37.2, R38.1
unnamed: J6.3, R38.2, R43.1
unnamed: J6.2, R43.2, R44.1
unnamed: J6.1, R39.1, R44.2
unnamed: R56.2 (S), U$4.8 (FB)
unnamed: C40.1, C41.1, C42.2
unnamed: C39.1, J11.2
unnamed: C43.1, C44.1, C45.2
unnamed: C36.1, J11.1
unnamed: IC1.15 (RG), R4.1, R57.1 (E), R58.1 (E), R59.1 (E), R60.1 (E), R61.1 (E), R69.1 (E), R72.1 (E), R73.1 (E), R74.1 (E), R75.1 (E), R76.1 (E), R77.1 (E), R78.1, R79.1, R80.1, R81.1, R82.1, R83.1, R84.1, R85.1, R86.1, R87.1, R88.1, R89.1
unnamed: C32.2, C33.2, IC4.1 (VOUT), J10.3
unnamed: J10.4, U$5.3 (D)
unnamed: J10.1, R62.1
unnamed: D13.C, R62.2, R63.2, U$5.1 (G)
unnamed: J10.8, U$6.3 (D)
unnamed: J10.7, R64.1
unnamed: D14.C, R64.2, R65.2, U$6.1 (G)
unnamed: IC5.6 (-IN), IC5.7 (OUT), R67.2
unnamed: IC5.1 (OUT), IC5.2 (-IN), R66.2
unnamed: IC5.5 (+IN), J8.1
unnamed: IC5.3 (+IN), J8.2
unnamed: C46.1, C47.1, C48.2
unnamed: IC5.13 (-IN), R66.1, R67.1, R68.2
unnamed: IC5.14 (OUT), R68.1, R70.2
unnamed: IC5.9 (-IN), R70.1, R71.2
unnamed: C48.1, J11.5
unnamed: C49.1, C50.1, C51.2
unnamed: C51.1, J12.1
unnamed: C52.1, C53.1, C54.2
unnamed: C54.1, J12.2
unnamed: C55.1, C56.1, C57.2
unnamed: C57.1, J12.3
unnamed: C58.1, C59.1, C60.2
unnamed: C60.1, J12.4
unnamed: C61.1, C62.1, C63.2
unnamed: C63.1, J12.5
unnamed: C64.1, C65.1, C66.2
unnamed: C66.1, J12.6
unnamed: R76.2 (S), R91.1
unnamed: R77.2 (S), R92.1
unnamed: R69.2 (S), R93.1
unnamed: R72.2 (S), R94.1
unnamed: R73.2 (S), R95.1
unnamed: R74.2 (S), R96.1
unnamed: R57.2 (S), R97.1
unnamed: R58.2 (S), R98.1
unnamed: R59.2 (S), R99.1
unnamed: R60.2 (S), R100.1
unnamed: R61.2 (S), R101.1
unnamed: J14.1, R90.2
unnamed: J14.2, R91.2
unnamed: J14.3, R92.2
unnamed: J14.4, R93.2
unnamed: J14.5, R94.2
unnamed: J13.1, R95.2
unnamed: J13.2, R96.2
unnamed: J13.3, R97.2
unnamed: J13.4, R98.2
unnamed: J13.5, R99.2
unnamed: J13.6, R100.2
unnamed: J13.7, R101.2
unnamed: R28.1, R102.2, R103.1
unnamed: R69.3 (A), R81.2
unnamed: R72.3 (A), R82.2
unnamed: R73.3 (A), R83.2
unnamed: R74.3 (A), R84.2
unnamed: R57.3 (A), R85.2
unnamed: R58.3 (A), R86.2
unnamed: R59.3 (A), R87.2
unnamed: R60.3 (A), R88.2
unnamed: R61.3 (A), R89.2
SCHIR_DIFF_+: J5.1, R5.2, T2.2 (E)
SCHIR_DIFF_-: J4.1, R2.2, T1.2 (E)
T1: C15.-, C18.2, C19.2, C20.2, C29.1, C32.1, C33.1, D4.A, D13.A, D14.A, IC4.2 (GND), IC4.3 (GND), IC4.6 (GND), IC4.7 (GND), IC7.2 (GND), IC7.3 (GND), IC7.6 (GND), IC7.7 (GND), J3.1, J10.2, J10.6, R63.1, R65.1, U$1.1 (-VIN), U$5.2 (S), U$6.2 (S)
T2: C14.2, IC3.2 (VIN), IC3.3 (VIN), IC3.6 (VIN), IC3.7 (VIN), L2.2
TRIGGER_LEVELSET_IN: C31.1, IC2.9 (-IN), IC5.8 (OUT), R71.1

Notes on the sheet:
Gleichrichter mit schaltbarer Glättung
ESD Protect
Schirmtreiber
Potentiometer Triggerlevel
Output Level
Gainswitch
ESD
Diffamp
Gain-Schalter
Gleichrichter
Trigger
Abgriff Umschaltung
HP Filter
Schalter Glättung
Trigger-Level
Ausgangsentkopplung
Ausgang-Level
OUT
PINOUT DER SPANNUNGSREGLER BEACHTEN!
Zum Test Rauschen am Oszilloskop auf höchster Verstärkung (50k ~ Gain >20000; 10k =Gain 10000) Rauschen nicht größer 100 mV RMS (Spikes ~3-500 mV max)
Gerät muss vollständig zusammengesetzt sein
Für Verbindung Abgriff-Verstärkereingang zu Eingangsbuchse-Gehäuse: 4 Poliges Kabel mit Schirmung verwenden!
Kabel zum Anschluss des Sensors 4 Pol plus Schirm. Schirm an Pin 3 der 5 pol Din Verbindung, intern mit Signalmasse/ Gehäuse verbunden.
Einstellungen Oszilloskop 50mV/Div 10 ms
Auf gleiche Kabellängen achten, unisolierte Teile so kurz wie möglich halten.
An Buchse auf lötseite Kabel mit Heisskleber in gerader Stellung zur Buchse fixieren.
TEST:
MATERIAL:
Schirm an Buchsengehäuse löten und mit Signalmasse verbinden.
Verbindung zum Sensor (extern) gleiches beachten!
DIN-Steckverbinder Male Gerade, 5-polig Kabelmontage RS 698-9268 Lumberg 0332 05-1 DIN-Steckverbinder Female Gerade, 5-polig Wandmontage RS 698-9369 Lumberg 0306 05-1 AUF LUMBERG NUMMERN ACHTEN Abbildungen bei RS nicht zutreffend!
VERBAU:
Gehäuse FischerElektronik FR 120 42 160 ME Bürklin 60 H 8577 FischerElektronik FR 120 42 160 ME
Stromanschluss NICHT auf Signaleingangsseite legen, Kabel im Gehäuse geschirmt verwenden, Schirm auf Signalmasse legen (Gehäuse).
Gleichrichter Glättung
LED_Trigger
LED_DC
Switch_OUT_Rect/Trig
Power_ON_LED
Gain select 2

Board: 2 copper layers, 216 parts (0 on the bottom side), 145 nets, no tracks yet.

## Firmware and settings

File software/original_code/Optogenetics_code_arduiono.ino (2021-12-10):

#include <digitalWriteFast.h>

int mirrorinputPin = 9;      // digital input connected to AO1 of Dev2 that sends signal to Pockels cell.
//This signal is LOW when the mirrors are turning, hence our need to invert
//Make sure that Power is set to 100% in the Power Control Panel

int gatePin = 7;      // gating signal from labjack connected connected to digital in 7.  Tells us when LED should be driven
int outputPin = 13;   // output connected tp PWM pin 13
int gateval = 0;
int mirrorval = 0;

bool goingdown = true;
bool trippedup = false;
bool trippeddown = false;


#define FASTADC 1

// defines for setting and clearing register bits
#ifndef cbi
#define cbi(sfr, bit) (_SFR_BYTE(sfr) &= ~_BV(bit))
#endif
#ifndef sbi
#define sbi(sfr, bit) (_SFR_BYTE(sfr) |= _BV(bit))
#endif



void setup()
{
  pinMode(outputPin, OUTPUT);
  pinMode(gatePin, INPUT);        // sets the digital pin 7 as input
  pinMode(mirrorinputPin, INPUT);  //sets digital pin 9 as input   
  digitalWrite(outputPin, LOW); 
}


void loop() 
{
 gateval=digitalRead(gatePin);
 if(gateval==HIGH)
  {
   mirrorval = digitalRead(mirrorinputPin); 
   if(mirrorval==HIGH)
    {
      digitalWrite(outputPin, LOW);
    }
  if(mirrorval==LOW)
    {
      digitalWrite(outputPin, HIGH);
    }
  }
 
 if(gateval==LOW)
  {
    digitalWrite(outputPin, LOW);
  }
  
}  

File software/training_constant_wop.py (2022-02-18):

import utime
from machine import Pin
from machine import PWM
from machine import SoftI2C

import urandom
import time

class Task1:
    def __init__(self,testing=0):
        #set different analog voltage out for monitoring what was on/when
        self.stimIndValue = 3.5
        self.stimIndValue = self.volt2Int(volt = self.stimIndValue)
        self.lickSensor1Ind = 1.0
        self.lickSensor1Ind = self.volt2Int(volt = self.lickSensor1Ind)
        self.solenoid1Ind = 0.5
        self.solenoid1Ind = self.volt2Int(volt = self.solenoid1Ind)
        self.lickSensor2Ind = 2.5
        self.lickSensor2Ind = self.volt2Int(volt = self.lickSensor2Ind)
        self.solenoid2Ind = 2.0
        self.solenoid2Ind = self.volt2Int(volt = self.solenoid2Ind)
        
        #self.monitor1 = 998
        #self.monitor2 = 999
        self.i2c = SoftI2C(scl=Pin(32), sda=Pin(33), freq=100000)

        #self.i2c=SoftI2C(scl=Pin(9), sda=Pin(10))
        self.i2cAdd = self.i2c.scan()
        self.writeToDac(value=0x60)
        #write 0 volts to the DAC
        self.writeToDac(value=0)

        # set the "direction" of the ports
        self.lickSensor1Pin = Pin(5, Pin.IN, Pin.PULL_DOWN)
        self.lickSensor2Pin = Pin(18, Pin.IN, Pin.PULL_DOWN)
        
        #self.actuator1ForwardPin = Pin(15, Pin.OUT)
        #self.actuator1BackwardPin = Pin(2, Pin.OUT)
        self.servo1Pin = PWM(Pin(2), freq=50)
        self.servo2Pin = PWM(Pin(15), freq=50)
        
        self.servoMax = 45
        self.servoMin = 25
        
        
        self.solenoid1Pin = Pin(16, Pin.OUT)
        self.solenoid11Pin = Pin(17, Pin.OUT)
        self.solenoid2Pin = Pin(19, Pin.OUT)
        self.solenoid22Pin = Pin(21, Pin.OUT)

        self.stimTriggerPin = Pin(23, Pin.OUT)
        self.monitorSidePin = Pin(22,Pin.OUT)
        self.twopPin = Pin(14, Pin.OUT)
        
        
        ##self.monitor1Pin = Pin(self.monitor1, Pin.OUT)
        ##self.monitor2Pin = Pin(self.monitor2, Pin.OUT)


        #turn everything off at the beginning
        #self.actuator1ForwardPin.value(0)
        #self.actuator1BackwardPin.value(0)
        self.solenoid1Pin.value(0)
        self.solenoid11Pin.value(0)
        self.solenoid2Pin.value(0)
        self.solenoid22Pin.value(0)
        self.stimTriggerPin.value(0)

        #store what the animal did
        #1 = correct lick spout 1
        #2 = correct lick spout 2
        #3 = incorrect lick spout 1
        #4 = incorrect lick spout 2
        #0 = no response
        self.responseStatus = 0
        

        self.twopPin.value(0)
        self.monitorSidePin.value(0)
        ##self.monitor1Pin.off()
        ##self.monitor2Pin.off()


        # time/interval variables
        self.iti = 10000  # inter trial interval in ms
        self.baseline = 10000  # time to wait at the beginning of session to record baseline
        self.stimDuration = 3000  # stimulus presentation duration
        self.responseWindowDuration = 2000  # time window to respond after stim presentation
        #self.actuatorForwardDuration = 300 #how much time the actuator spends moving forward
        #self.actuatorBackwardDuration = 300 #how much time the actuator spends moving forward
        self.reward1Duration = 100  # duration the solenoid valves will stay in open state, 
                                    #which ends up being the amount of water offered
        self.reward2Duration = 100  # duration the solenoid valves will stay in open state,
        ##                          #which ends up being the amount of water offered
        self.moveBackDelay = 700
        self.numberOfTrials = 100 # the number of trials that will be presented to the animals
        
        
        
        if testing==1:
            self.iti = 2500  # inter trial interval in ms
            self.baseline = 1000  # time to wait at the beginning of session to record baseline
            self.stimDuration = 2500  # stimulus presentation duration
            self.responseWindowDuration = 2000  # time window to respond after stim presentation
            #self.actuatorForwardDuration = 300 #how much time the actuator spends moving forward
            #self.actuatorBackwardDuration = 300 #how much time the actuator spends moving forward
            self.reward1Duration = 100  # duration the solenoid valves will stay in open state, 
            self.reward2Duration = 100  # duration the solenoid valves will stay in open state, 
            self.moveBackDelay = 0
            self.numberOfTrials = 30 # the number of trials that will be presented to the animals
        
        #self.trial = 0  # the current trial

        #create array with indication on which monitor should be on.
        #this should be a pseudorandom way
        #set a seed so that all the time the random order is the same 
        #urandom.seed(42)

        self.monitorOrder = [0]*self.numberOfTrials
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

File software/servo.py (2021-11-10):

from machine import PWM
import math

# originally by Radomir Dopieralski http://sheep.art.pl
# from https://bitbucket.org/thesheep/micropython-servo

class Servo:
    """
    A simple class for controlling hobby servos.
    Args:
        pin (machine.Pin): The pin where servo is connected. Must support PWM.
        freq (int): The frequency of the signal, in hertz.
        min_us (int): The minimum signal length supported by the servo.
        max_us (int): The maximum signal length supported by the servo.
        angle (int): The angle between the minimum and maximum positions.
    """
    def __init__(self, pin, freq=50, min_us=600, max_us=2400, angle=180):
        self.min_us = min_us
        self.max_us = max_us
        self.us = 0
        self.freq = freq
        self.angle = angle
        self.pwm = PWM(pin, freq=freq, duty=0)

    def write_us(self, us):
        """Set the signal to be ``us`` microseconds long. Zero disables it."""
        if us == 0:
            self.pwm.duty(0)
            return
        us = min(self.max_us, max(self.min_us, us))
        duty = us * 1024 * self.freq // 1000000
        self.pwm.duty(duty)

    def write_angle(self, degrees=None, radians=None):
        """Move to the specified angle in ``degrees`` or ``radians``."""
        if degrees is None:
            degrees = math.degrees(radians)
        degrees = degrees % 360
        total_range = self.max_us - self.min_us
        us = self.min_us + total_range * degrees // self.angle
        self.write_us(us)

    © 2021 GitHub, Inc.
    Terms
    Privacy
    Security
    Status
    Docs

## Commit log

2021-04-08 initial update of information
    [Lecksensor mit Halter.x_t, Piezoverstärker_v3.0.sch]
2021-05-10 work on code and list of materials
    [Piezoverstärker_v3.0-2021-05-06-19-29-28.sch, Piezoverstärker_v3.0.brd, Piezoverstärker_v3.0.kicad_pcb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]
2021-05-17 start building licksensors fit
    [actuator_holder.scad, actuator_holder.stl, licksensor_holder.scad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]
2021-05-19 changes to designs
    [licksensor_holder.scad, licksensor_holder.stl]
2021-05-27 work on tests and 3D printed parts
    [licksensor_holder.scad, licksensor_holder.stl]
2021-05-28 solved solenoid bugs
2021-06-04 fix bugs, update code
    [tasks.py]
2021-06-15 add code to create CSV file containing monitor side and code to update EEPROM on DAC board
    [actuator_holder.stl, licksensor_holder.scad, licksensor_holder.stl]
2021-07-07 last changes leading to 1st working version on setup
    [2021-Jul-06-14-55-47.csv, 2021-Jul-06-15-23-21.csv, 2021-Jul-06-15-31-04.csv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]
2021-08-18 add Sina's ppt with the task schematic and photos, as well as update code to print correct/incorrect trial numbers
    [tasks.py]
2021-10-22 start working on the servo implementation
    [gear_test.stl, linear_actuator_holder.scad, linear_actuator_holder.stl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]
2021-10-28 work on new movement system for spouts
    [gear_test.3mf, linear_rail_test.3mf, servo_actuator_holder.scad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]
2021-11-02 more work on servo fit
    [gear_test.3mf, gear_test.stl, licksensor_holder.stl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]
2021-11-03 add sensor holder
    [linear_rail_test.3mf, servo_actuator_holder.scad]
2021-11-10 update code and models for servo actuator
    [linear_rail_test.3mf, pole_fit.3mf, servo_actuator_holder.3mf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]
2021-12-07 update python conde and clean up repo
    [2021-Jul-06-14-55-47.csv, 2021-Jul-06-15-23-21.csv, 2021-Jul-06-15-31-04.csv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]
2021-12-10 clean up repo
    [2021-Jul-06-14-55-47.csv, 2021-Jul-06-15-23-21.csv, 2021-Jul-06-15-31-04.csv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]
2021-12-10 clean up repo and create code to upload files to micropython board via notebook
    [2021-Jul-06-14-55-47.csv, 2021-Jul-06-15-23-21.csv, 2021-Jul-06-15-31-04.csv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]
2021-12-13 implement a not so good way to save files on host computer
    [test.csv]
2022-01-13 update code and jupyter notebooks
    [test.csv]
2022-02-18 update templates
    [test.csv]
2022-02-18 add training with constant wop
    [test.csv]
2022-08-23 split 3D models into useable individual parts
    [LS_Gehäuse_T1.stp, Lecksensor mit Halter.obj, Lecksensor mit Halter.stp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]
2022-10-21 update 3D models for the piezo holder
    [test-Cut001.amf]

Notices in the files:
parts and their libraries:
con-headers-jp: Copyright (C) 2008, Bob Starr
